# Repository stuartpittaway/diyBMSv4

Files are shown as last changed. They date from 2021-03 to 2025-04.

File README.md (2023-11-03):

# diyBMS v4

Version 4 of the diyBMS

Do it yourself battery management system for Lithium ion battery packs/cells

More discussion [Open Energy Monitor Forum](https://community.openenergymonitor.org/c/hardware/diybms/53)

If you are looking for version 3 (obsolete) of this project take a look [here](https://github.com/stuartpittaway/diyBMS)

THIS REPOSITORY CONTAINS THE HARDWARE FOR THE SYSTEM

# Videos on how to use and build

[YouTube playlist](https://youtube.com/playlist?list=PLHhwQCDPuRcZW3u0jJucsiCCsUbNbMy-c) for DIYBMS videos

[Building & ordering the PCB from JLCPCB](https://youtu.be/E1OS0ZOmOT8)

If you order a PCB, please use my affiliate link to help support this project [JLCPCB](https://jlcpcb.com/RSZ)

# Support

If you find the BMS useful, please consider buying me a beer, check out Patron for more information

https://patreon.com/StuartP

# HARDWARE

This repository contains the hardware designs, generally in KiCad format.  Unless you are changing the design, you don't need to use/install KiCad, just use the precompiled files.

The folder structure in the repository contains:

## Controller Designs
* ControllerCircuit - ESP32 controller board (newest design)
* ESP8266ControllerCircuit - [legacy] the circuit board for the legacy ESP8266 based controller

## Modules for Controller
* ModuleV490-AllInOne - Latest multi cell monitoring solution, recommended for 8 to 16S cell configurations.  No balancing, requires ModuleV490-PassiveBal passive balancer daughterboard if this is needed.
* ModuleV490-PassiveBal - daughter board for the V490 multi-cell monitoring solution, provides 200mA per cell balance current, heatsink and fan control.
* ModuleV450 - the latest SINGLE module design, using ATTINY1624 chip. Recommended for both hand soldering or mass production
* ModuleV440 - [legacy] the module circuit board V4.40, final board using ATTINY841 chip
* ModuleV400 - [legacy] the module circuit board V4.00, designed for easier hand soldering (larger parts)
* ModuleV421 - [legacy] the module circuit board V4.21, designed for mass production using JLCPCB assembly service

If you use this coupon code when you place a JLCPCB order

JLC-Stuart

and this link

https://jlcpcb.com/RSZ

you will get a discount and I get a very small amount of credit for every 30 orders, which helps to support the cost of prototyping new designs and adding new features.

### ESP32 Controller 

The latest version of the controller uses an ESP32 and supports CANBUS, RS485, SD CARD logging, relays, SSR outputs, multiple inputs, AVR programmer and much more.

Although the hardware is complete, not all features are usable from the software, this will be developed and improved over time to make use of the hardware.

[Bill of Materials](./ControllerCircuit/ComponentListBOM.md)

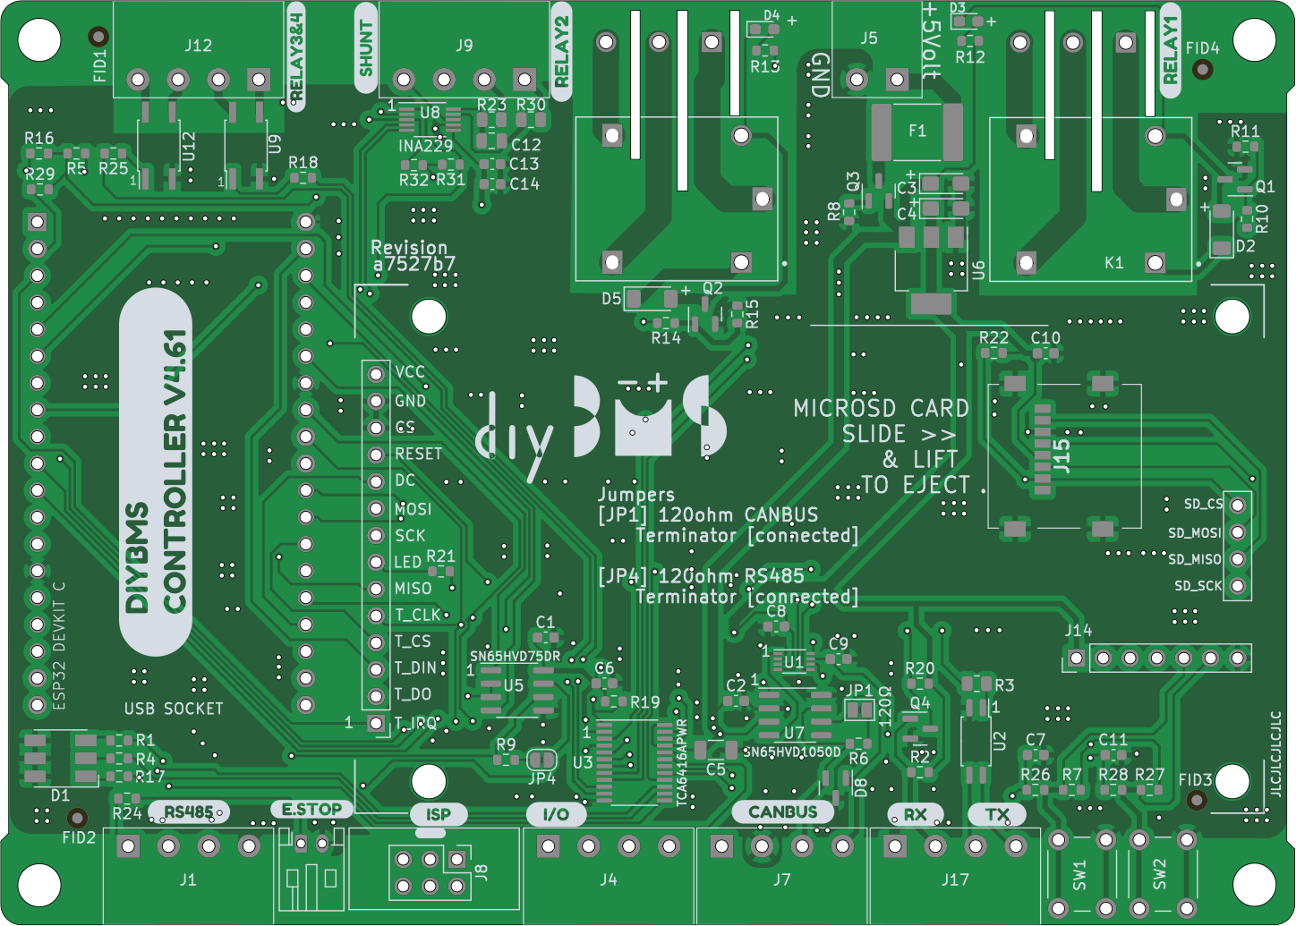
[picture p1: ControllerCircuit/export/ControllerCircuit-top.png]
circuit board


### Module V4.50

The latest version of the module hardware uses the ATTINY1624 chip - part of the tinyAVR2 range.

This board requires an UPDI programmer/device - see the instructions in the code repository for how to program the boards once built.

The parts are no smaller than 0805 size (about 2mm!) which is probably the smallest size you want to attempt to hand solder.

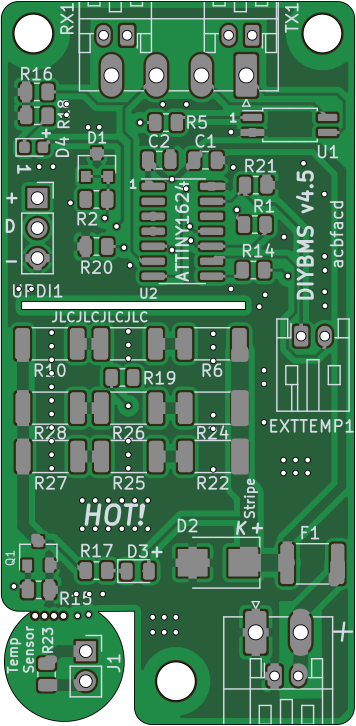
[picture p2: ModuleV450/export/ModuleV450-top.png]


Specifications are similar to the V4.40 board.

### Module V4.40

V4.40 is the last board to use the ATTINY841 chip - V4.50 is the newest design if you are starting fresh.

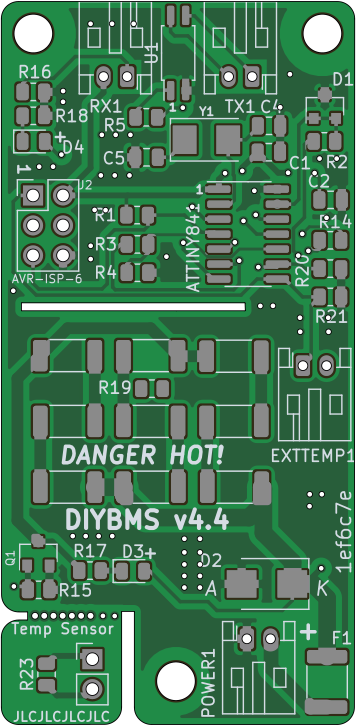
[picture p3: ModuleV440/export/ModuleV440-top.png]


In addition, the hardware has a higher balance current, fuse and TVS diode to help with voltage spikes.  
Most importantly, an external crystal has been added to the micro controller (attiny841) which means the device is more reliable in low voltage situations.

The balance current for V4.40 modules is as follows:
* 1.27A at 4.2V (5.35W)
* 1.21A at 4.0V (4.84W)
* 1.13A at 3.75V (4.26W)

The module is physically larger than previous modules, this aids heat dispersal but also features a "snap off" external temperature daughter board for use in cell temperature monitoring.

You will also need to order [these parts](./ModuleV440/HandAssemblyParts.md)

# CODE/SOFTWARE

Software and code for the modules and controller can now be found in a seperate repo

For the latest controller (ESP32)
[diyBMSv4ESP32](https://github.com/stuartpittaway/diyBMSv4ESP32)

For the legacy controller (ESP8266)
[diyBMSv4Code](https://github.com/stuartpittaway/diyBMSv4Code)

# WARNING

This is a DIY product/solution so don’t use this for safety critical systems or in any situation where there could be a risk to life.  

There is no warranty, it may not work as expected or at all.

The use of this project is done so entirely at your own risk.  It may involve electrical voltages which could kill - if in doubt, seek help.

The use of this project may not be compliant with local laws or regulations - if in doubt, seek help.

# License

This work is licensed under a Creative Commons Attribution-NonCommercial-ShareAlike 2.0 UK: England & Wales License.

https://creativecommons.org/licenses/by-nc-sa/2.0/uk/

You are free to:
* Share — copy and redistribute the material in any medium or format
* Adapt — remix, transform, and build upon the material
The licensor cannot revoke these freedoms as long as you follow the license terms.

Under the following terms:
* Attribution — You must give appropriate credit, provide a link to the license, and indicate if changes were made. You may do so in any reasonable manner, but not in any way that suggests the licensor endorses you or your use.
* Non-Commercial — You may not use the material for commercial purposes.
* ShareAlike — If you remix, transform, or build upon the material, you must distribute your contributions under the same license as the original.
* No additional restrictions — You may not apply legal terms or technological measures that legally restrict others from doing anything the license permits.

Notices:
You do not have to comply with the license for elements of the material in the public domain or where your use is permitted by an applicable exception or limitation.

No warranties are given. The license may not give you all of the permissions necessary for your intended use. For example, other rights such as publicity, privacy, or moral rights may limit how you use the material.

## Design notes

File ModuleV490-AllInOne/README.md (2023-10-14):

# DIYBMS All-in-one 16S monitoring board

This is the hardware for the (up to) 16S monitoring board.

This monitoring board replaces the individual cell monitoring boards used in the DIYBMS solution.  Several monitoring boards can be daisy-chained together to form larger battery packs.

You still require a DIYBMS ESP32 controller for this board to operate.

It uses an [STM32F030K6T6](https://www.st.com/en/microcontrollers-microprocessors/stm32f030k6.html) chip, with 32K flash and 4K RAM.

**WARNING**: This hardware is considered experimental & prototype, use at your own risk - it may not work as intended or at all.

## Background Information
### Software
The software for this board is available pre-compiled.  See this [link for details](https://github.com/stuartpittaway/diyBMSv4ESP32/tree/all-in-one/STM32All-In-One#readme)

Details are in the README on programming the STM32 chip for this PCB.

### KiCAD 7
This design uses KiCAD version 7.0.5.  Use the same or newer version for editing and viewing the files.  You don't need to install KiCAD if you just wish to build/order one.

### JLCPCB
The files in this repository will create a PCB and design files suitable for "almost" full construction at JLCPCB.  Some manual soldering will still be required for the connectors and cabling.

Look inside the "export" folder for the relevant production files.  You will need these files for the construction:

* module_16s_gerbers.zip
* Module_16S_bom_jlc.csv
* Module_16S_cpl_jlc.csv

Support this project by using JLCPCB referral link
https://jlcpcb.com/RSZ
when registering for the first time.

# READ THIS FIRST - IMPORTANT

Before construction of the PCB you must determine what battery cells you wish to monitor and a suitable cell voltage range.

The PCB design has options for two voltage ranges, determined by parts U2 and U6.  *ONLY ONE OF THESE CHIPS MUST BE FITTED*

The design uses a MAX14921 chip, this has a maximum of 16 cells and **65V** total battery voltage - do not exceed.

## LIFEPO4 cells up to 4.00V maximum

Use part U2, a Microchip voltage reference "MCP1501-40E/SN".  This is a 4.096V ±0.1% reference chip.

This part is available on JLCPCB as part number C1575589.

The pick and place file (CPL file) contains the part placement for this chip by default.  No further changes are required, except to double-check the order screens from JLCPCB.

Do not install part U6.

*This option has been tested by the author as working*

## Cell voltages up to 4.50V maximum

This is all 18650 style cell voltage chemistry - normally with a maximum of 4.25V.  This configuration can also be used with LIFEPO4 cells with voltages below 4.50V.

Use part U6, a Microchip voltage reference "MCP1502T-45E/CHY".   This is a 4.500V ±0.1% reference chip.

This part is NOT available from JLCPCB.  This part must be obtained from [other sources](https://www.digikey.co.uk/en/products/detail/microchip-technology/MCP1502T-45E-CHY/16549208) and **MANUALLY** soldered onto the board.  Note this is a very small chip (SOT-23-6) and difficult to solder.

Edit the pick and place (CPL file) before upload to JLCPCB to remove the line marked "U2".

Do not install part U2.

*This option has NOT been tested by the author, please feedback if you decide to experiment*

## BATTERY VOLTAGES ABOVE 24V & MINIMUM BELOW 12V

If you have an unusual Lithium cell chemistry where the maximum battery voltage is ABOVE 24V and the lowest is BELOW 12V, this monitoring board is not suitable.

## BATTERY VOLTAGES BELOW 13V (MINIMUM)

If you are building a battery whos voltage can go BELOW 13V, which typically includes 4S or 5S cell configurations.  

For example, 4S LIFEPO4 setup voltage range: 4x2.5V= 10V minimum, 4x3.65V=14.6V maximum.

Parts of the BMS circuit are not required for a battery's whos voltage can go below 13V and **must** be ommitted.  These parts operate the step-down regulator normally required for higher voltages, such as an 8S or 16S setup.   The regulator will fail to operate with an input voltage below 13V - causing the whole board to stop responding.

Ensure that the battery will not go above 24V during charging cycles.  Damage to the voltage regulator will occur if this occurs.

In this configuration, you do not require, and *MUST* not fit:

* U10 - XL7005A
* L1
* D21
* R76
* R77
* C44
* C43
* C45
* JP1/PWR 2 pin header

*Edit the pick and place and BOM files to remove any reference to the above parts, before ordering from JLCPCB*

Once these parts are removed, the board must **NEVER** be used with a battery over 24V or damage will occur.

You may want to consider fitting a smaller connector (J7) such [as this one](https://www.lcsc.com/product-detail/Pluggable-System-Terminal-Block_Ningbo-Kangnex-Elec-WJ15EDGRC-3-81-6P_C7246.html) to prevent mistakes being made.  If you do this, you will also need to add a wire between pin 6 and pin 17 of J7 on the PCB, to ensure the MAX chip receives power.

Once the board is constructed, a wire link between J9 and pin 2  (indicated by square box on silkscreen) of JP1/PWR should be made.  This connects the full battery voltage to the board and bypasses the step down circuit.

In this configuration test point "TP1" will be zero volt/not connected.

After these changes are made, if the FAN is used on the passive balancer board, this must be changed to align to the voltage of the battery - a 12V fan may no longer be suitable for example, if running at 14.6V (4S setup).

*This option has been tested by the author and confirmed working*

## PASSIVE BALANCE BOARD

The passive balance PCB is part of a seperate project folder named "ModuleV490-PassiveBal".

If you have no requirement for the passive balance board (its optional) then you can also omit the two headers marked J14 and J15 (both 22 pin) from this PCB.

## EXTERNAL TEMPERATURE SENSOR BOARD

The external temperature sensor PCB is part of a seperate project folder named "TemperaturePCB".

If you already have previous v4.50 DIYBMS monitoring boards, the same temperature sensor can be used with this design.

# CONNECTING THE ALL-IN-ONE MONITORING BOARD

Cell voltage connections are made using plugable terminal blocks.  A large 17 pin connector is connected to the most negative cell terminal, and then every positive connection to the other cells in the battery.

Ensure that you have the correct sequence of cell voltages before connecting to the BMS.  Test the pins on the plug with a multimeter to ensure the voltage continualy increases as you move up the pins (when compared to negative pin).

If you are using less than 16 cells, use wire connections between the screw terminals to link the highest cell to the remaining terminals.  For example, a 14S setup, would need a wire link between terminals 14 to 15 and 15 to 16.

The two pin plug is used to power the BMS.  This needs to be connected to the negative and positive of the battery.  Note the correct orientation of the two pins, the positive is near the edge of the board.  The silkscreen on the bottom of the PCB has the details.

Communication interface to the DIYBMS controller is via the 4 pin connector - ensure pin out is correct before connecting to the controller or damage may occur.

Important:
* Do not reverse polarity.
* Connect the 17 pin connector FIRST before connecting the power connector.
* Ensure the PRG/RUN jumper is in the RUN position for normal operation.  You will need to power cycle the board after changing modes.
* Ensure the PWR jumper is connected (except <13V setups see above).
* If the LED flashes a sequence on start up, check the software README to determine the cause
* Ensure communication interface to controller uses correct wiring orientation

# FAULT FINDING

## All cells read similar voltage (4.096V or 4.500V)

This indicates that the voltage reference is not reaching the ADC chip MCP33151.  Therefore, check voltage on TP5 and also soldering around U3 and U2/U6 depending on the V reference fitted.

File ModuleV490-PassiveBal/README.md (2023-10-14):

# DIYBMS All-in-one 16S PASSIVE BALANCE BOARD

This is the hardware for the PASSIVE BALANCE BOARD add-on to the all in one monitoring solution.

**WARNING**: This hardware is considered experimental & prototype, use at your own risk - it may not work as intended or at all.

### KiCAD 7
This design uses KiCAD version 7.0.5.  Use the same or newer version for editing and viewing the files.  You don't need to install KiCAD if you just wish to build one.

### JLCPCB
This design will create a PCB and design files suitable for "almost" full construction at JLCPCB.  Some manual soldering will still be required for the connectors and cabling.

Look inside the "export" folder for the relevant production files.  You will need these files for the construction:

* module_16s_passive_gerbers.zip
* module_16s_passive_bom_jlc.csv
* module_16s_passive_cpl_jlc.csv

Support this project by using JLCPCB referral link
https://jlcpcb.com/RSZ
when registering for the first time.

# FAN

The fan is 40x40mm, 12V.  The current must be less than 150mA (0.15A).

A suitable fan is this one... 
[40mm 12V FAN](https://www.kenable.co.uk/en/peripherals/fans-cooling-devices/case-fans-other/7063-pc-case-cooling-fan-40mm-x-40mm-x-10mm-12v-012a-sleeve-bearing-10cm-007063-5055383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)

You will need to replace the power connector with a 2 pin JST PH style plug.  Cut the yellow wire off, this is not used.

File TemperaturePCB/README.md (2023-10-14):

# DIYBMS TEMPERATURE SENSOR BOARD

This is the hardware for a TEMPERATURE SENSOR BOARD.  This works with the all-in-one and v450 modules.

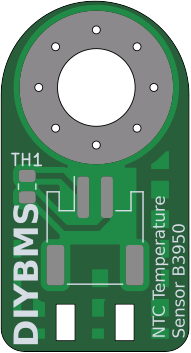
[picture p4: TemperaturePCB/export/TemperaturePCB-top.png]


### KiCAD 7
This design uses KiCAD version 7.0.5.  Use the same or newer version for editing and viewing the files.  You don't need to install KiCAD if you just wish to build one.

### JLCPCB
This design will create a PCB and design files suitable for "almost" full construction at JLCPCB.  Some manual soldering will still be required for the connectors and cabling.

Look inside the "export" folder for the relevant production files.
Support this project by using JLCPCB referral link
https://jlcpcb.com/RSZ
when registering for the first time.

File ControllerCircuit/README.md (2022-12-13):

# diyBMS v4

This is the latest version of the diyBMS controller

THIS REPOSITORY CONTAINS THE HARDWARE FOR THE SYSTEM

## ESP32 Controller 

The latest version of the controller uses an ESP32 and supports CANBUS, RS485, SD CARD logging, relays, SSR outputs, multiple inputs, AVR programmer and much more.

Although the hardware is complete, not all features are usable from the software, this will be developed and improved over time to make use of the hardware.

[Bill of Materials](https://github.com/stuartpittaway/diyBMSv4/blob/master/ControllerCircuit/ComponentListBOM.md)

# Videos on how to use and build

[YouTube playlist](https://youtube.com/playlist?list=PLHhwQCDPuRcZW3u0jJucsiCCsUbNbMy-c) for DIYBMS videos

[Building & ordering the PCB from JLCPCB](https://youtu.be/E1OS0ZOmOT8)

# Support

If you find the BMS useful, please consider buying me a beer, check out Patron for more information

https://patreon.com/StuartP

# Ordering From JLCPCB

If you use this coupon code when you place a JLCPCB order

JLC-Stuart

and this link

https://jlcpcb.com/RSZ

you will get a discount and I get a very small amount of credit for every 30 orders, which helps to support the cost of prototyping new designs and adding new features.

# WARNING

This is a DIY product/solution so don’t use this for safety critical systems or in any situation where there could be a risk to life.  

There is no warranty, it may not work as expected or at all.

The use of this project is done so entirely at your own risk.  It may involve electrical voltages which could kill - if in doubt, seek help.

The use of this project may not be compliant with local laws or regulations - if in doubt, seek help.

# License

This work is licensed under a Creative Commons Attribution-NonCommercial-ShareAlike 2.0 UK: England & Wales License.

https://creativecommons.org/licenses/by-nc-sa/2.0/uk/

You are free to:
* Share — copy and redistribute the material in any medium or format
* Adapt — remix, transform, and build upon the material
The licensor cannot revoke these freedoms as long as you follow the license terms.

Under the following terms:
* Attribution — You must give appropriate credit, provide a link to the license, and indicate if changes were made. You may do so in any reasonable manner, but not in any way that suggests the licensor endorses you or your use.
* Non-Commercial — You may not use the material for commercial purposes.
* ShareAlike — If you remix, transform, or build upon the material, you must distribute your contributions under the same license as the original.
* No additional restrictions — You may not apply legal terms or technological measures that legally restrict others from doing anything the license permits.

Notices:
You do not have to comply with the license for elements of the material in the public domain or where your use is permitted by an applicable exception or limitation.

No warranties are given. The license may not give you all of the permissions necessary for your intended use. For example, other rights such as publicity, privacy, or moral rights may limit how you use the material.

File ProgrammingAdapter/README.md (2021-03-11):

# Programming Adapter AVR/ISP

Note this is a simple PCB which connects the 6 pin ISP header to a 6 pin ISP header (straight through)

It is often simpler to use a ribbon cable and two 6 pin plugs!

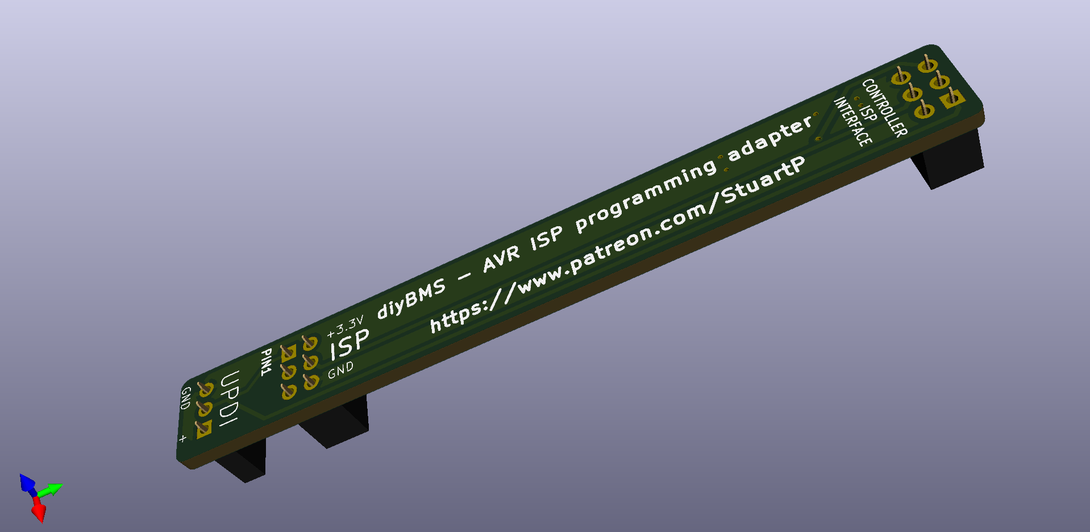
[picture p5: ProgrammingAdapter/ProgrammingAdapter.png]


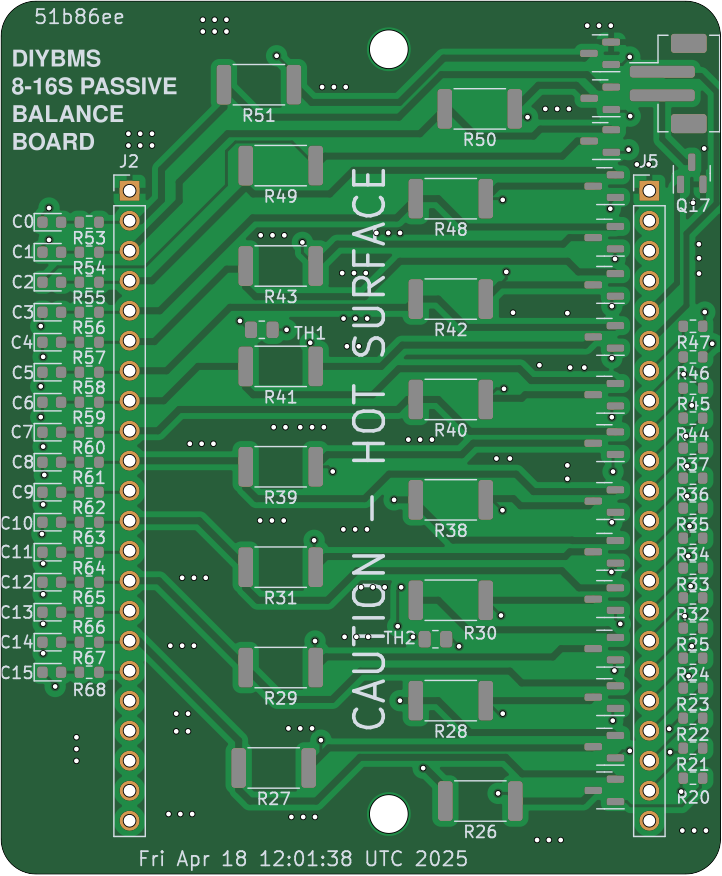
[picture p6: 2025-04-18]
ModuleV490-PassiveBal/export/Module_16S_PassiveBalanceAddOn-top.png

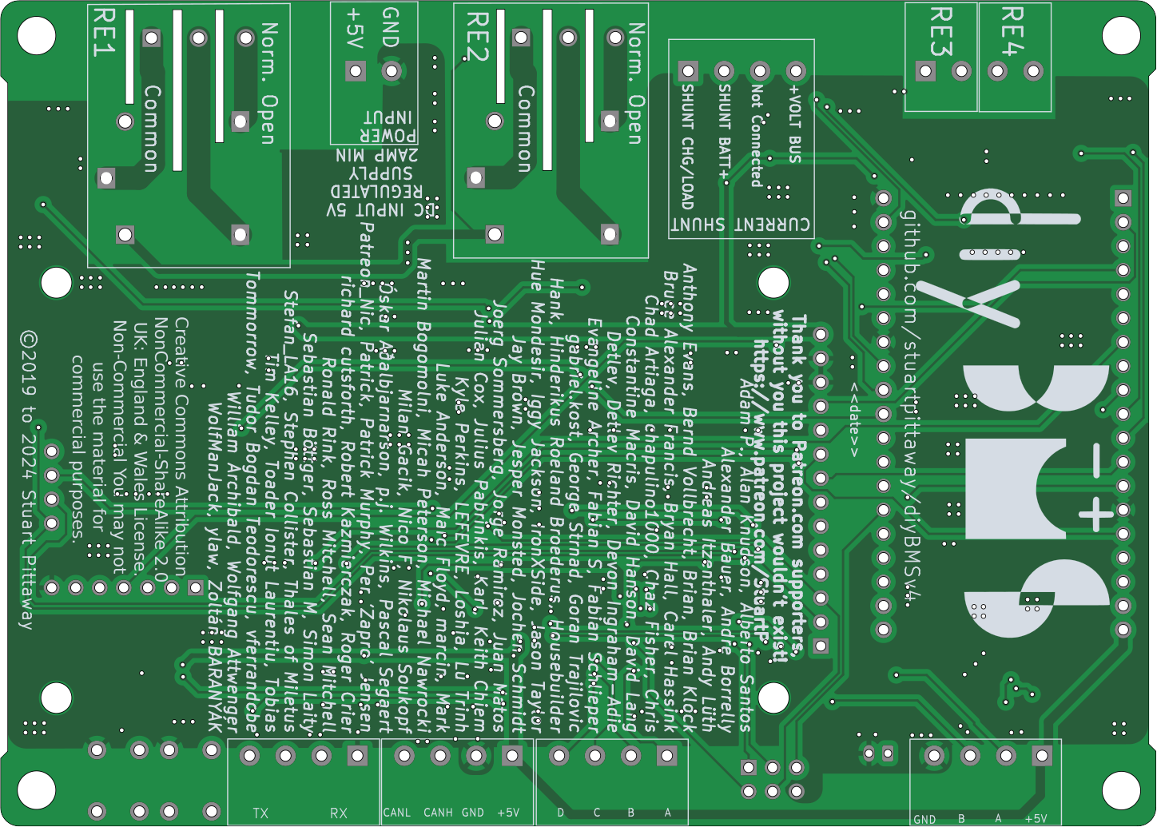
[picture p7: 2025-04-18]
ControllerCircuit/export/ControllerCircuit-bottom.png

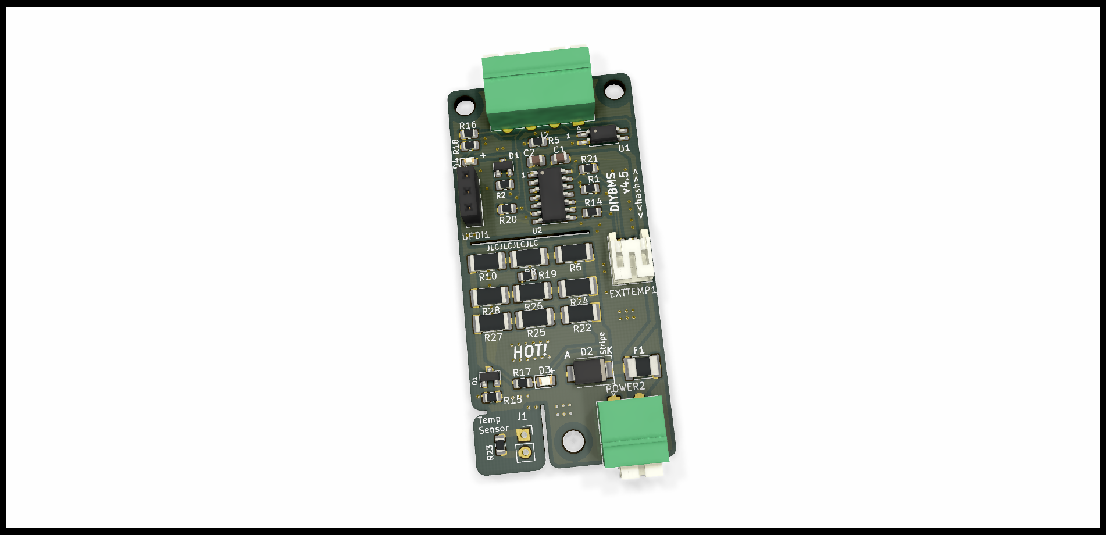
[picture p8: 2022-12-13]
ModuleV450/ModuleV450.png

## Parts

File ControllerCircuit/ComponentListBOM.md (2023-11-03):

# ESP controller and TFT screen

## BANG GOOD 
(affiliate links)
2.8 Inch ILI9341 240x320 SPI TFT LCD Display Touch
https://www.banggood.com/custlink/mmmRI7iYr3

## Amazon 
(affiliate links)
ESP32 DEVKITC (pack of 3)
https://amzn.to/3bFOaah

ESP32 DEVKITC (single board)
https://amzn.to/3qG3YOG

## JLCPCB
(affiliate links)
https://jlcpcb.com/RSZ

# Surface Mount Component List

These parts are necessary for the DIYBMS CONTROLLER
| Item | Qty | Reference(s) | Value | LibPart | Footprint | Datasheet | Arrow Part Number | Arrow Price/Stock | DONOTPLACE | Description | Field4 | Height | JLCPCBRotation | LCSCStockCode | Manufacturer_Name | Manufacturer_Part_Number | Mouser Part Number | Mouser Price/Stock | PartNumber |
| ---- | --- | --- | ----- | --- | --- | --- | --- | --- | --- | --- | --- | --- | --- | --- | --- | --- | --- | --- | --- |
| 1 | 6 | C1, C2, C6, C8, C9, C14 | 100nF | Device:C | Capacitor_SMD:C_0805_2012Metric | https://datasheet.lcsc.com/szlcsc/YAGEO-CC0805KRX7R9BB104_C49678.pdf |  |  |  |  |  |  |  | C49678 |  |  |  |  | CC0805KRX7R9BB104 |
| 2 | 2 | C3, C4 | 22uF 6.3V | Device:C | Capacitor_Tantalum_SMD:CP_EIA-3216-18_Kemet-A_Pad1.58x1.35mm_HandSolder | https://datasheet.lcsc.com/szlcsc/Hunan-Xiangyee-in-S-T-CA45-A010M226T_C126948.pdf |  |  |  |  |  |  |  | C110786 |  |  |  |  | TC212A226K006Y |
| 3 | 1 | C5 | 22uF | Device:C | Capacitor_SMD:C_1206_3216Metric |  |  |  |  |  |  |  |  | C5672 |  |  |  |  | CL31A226KPHNNNE |
| 4 | 4 | C7, C10, C11, C13 | 1uF | Device:C | Capacitor_SMD:C_0805_2012Metric |  |  |  |  |  |  |  |  | C28323 |  |  |  |  | CL21B105KBFNNNE |
| 5 | 1 | C12 | 0.1uF-100V | Device:C | Capacitor_SMD:C_0805_2012Metric |  |  |  |  |  |  |  |  | C696367 |  |  |  |  | C0805C104K1RECAUTO |
| 6 | 1 | D1 | RGB | Device:LED_RGB | LED_SMD:LED_RGB_5050-6 | https://datasheet.lcsc.com/szlcsc/Hongli-Zhihui-HONGLITRONIC-HL-AF-5060H271BU46FU79GC-S1-THL_C219409.pdf |  |  |  |  |  |  |  | C219409 |  |  |  |  |  |
| 7 | 2 | D2, D5 | LL4148 | Device:D | Diode_SMD:D_MiniMELF | https://datasheet.lcsc.com/szlcsc/Semtech-LL4148_C9808.pdf |  |  |  |  |  |  |  | C9808 |  |  |  |  | LL4148 |
| 8 | 2 | D3, D4 | YELLOW LED | Device:LED | LED_SMD:LED_0603_1608Metric_Pad1.05x0.95mm_HandSolder |  |  |  |  |  |  |  |  | C72038 |  |  |  |  |  |
| 10 | 1 | D8 | NUP2105LT1G | Power_Protection:NUP2105L | Package_TO_SOT_SMD:SOT-23 | http://www.onsemi.com/pub_link/Collateral/NUP2105L-D.PDF |  |  |  |  |  |  |  | C2976509 |  |  |  |  |  |
| 11 | 1 | F1 | Fuse, 1.85A | Device:Polyfuse | Fuse:Fuse_2920_7451Metric | https://datasheet.lcsc.com/szlcsc/TLC-Electronic-TLC-LSMD185_C262041.pdf |  |  |  |  |  |  |  | C262041 |  |  |  |  | TLC-LSMD185 |
| 19 | 1 | J15 | Molex 0472192001 | 0472192001:0472192001 | 0472192001 | https://www.molex.com/pdm_docs/sd/472192001_sd.pdf | 0472192001 | https://www.arrow.com/en/products/0472192001/molex |  | Memory Card Connectors 1.10MM MICRO SD 08P HINGE TYPE |  | 1.9 | 180 | C164170 | Molex | 0472192001 | N/A | https://www.mouser.com/Search/Refine.aspx?Keyword=N%2FA |  |
| 24 | 2 | Q1, Q2 | AO3400A | Device:Q_NMOS_GSD | Package_TO_SOT_SMD:SOT-23 | https://datasheet.lcsc.com/szlcsc/1812111733_Bourne-Semicon-Shenzhen-AO3400A_C344010.pdf |  |  |  |  |  |  |  | C344010 |  |  |  |  | AO3400A |
| 25 | 1 | Q3 | AO3401A | Transistor_FET:AO3401A | Package_TO_SOT_SMD:SOT-23 | https://datasheet.lcsc.com/szlcsc/Alpha-Omega-Semicon-AOS-AO3401A_C15127.pdf |  |  |  |  |  |  |  | C15127 |  |  |  |  |  |
| 26 | 1 | Q4 | AO3400A | Transistor_FET:AO3400A | Package_TO_SOT_SMD:SOT-23 | http://www.aosmd.com/pdfs/datasheet/AO3400A.pdf |  |  |  |  |  |  |  | C344010 |  |  |  |  | AO3400A |
| 27 | 5 | R1, R17, R18, R21, R25 | 220R | Device:R | Resistor_SMD:R_0805_2012Metric | ~ |  |  |  |  |  |  |  | C17557 |  |  |  |  | 0805W8F2200T5E |
| 28 | 3 | R2, R5, R16 | 2K2 | Device:R | Resistor_SMD:R_0805_2012Metric | ~ |  |  |  |  |  |  |  | C17520 |  |  |  |  | 0805W8F2201T5E |
| 29 | 1 | R3 | 180R | Device:R | Resistor_SMD:R_0805_2012Metric | ~ |  |  |  |  |  |  |  | C25270 |  |  |  |  | 0805W8F1800T5E |
| 30 | 5 | R4, R10, R12, R13, R14 | 560R | Device:R | Resistor_SMD:R_0805_2012Metric | ~ |  |  |  |  |  |  |  | C28636 |  |  |  |  | 0805W8F5600T5E |
| 31 | 3 | R6, R8, R9 | 120R | Device:R | Resistor_SMD:R_0805_2012Metric | ~ |  |  |  |  |  |  |  | C17437 |  |  |  |  | 0805W8F1200T5E |
| 32 | 4 | R7, R11, R15, R27 | 51K | Device:R | Resistor_SMD:R_0805_2012Metric | ~ |  |  |  |  |  |  |  | C17737 |  |  |  |  | 0805W8F5102T5E |
| 33 | 5 | R19, R22, R29, R31, R32 | 10K | Device:R | Resistor_SMD:R_0805_2012Metric | ~ |  |  |  |  |  |  |  | C17414 |  |  |  |  | 0805W8F1002T5E |
| 34 | 1 | R20 | 1M | Device:R | Resistor_SMD:R_0805_2012Metric | ~ |  |  |  |  |  |  |  | C17514 |  |  |  |  | 0805W8F1004T5E |
| 35 | 2 | R23, R30 | 10R | Device:R | Resistor_SMD:R_0805_2012Metric | ~ |  |  |  |  |  |  |  | C17415 |  |  |  |  | 0805W8F100JT5E |
| 36 | 3 | R24, R26, R28 | 22K | Device:R | Resistor_SMD:R_0805_2012Metric | ~ |  |  |  |  |  |  |  | C17560 |  |  |  |  | 0805W8F2202T5E |
| 40 | 1 | U1 | TXS0102DCU | Logic_LevelTranslator:TXS0102DCU | Package_SO:VSSOP-8_2.3x2mm_P0.5mm | http://www.ti.com/lit/gpn/txs0102 |  |  |  |  |  |  |  | C53434 |  |  |  |  |  |
| 41 | 1 | U2 | EL3H7(B)(TA)-G | Isolator:PC817 | Package_SO:SOP-4_4.4x2.6mm_P1.27mm | https://datasheet.lcsc.com/szlcsc/Everlight-Elec-EL3H7-B-TA-G_C32565.pdf |  |  |  |  |  |  |  | C32565 |  |  |  |  |  |
| 42 | 1 | U3 | TCA6416APWR | ControllerCircuit:TCA6416APWR | Package_SO:TSSOP-24_4.4x7.8mm_P0.65mm | https://www.ti.com/lit/gpn/TCA6416A |  |  |  |  |  |  |  | C130203 |  |  |  |  |  |
| 44 | 1 | U5 | SN65HVD75DR | ControllerCircuit-rescue:SN65HVD75DR-ControllerCircuit | Package_SO:SOIC-8_3.9x4.9mm_P1.27mm | https://www.ti.com/store/ti/en/p/product/?p=SN65HVD75DR |  |  |  |  |  |  |  | C57928 |  |  |  |  | SN65HVD75DR |
| 45 | 1 | U6 | AMS1117-3.3 | Regulator_Linear:AMS1117-3.3 | Package_TO_SOT_SMD:SOT-223-3_TabPin2 | http://www.advanced-monolithic.com/pdf/ds1117.pdf |  |  |  |  |  |  |  | C6186 |  |  |  |  | AMS1117-3.3 |
| 46 | 1 | U7 | SN65HVD1050D | Interface_CAN_LIN:SN65HVD1050D | Package_SO:SOIC-8_3.9x4.9mm_P1.27mm | http://www.ti.com/lit/ds/symlink/sn65hvd1050.pdf |  |  |  |  |  |  |  | C14019 |  |  |  |  |  |
| 47 | 1 | U8 | INA229 | ControllerCircuit-rescue:INA229-Q1-INA229-Q1 | Package_SO:VSSOP-10_3x3mm_P0.5mm | https://www.ti.com/lit/ds/symlink/ina229-q1.pdf |  |  |  |  |  |  |  | C2846803 |  |  |  |  | INA229AIDGSR |
| 48 | 2 | U9, U12 | AQY282SX | Relay_SolidState:ASSR-1218 | Package_SO:SO-4_4.4x3.6mm_P2.54mm | https://datasheet.lcsc.com/lcsc/1912111437_PANASONIC-AQY282SX_C250827.pdf |  |  |  |  |  |  |  | C250827 |  |  |  |  |  |

# Through Hole Component List
| Item | Qty | Reference(s) | Value | LibPart | Footprint | Datasheet | Arrow Part Number | Arrow Price/Stock | DONOTPLACE | Description | Field4 | Height | JLCPCBRotation | LCSCStockCode | Manufacturer_Name | Manufacturer_Part_Number | Mouser Part Number | Mouser Price/Stock | PartNumber |
| --- | --- | --- | --- | --- | --- | --- | --- | --- | --- | --- | --- | --- | --- | --- | --- | --- | --- | --- | --- |
| 12 | 4 | J1, J4, J7, J12 | ScrewTerminal | Connector:Conn_01x04_Female | ControllerCircuit:Terminal-Block_3.81_4P_LCSC_C395880 | ~ |  |  |  |  |  |  |  | C395880 |  |  |  |  |  |
| 13 | 2 | J2, J3 | ScrewTerminal3Pin | Connector:Conn_01x03_Female | ControllerCircuit:Terminal-Block_5.0mm_3P-LCSC_C395850 | ~ |  |  |  |  |  |  |  | C395850 |  |  |  |  |  |
| 14 | 1 | J5 | ScrewTerminal | Connector:Conn_01x02_Female | ControllerCircuit:Terminal-Block_3.81_2P-LCSC_C395878 | ~ |  |  |  |  |  |  |  | C395878 |  |  |  |  |  |
| 15 | 1 | J8 | 2x3 2.54mm IDC Connectors | Connector:AVR-ISP-6 | Connector_PinHeader_2.54mm:PinHeader_2x03_P2.54mm_Vertical | https://lcsc.com/product-detail/IDC-Connectors_Ckmtw-Shenzhen-Cankemeng-C132438_C132438.html |  |  |  |  |  |  |  | C132438 |  |  |  |  |  |
| 16 | 1 | J9 | Shunt | Connector:Conn_01x04_Female | ControllerCircuit:Terminal-Block_3.81_4P_LCSC_C395880 | ~ |  |  |  |  |  |  |  | C395880 |  |  |  |  |  |
| 17 | 1 | J10 | Conn_01x02_Female | Connector:Conn_01x02_Female | Connector_PinHeader_2.54mm:PinHeader_1x02_P2.54mm_Horizontal | ~ |  |  |  |  |  |  |  | C376120 |  |  |  |  |  |
| 22 | 2 | K1, K2 | SRD-05VDC-SL-C | ControllerCircuit-rescue:SRD-05VDC-SL-C-ControllerCircuit | ControllerCircuit:RELAY_SRD-05VDC-SL-C | https://datasheet.lcsc.com/szlcsc/1811021933_Ningbo-Songle-Relay-SRD-05VDC-SL-C_C35449.pdf |  |  |  |  | SONGLE RELAY |  |  | C35449 |  |  |  |  | SRD-05VDC-SL-C |
| 23 | 1 | LCD1 | LCD | ControllerCircuit-rescue:LCD-ControllerCircuit | ControllerCircuit:TFTSPI_2_8_240x320_TOUCH |  |  |  |  |  |  |  |  | C52711/C358718 |  |  |  |  |  |
| 37 | 1 | RX1 | Receive | Connector:Conn_01x02_Male | Connector_JST:JST_PH_S2B-PH-K_1x02_P2.00mm_Horizontal |  |  |  |  |  |  |  |  | C157932 |  |  |  |  | S2B-PH-K-S-GW |
| 38 | 2 | SW1, SW2 | SW_Push | Switch:SW_Push | Button_Switch_THT:SW_PUSH_6mm_H5mm | ~ |  |  |  |  |  |  |  | C455101 |  |  |  |  | XUNPU TS-1002-10026 |
| 39 | 1 | TX1 | Transmit | Connector:Conn_01x02_Male | Connector_JST:JST_PH_S2B-PH-K_1x02_P2.00mm_Horizontal |  |  |  |  |  |  |  |  | C157932 |  |  |  |  | S2B-PH-K-S-GW |
| 43 | 1 | U4 | ESP32-DEVKITC-32D | ControllerCircuit-rescue:ESP32-DEVKITC-32D-ControllerCircuit | ControllerCircuit:MODULE_ESP32-DEVKITC-32D | Espressif Systems |  |  |  |  | 4 |  |  | C319202/C319202 |  |  |  |  |  |

# "Do not place" items

These parts are on the circuit diagram, but are not required.  Do not place/purchase these parts.

| Item | Qty | Reference(s) | Value | LibPart | Footprint | Datasheet | Arrow Part Number | Arrow Price/Stock | DONOTPLACE | Description | Field4 | Height | JLCPCBRotation | LCSCStockCode | Manufacturer_Name | Manufacturer_Part_Number | Mouser Part Number | Mouser Price/Stock | PartNumber |
| ---- | --- | --- | --- | --- | --- | --- | --- | --- | --- | --- | --- | --- | --- | --- | --- | --- | --- | --- | --- |
| | | D6 | MHPC3528CRGBCT | Device:LED_RGBC | ControllerCircuit:LED_MHPC3528CRGBCT | https://datasheet.lcsc.com/lcsc/2202141600_MEIHUA-MHPC3528CRGBCT_C2962096.pdf | | | | | | | | | | | | | |

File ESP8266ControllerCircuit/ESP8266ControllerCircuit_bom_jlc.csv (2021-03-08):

Comment | Designator | Footprint | LCSC Part #
COMMS | D1 | LED_0805 | C2297
470R | R1 | R_0805_HandSoldering | C17710
2K2 | R2 | R_0805_HandSoldering | C17520
220R | R3 | R_0805_HandSoldering | C17557
4K7 | R4,R5 | R_0805_HandSoldering | C17673
EL3H7(B)(TA)-G | U2 | SOP-4_4.4x2.8mm_Pitch1.27mm | C32565
PCF8574T/3,518 | U3 | SOIC-16W_7.5x10.3mm_Pitch1.27mm | C7605

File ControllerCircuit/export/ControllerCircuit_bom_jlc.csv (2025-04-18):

Comment | Designator | Footprint | LCSC Part #
100nF | C1,C2,C6,C8,C9,C14 | C_0603_1608Metric | C14663
1uF | C7,C10,C11,C13 | C_0603_1608Metric | C15849
22uF 6.3V | C3,C4 | CP_EIA-3216-18_Kemet-A_Pad1.58x1.35mm_HandSolder | C110786
22uF | C5 | C_1206_3216Metric | C5672
0.1uF-100V | C12 | C_0805_2012Metric | C696367
LL4148 | D2,D5 | D_MiniMELF | C181117
NUP2105LT1G | D8 | SOT-23 | C2976509
RGB | D1 | LED_RGB_5050-6 | C219409
YELLOW LED | D3,D4 | LED_0603_1608Metric_Pad1.05x0.95mm_HandSolder | C72038
Fuse, 3A | F1 | Fuse_2920_7451Metric | C426964
14PinSocket | J13 |  | C2905420
19PinSocket | J6,J11 |  | C2932678
2x3 2.54mm IDC Connectors | J8 | PinHeader_2x03_P2.54mm_Vertical | C132438
4PinBlock | J1,J4,J7,J9,J12,J17 | WJ15EDGRC-3.81-4P | C395880
4PinSocket | J16 |  | C2905415
ESTOP | J10 | JST_PH_S2B-PH-K_1x02_P2.00mm_Horizontal | C157932
Molex 0472192001 | J15 | 0472192001 | C164170
ScrewTerminal | J5 | WJ15EDGRC-3.81-2P | C8387
ScrewTerminal3Pin | J2,J3 | Terminal-Block_5.0mm_3P-LCSC_C395850 | C395850
SRD-05VDC-SL-C | K1,K2 | RELAY_SRD-05VDC-SL-C | C35449
LCD | LCD1 | TFTSPI_2_8_240x320_TOUCH
AO3400A | Q1,Q2 | SOT-23 | C344010
AO3400A | Q4 | SOT-23 | C344010
AO3401A | Q3 | SOT-23 | C15127
10R | R23,R30 | R_0805_2012Metric | C17415
120R | R6,R8,R9 | R_0603_1608Metric | C22787
180R | R3 | R_0805_2012Metric | C25270
220R | R1,R17,R18,R21,R25 | R_0603_1608Metric | C22962
560R | R4,R10,R12,R13,R14 | R_0603_1608Metric | C23204
2K2 | R2,R5,R16 | R_0603_1608Metric | C4190
10K | R19,R22,R29,R31,R32 | R_0603_1608Metric | C25804
22K | R24,R26,R28 | R_0603_1608Metric | C31850
51K | R7,R11,R15,R27 | R_0603_1608Metric | C23196
1M | R20 | R_0603_1608Metric | C22935
SW_Push | SW1,SW2 | SW_PUSH_6mm_H5mm | C455101
AMS1117-3.3 | U6 | SOT-223-3_TabPin2 | C6186
EL3H7(B)(TA)-G | U2 | SOP-4_4.4x2.6mm_P1.27mm | C32565
ESP32-DEVKITC-32D | U4 | MODULE_ESP32-DEVKITC-32D
INA229 | U8 | VSSOP-10_3x3mm_P0.5mm | C2846803
LT219-1 | U9,U12 | SO-4_4.4x3.6mm_P2.54mm | C2691601
SN65HVD1050D | U7 | SOIC-8_3.9x4.9mm_P1.27mm | C14019
SN65HVD75DR | U5 | SOIC-8_3.9x4.9mm_P1.27mm | C57928
TCA6416APWR | U3 | TSSOP-24_4.4x7.8mm_P0.65mm | C130203
TXS0102DCU | U1 | VSSOP-8_2.3x2mm_P0.5mm | C53434

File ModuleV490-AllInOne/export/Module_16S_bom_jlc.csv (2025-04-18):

Comment | Designator | Footprint | LCSC Part #
14pF | C30,C31 | C_0402_1005Metric | C458857
100pF | C24 | C_0603_1608Metric | C14858
10nF | C34 | C_0603_1608Metric | C57112
33nF | C44 | C_0603_1608Metric | C113810
100nF 50V | C1,C22,C25,C28,C32,C35 | C_0603_1608Metric | C14663
100nF 100V | C2,C52 | C_0805_2012Metric | C28233
1uF | C3,C4,C5,C6,C7,C8,C9,C10,C11,C12,C13,C14,C15,C16,C17,C18,C19,C21,C29,C46,C47,C48,C49,C50 | C_0805_2012Metric | C28323
2.2uF | C27,C51 | C_0603_1608Metric | C23630
4.7uF | C33 | C_0603_1608Metric | C19666
10uF tantalum | C23 | CP_EIA-3216-18_Kemet-A | C7171
47uF 16V | C43,C45 | CP_Elec_5x5.4 | C3337
33uF 100V ±20% D10xL8.4mm | C20 | CP_Elec_10x7.9 | C486954
100V, 200mW Schottky diodes | D2 | D_SOD-123 | C83152
1N4002W | D20 | D_SOD-123F | C169542
68V, 500mW zener diode | D1 | D_SOD-123 | C242416
SS210 | D21 | D_SMA | C432298
White | D19 | LED_0603_1608Metric | C2290
Fuse 30mA | F1 | Fuse_0805_2012Metric | C19273358
BALANCE BOARD | J14,J15 | PinSocket_1x22_P2.54mm_Vertical | C2886702
CELL CONNECTOR | J7 | WJ15EDGRC-3.81-17P | C430372
POWER_IN | J5 | PhoenixContact_MC_1,5_2-G-3.81_1x02_P3.81mm_Horizontal | C8387
RELAY | J10,J11,J12,J13 | JST_PH_S2B-PH-SM4-TB_1x02-1MP_P2.00mm_Horizontal | C295747
TXRX | J8 | PhoenixContact_MC_1,5_4-G-3.81_1x04_P3.81mm_Horizontal | C7245
UART_PROG | J3,J4 | PinSocket_1x04_P2.54mm_Horizontal | C2897386
100uH | L1 | L_1008_2520Metric_Pad1.43x2.20mm_HandSolder | C286551
AO3401A | Q1 | SOT-23 | C15127
100R | R1,R52 | R_0603_1608Metric | C22775
330R | R21,R78,R87 | R_0603_1608Metric | C23138
2K2 | R79 | R_0603_1608Metric | C4190
3K3 1% | R2,R3,R4,R5,R6,R7,R8,R9,R10,R11,R12,R13,R14,R15,R16,R17,R75 | R_0603_1608Metric | C22978
4.99kΩ 1% | R77 | R_0603_1608Metric | C23046
10K 1% | R20,R69,R70,R73,R74,R80,R84,R85,R86 | R_0603_1608Metric | C25804
43K 1% | R76 | R_0603_1608Metric | C23172
100K | R82,R83 | R_0603_1608Metric | C25803
Boot_Mode | SW1 | MST22D18G2 125 | C2906280
LOGO | SYM02 | diybms_logo_24x10mm
10K NTC | TH6 | R_0805_2012Metric | C51597
AP2204K-5.0TRG1 | U11 | SOT-23-5 | C112031
EL3H7(B)(TA)-G | U13 | SOP-4_4.4x2.6mm_P1.27mm | C32565
MAX14921ECS+T | U1 | TQFP-80_12x12mm_P0.5mm | C2932577
MCP1502T-45E/CHY | U6 | SOT-23-6 | C5236158
MCP33151-05-E/MS | U3 | MSOP-10_3x3mm_P0.5mm | C635984
RELAY1 | U4 | SO-4_4.4x4.3mm_P2.54mm | C2691601
STM32F030K6Tx | U5 | LQFP-32_7x7mm_P0.8mm | C46830
XC6206-1.8NR | U12 | SOT-23-3 | C2984870
XC6206-3.3V | U9 | SOT-23-3 | C2891841
XL7005A | U10 | SOIC-8-1EP_3.9x4.9mm_P1.27mm_EP2.29x3mm | C50848
8MHZ | Y1 | Crystal_SMD_3225-4Pin_3.2x2.5mm | C400090

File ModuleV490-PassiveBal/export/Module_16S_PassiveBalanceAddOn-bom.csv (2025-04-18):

Row | Description | Part | References | Value | Footprint | Quantity Per PCB | Status | Datasheet | Sim.Enable | PartNumber | LCSCStockCode
1 | Light emitting diode, small symbol | LED_Small | C0 C1 C2 C3 C4 C5 C6 C7 C8 C9 C10 C11 C12 C13 C14 C15 | Yellow | LED_0603_1608Metric | 16 |  | ~ |  | 19-213/Y2C-CQ2R2L/3T(CY) | C72038
2 | Generic connector, single row, 01x22, script generated (kicad-library-utils/schlib/autogen/connector/) | Conn_01x22 | J2 J5 | 22PIN | PinHeader_1x22_P2.54mm_Vertical | 2 |  | ~ |  | X6511WV-22H-C30D60 | C725954
3 | Generic connector, single row, 01x02, script generated (kicad-library-utils/schlib/autogen/connector/) | Conn_01x02 | J1 | FAN_12V | JST_PH_B2B-PH-SM4-TB_1x02-1MP_P2.00mm_Vertical | 1 |  | ~ |  | B2B-PH-SM4-TB(LF)(SN) | C2904974
4 | N-MOSFET transistor, gate/source/drain | Q_NMOS_GSD | Q1 Q2 Q3 Q4 Q5 Q6 Q7 Q8 Q9 Q10 Q11 Q12 Q13 Q14 Q15 Q16 | AO3400A | SOT-23 | 16 |  | https://datasheet.lcsc.com/lcsc/2204291600_UMW-Youtai-Semiconductor-Co---Ltd--AO3400A_C347475.pdf |  | AO3400A | C347475
5 | Industrial Inductive Load Driver | SZNUD3160 | Q17 | SZNUD3160 | SOT-23 | 1 |  | https://www.onsemi.com/pdf/datasheet/nud3160-d.pdf |  | SZNUD3160LT1G | C894717
6 | Resistor | R | R26 R27 R28 R29 R30 R31 R38 R39 R40 R41 R42 R43 R48 R49 R50 R51 | 18R 2W | R_2512_6332Metric | 16 |  | ~ |  | CRH2512J18R0E04Z | C175426
7 | Resistor | R | R20 R21 R22 R23 R24 R25 R32 R33 R34 R35 R36 R37 R44 R45 R46 R47 | 100R | R_0603_1608Metric | 16 |  | ~ |  | 0603WAF1000T5E | C22775
8 | Resistor, small symbol | R_Small | R53 R54 R55 R56 R57 R58 R59 R60 R61 R62 R63 R64 R65 R66 R67 R68 | 330R | R_0603_1608Metric | 16 |  | ~ |  | 0603WAF3300T5E | C23138
9 | Temperature dependent resistor, negative temperature coefficient | Thermistor_NTC | TH1 TH2 | 10K NTC | R_0805_2012Metric | 2 |  | https://datasheet.lcsc.com/szlcsc/Guangdong-Fenghua-Advanced-Tech-CMFB103F3950FANT_C51597.pdf |  | CMFB103F3950FANT | C51597

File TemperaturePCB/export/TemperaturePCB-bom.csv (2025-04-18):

Row | Description | Part | References | Value | Footprint | Quantity Per PCB | Status | Datasheet | LCSCStockCode | PartNumber
1 | Generic connector, single row, 01x02, script generated | Conn_01x02_Socket | J1 | S2B-PH-SM4-TB(LF)(SN) | JST_PH_S2B-PH-SM4-TB_1x02-1MP_P2.00mm_Horizontal | 1 |  | ~ | C295747
2 | Temperature dependent resistor, negative temperature coefficient | Thermistor_NTC | TH1 | 10K NTC | R_0805_2012Metric | 1 |  | https://datasheet.lcsc.com/szlcsc/Guangdong-Fenghua-Advanced-Tech-CMFB103F3950FANT_C51597.pdf | C51597 | CMFB103F3950FANT

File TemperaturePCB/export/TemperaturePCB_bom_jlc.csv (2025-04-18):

Comment | Designator | Footprint | LCSC Part #
S2B-PH-SM4-TB(LF)(SN) | J1 | JST_PH_S2B-PH-SM4-TB_1x02-1MP_P2.00mm_Horizontal | C295747
10K NTC | TH1 | R_0805_2012Metric | C51597

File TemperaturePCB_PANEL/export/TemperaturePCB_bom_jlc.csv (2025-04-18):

Comment | Designator | Footprint | LCSC Part #
S2B-PH-K(LF)(SN) | J1,J2,J3,J4,J5,J6,J7,J8,J9,J10,J11,J12 | JST_PH_S2B-PH-K_1x02_P2.00mm_Horizontal | C265016
10K NTC | TH1,TH2,TH3,TH4,TH5,TH6,TH7,TH8,TH9,TH10,TH11,TH12 | R_0805_2012Metric | C51597

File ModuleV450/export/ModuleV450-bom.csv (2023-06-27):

Row | Description | Part | References | Value | Footprint | Quantity Per PCB | Status | Datasheet | LCSCStockCode | PartNumber | JLCPCBRotation
1 | Unpolarized capacitor | C | C1 | 100nF | C_0805_2012Metric | 1 |  |  | C49678 | CC0805KRX7R9BB104
2 | Unpolarized capacitor | C | C2 | 10uF | C_0805_2012Metric | 1 |  |  | C15850 | CL21A106KAYNNNE
3 | Adjustable Micropower Voltage Reference Diodes, TO-92 | LM385Z-ADJ | D1 | AZ432ANTR-E1 | SOT-23 | 1 |  | https://datasheet.lcsc.com/szlcsc/Diodes-Incorporated-AZ432ANTR-E1_C84139.pdf | C84139 | AZ432ANTR-E1
4 | Light emitting diode | LED | D4 | Blue | LED_0603_1608Metric | 1 |  | https://datasheet.lcsc.com/lcsc/1811101510_Everlight-Elec-19-217-GHC-YR1S2-3T_C72043.pdf | C72043 | 19-217/GHC-YR1S2/3T
5 | Light emitting diode | LED | D3 | Red | LED_0805_2012Metric | 1 |  |  | C84256 | NCD0805R1
6 | 600W unidirectional Transil Transient Voltage Suppressor, 6.8Vrwm, DO-214AA | SM6T6V8A | D2 | SMBJ5.0A | D_SMB | 1 |  | https://datasheet.lcsc.com/szlcsc/1912111437_AnBon-SMBJ5-0A_C440263.pdf | C440263
7 | Generic connector, single row, 01x02, script generated (kicad-library-utils/schlib/autogen/connector/) | Conn_01x02_Male | EXTTEMP1 POWER1 RX1 TX1 | Ext Temp Sensor | JST_PH_S2B-PH-K_1x02_P2.00mm_Horizontal | 4 |  | https://datasheet.lcsc.com/szlcsc/JST-Sales-America-S2B-PH-K-S-LF-SN_C173752.pdf | C265016 | S2B-PH-K(LF)(SN)
8 | Resettable fuse, polymeric positive temperature coefficient, small symbol | Polyfuse_Small | F1 | mSMD150 | Fuse_1812_4532Metric | 1 |  | https://datasheet.lcsc.com/szlcsc/TECHFUSE-mSMD150_C70121.pdf | C70121 | mSMD150
9 | Generic connector, single row, 01x04, script generated (kicad-library-utils/schlib/autogen/connector/) | Conn_01x04_Male | J2 | Comms | PhoenixContact_MC_1,5_4-G-3.81_1x04_P3.81mm_Horizontal | 1
10 | Generic connector, single row, 01x02, script generated (kicad-library-utils/schlib/autogen/connector/) | Conn_01x02_Male | J1 | J | PinSocket_1x02_P2.54mm_Vertical | 1
11 | Generic connector, single row, 01x02, script generated (kicad-library-utils/schlib/autogen/connector/) | Conn_01x02_Male | POWER2 | Battery | PhoenixContact_MC_1,5_2-G-3.81_1x02_P3.81mm_Horizontal | 1 |  |  | C265016 | S2B-PH-K(LF)(SN)
12 | N-MOSFET transistor, gate/source/drain | Q_NMOS_GSD | Q1 | AO3400A | SOT-23 | 1 |  | https://datasheet.lcsc.com/szlcsc/Alpha-Omega-Semicon-AOS-AO3400A_C20917.pdf | C347475 | AO3400A
13 | Resistor | R | R6 R8 R10 R22 R24 R25 R26 R27 R28 | 3R | R_2010_5025Metric | 9 |  |  | C474300 | 201007J030JT4E
14 | Resistor | R | R5 | 180R | R_0805_2012Metric | 1 |  |  | C25270 | 0805W8F1800T5E
15 | Resistor | R | R14 | 510OHMS | R_0805_2012Metric | 1 |  |  | C17734 | 0805W8F5100T5E
16 | Resistor | R | R2 | 1KOHMS | R_0805_2012Metric | 1 |  |  | C17513 | 0805W8F1001T5E
17 | Resistor | R | R16 R17 R18 | 2K2 | R_0805_2012Metric | 3 |  |  | C17520 | 0805W8F2201T5E
18 | Resistor | R | R15 R20 R21 | 10KOHMS | R_0805_2012Metric | 3 |  |  | C17414 | 0805W8F1002T5E
19 | Resistor | R | R1 | 100K | R_0805_2012Metric | 1 |  |  | C149504 | 0805W8F1003T5E
20 | Temperature dependent resistor | Thermistor | R19 R23 | CMFB103F3950FANT | R_0805_2012Metric | 2 |  | https://datasheet.lcsc.com/szlcsc/Guangdong-Fenghua-Advanced-Tech-CMFB103F3950FANT_C51597.pdf | C51597 | CMFB103F3950FANT
21 | 20MHz, 16kB Flash, 2kB SRAM, 256B EEPROM, SOIC-14 | ATtiny1614-SS | U2 | ATTINY1624-SSU-ND | SOIC-14_3.9x8.7mm_P1.27mm | 1 |  |  | C5160891 | ATTINY1624-SSU-ND
22 | DC Optocoupler, Vce 35V, CTR 50-300%, DIP-4 | PC817 | U1 | EL3H7(B)(TA)-G | SOP-4_4.4x2.6mm_P1.27mm | 1 |  | https://datasheet.lcsc.com/szlcsc/Everlight-Elec-EL3H7-B-TA-G_C32565.pdf | C32565 | EL3H7(B)(TA)-G | 90
23 | Generic connector, single row, 01x03, script generated (kicad-library-utils/schlib/autogen/connector/) | Conn_01x03_Female | UPDI1 | UPDI | PinSocket_1x03_P2.54mm_Vertical | 1 |  | ~

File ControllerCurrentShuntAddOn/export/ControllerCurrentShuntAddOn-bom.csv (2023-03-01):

Row | Description | Part | References | Value | Footprint | Quantity Per PCB | Status | Datasheet | LCSCStockCode | PartNumber
1 | Unpolarized capacitor | C | C1 C3 | 100nF 100V | C_0805_2012Metric | 2 |  | https://datasheet.lcsc.com/szlcsc/2008131833_KEMET-C0805C104K1RECAUTO_C696367.pdf | C696367 C49678 | C0805C104K1RECAUTO CC0805KRX7R9BB104
2 | Unpolarized capacitor | C | C2 | 1uF | C_0805_2012Metric | 1 |  | ~ | C28323 | CL21B105KBFNNNE
3 | Generic connector, single row, 01x07, script generated (kicad-library-utils/schlib/autogen/connector/) | Conn_01x07_Female | J1 | header | PinHeader_1x07_P2.54mm_Vertical | 1 |  | ~
4 | Generic connector, single row, 01x04, script generated (kicad-library-utils/schlib/autogen/connector/) | Conn_01x04_Female | J2 | header | PinHeader_1x04_P2.54mm_Vertical | 1 |  | ~
5 | Resistor | R | R1 R2 | 10R | R_0805_2012Metric | 2 |  | ~ | C17415 | 0805W8F100JT5E
6 | Resistor | R | R3 | 10K | R_0805_2012Metric | 1 |  | ~ | C17414 | 0805W8F1002T5E
7 | 85-V, 20-Bit, Ultra-Precise Power/Energy/Charge Monitor With | INA229-Q1 | U1 | INA229 | VSSOP-10_3x3mm_P0.5mm | 1 |  | https://www.ti.com/lit/ds/symlink/ina229-q1.pdf | C2846803 | INA229AIDGSR

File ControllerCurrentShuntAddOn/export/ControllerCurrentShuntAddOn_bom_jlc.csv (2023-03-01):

Comment | Designator | Footprint | LCSC Part #
100nF 100V | C1,C3 | C_0805_2012Metric | C696367 C49678
1uF | C2 | C_0805_2012Metric | C28323
header | J1 | PinHeader_1x07_P2.54mm_Vertical
header | J2 | PinHeader_1x04_P2.54mm_Vertical
10R | R1,R2 | R_0805_2012Metric | C17415
10K | R3 | R_0805_2012Metric | C17414
INA229 | U1 | VSSOP-10_3x3mm_P0.5mm | C2846803

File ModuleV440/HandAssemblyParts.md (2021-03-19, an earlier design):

# Hand Assembly Parts

These parts are not usually available for assembly by JLCPCB, so you need to order these from some where else and manually solder them to the modules

|Qty|Part |Footprint |LCSCStockCode|Part Number |Digikey |Mouser |
|---|---|---|---|---|---|---|
|1  |ATtiny841-SSU |Package_SO:SOIC-14_3.9x8.7mm_P1.27mm |C219103 |ATtiny841-SSU |ATTINY841-SSU-ND |556-ATTINY841-SSU |
|4  |JST socket (Ext Temp) |Connector_JST:JST_PH_S2B-PH-K_1x02_P2.00mm_Horizontal |C265016 |S2B-PH-K(LF)(SN) |455-1719-ND |PRT-09749 |
|1  |AVR-ISP-6 |Pin_Headers:Pin_Header_Straight_2x03_Pitch2.54mm |C65114 | |1849-PR20203VBDN-ND|649-1012938190601BLF|

You will also need some JST cables to connect the controller and modules together.  

These have a FEMALE JST PH 2.0 2pin connector on them and are wired "straight through", that is, pin 1 goes to pin 1, 2 to 2.

You may be able to connect two of these cables together, take a look at Amazon 

https://amzn.to/3dPgfxi
(affiliate link)

Mouser seeedstudio part number for JST connector with pigtail 713-321050009

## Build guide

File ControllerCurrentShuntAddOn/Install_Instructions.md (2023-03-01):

# Installation Instructions - DIYBMS Current Shunt Add On Board

## Steps

* Fully construct/populate/solder the add-on PCB board with the correct components.
* Determine which DIYBMS Controller PCB version you have from the images below.
* Solder the add-on board onto the *BOTTOM* of the controller PCB.
* Solder the 4 pin connector first.  If a female socket is already installed, either temporarly remove it and resolder, or attempt to heat the pins up and nudge the add-on board into the molten solder.
* Follow remaining instructions from the images below.

## Controller PCB version 4.4 and 4.5 - J14 Horizontal 7 pin
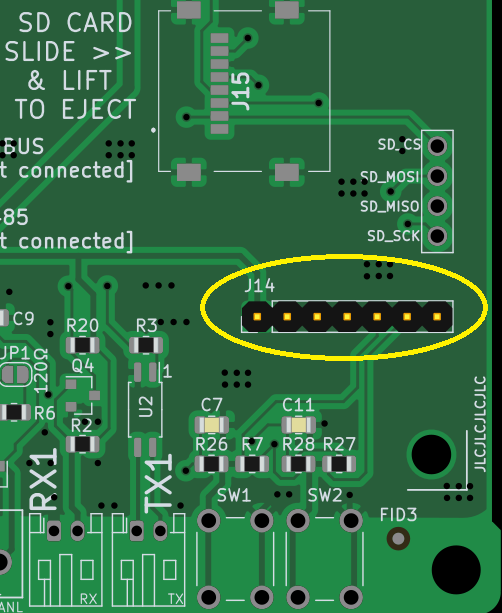
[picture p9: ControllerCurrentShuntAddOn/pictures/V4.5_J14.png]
V4.5 J14 connector


* Identify if you have this board by locating J14 which should have 7 pins and is horizontal.
* Silk screen will mention V4.4 or V4.5
* Note some V4.4 boards have a 5 pin vertical J14 connector (see below)
* Boards built after May 2022
* Add-on board will fully align to this PCB
* Solder add-on to rear of controller PCB. Attach to 4 pin header first
* Use a male 7 pin 2.54mm header to solder remaining pins to J14

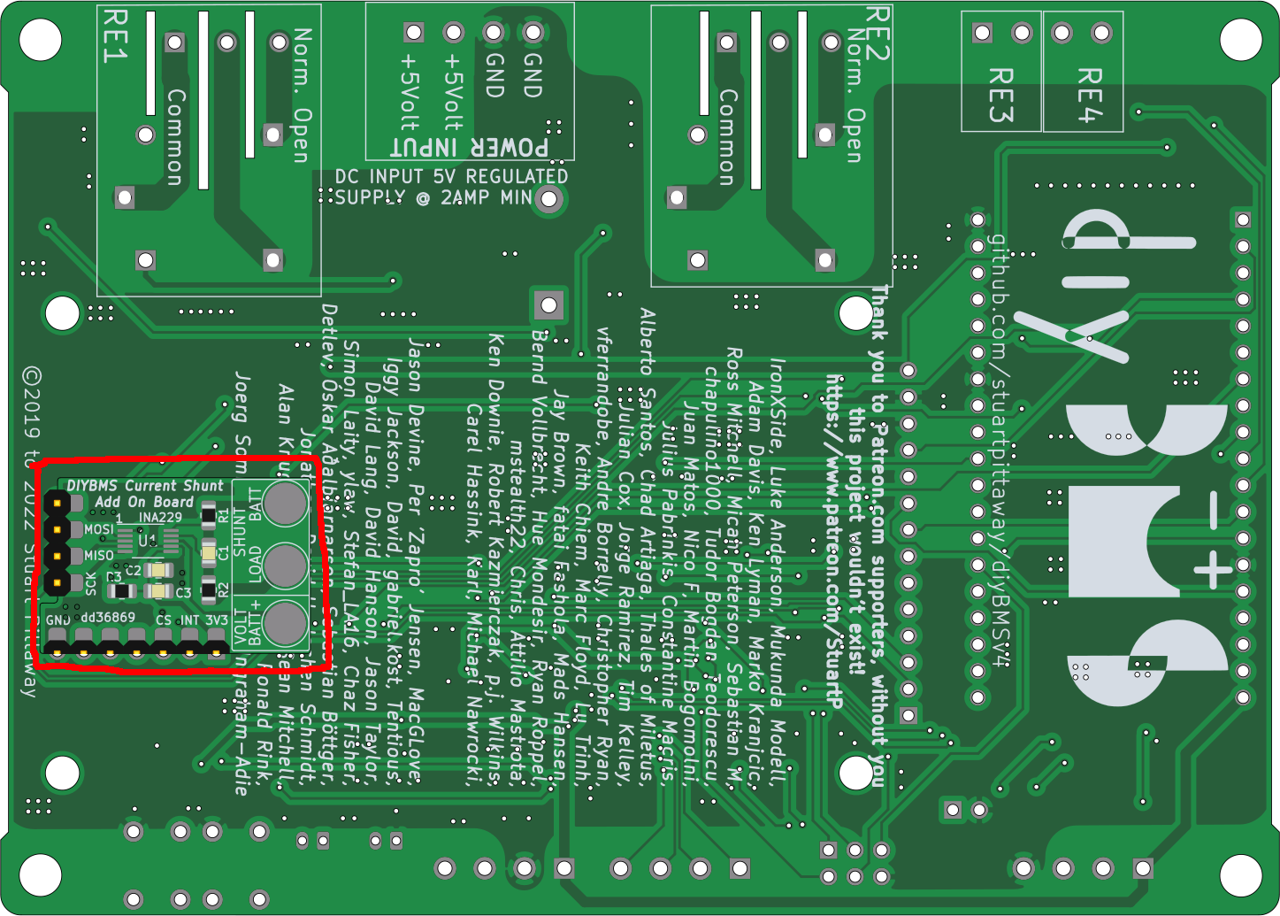
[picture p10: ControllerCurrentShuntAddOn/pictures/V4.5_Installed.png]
V4.5 Installed


## Controller PCB version 4.4 - J14 Vertical 5 pin

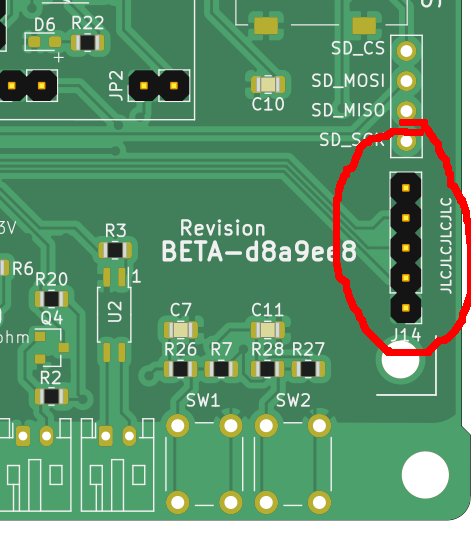
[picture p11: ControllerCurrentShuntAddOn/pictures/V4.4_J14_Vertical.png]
V4.4 J14 vertical

* Identify if you have this board by locating J14 which should have 5 pins and is vertical.
* Silk screen will mention V4.4
* Board will have SW1 and SW2 on silkscreen for push button switches
* Add-on board will NOT fully align to this PCB - additional wiring required
* Solder add-on to rear of controller PCB. Attach to 4 pin header first
* Unfortunately add-on board overlaps some pins on J14 connector. Place some insulation tape onto the back of the controller PCB, covering the overlapped J14 holes.
* Connect wires between J14 and the add-on board as per picture
* Connect the GND wire

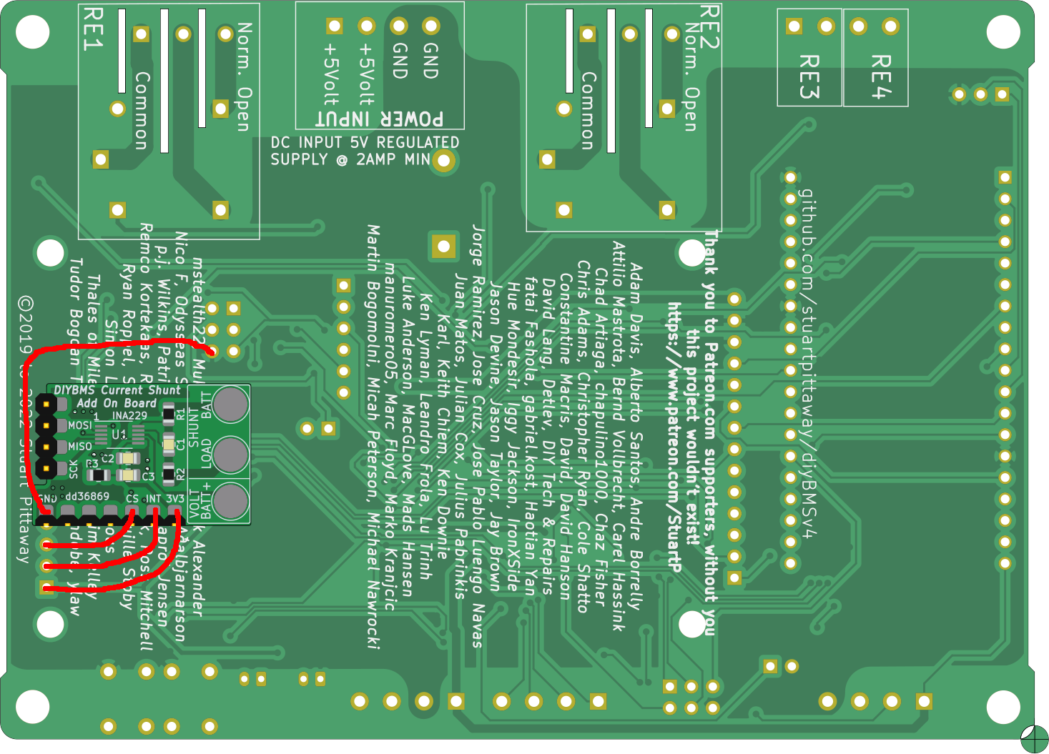
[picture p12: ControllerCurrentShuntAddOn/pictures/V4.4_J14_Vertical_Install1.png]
V4.4 J14 Vertical Installation Picture 1


## Controller PCB version 4.2 - J14 Horizontal 4 pin
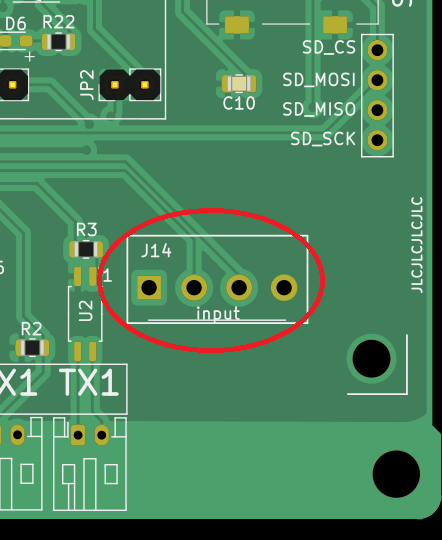
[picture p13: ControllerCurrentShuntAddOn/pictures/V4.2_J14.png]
V4.2 J14 connector


* Identify if you have this board by locating J14 which should have 4 pins and is horizontal.
* Silk screen will mention V4.2 - possibly dated "May 2021"
* TX2/RX2 are not fitted/visible
* Add-on board will NOT fully align to this PCB - additional wiring required
* Solder add-on to rear of controller PCB. Attach to 4 pin header first
* Connect wires between J14 and the add-on board as per picture

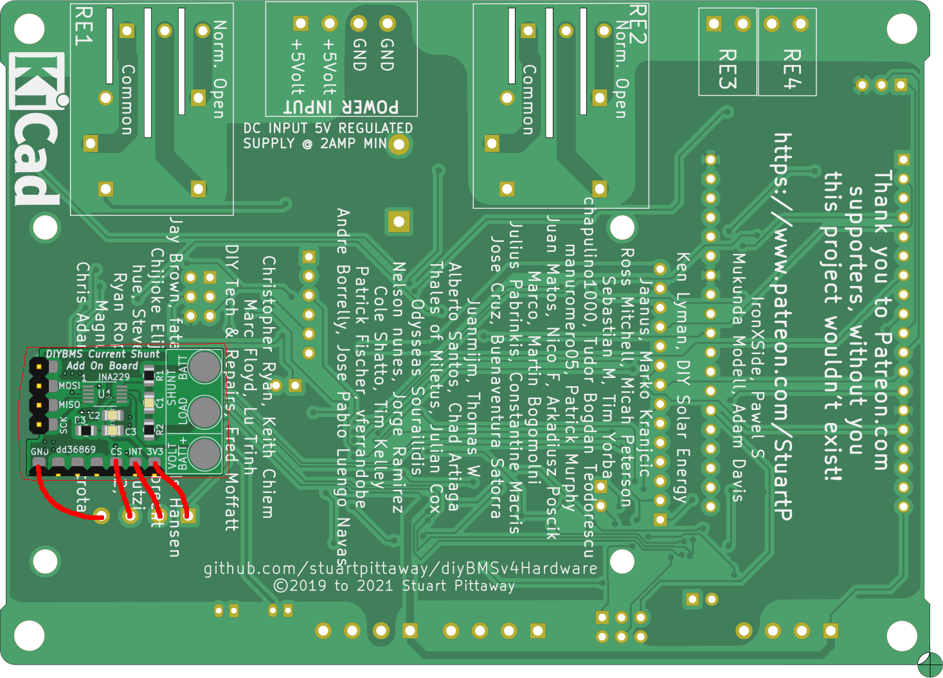
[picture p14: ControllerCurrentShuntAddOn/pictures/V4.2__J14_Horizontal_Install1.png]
V4.2 J14 Horizontal Installation Picture 1


## Controller PCB version 4.2 - J14 missing
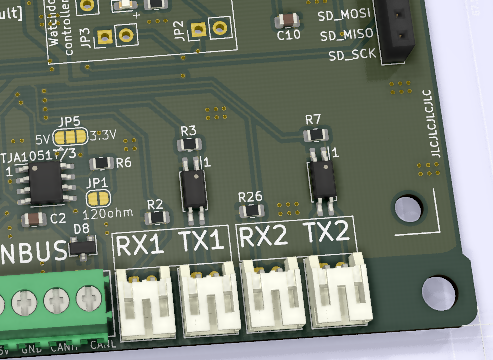
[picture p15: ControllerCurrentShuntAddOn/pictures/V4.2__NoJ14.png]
V4.2 No J14


* TX2/RX2 connectors are fitted/visible in lower right hand corner
* J14 is missing
* Silk screen will mention V4.2
* Dated before May 2021
* Add-on board will NOT fullly align to this PCB - additional wiring required
* Unsolder/remove parts marked TX2/RX2, R26, R7 and optoisolator near TX2
* Solder add-on to rear of controller PCB. Attach to 4 pin header first
* Solder +3.3V and GND wires to the rear of J6 (red and black on picture)
* Solder ESP32 pin 6, GPIO35 (purple wire on picture) to "INT"
* Solder ESP32 pin 8, GPIO33 (yellow wire on picture) to "CS"

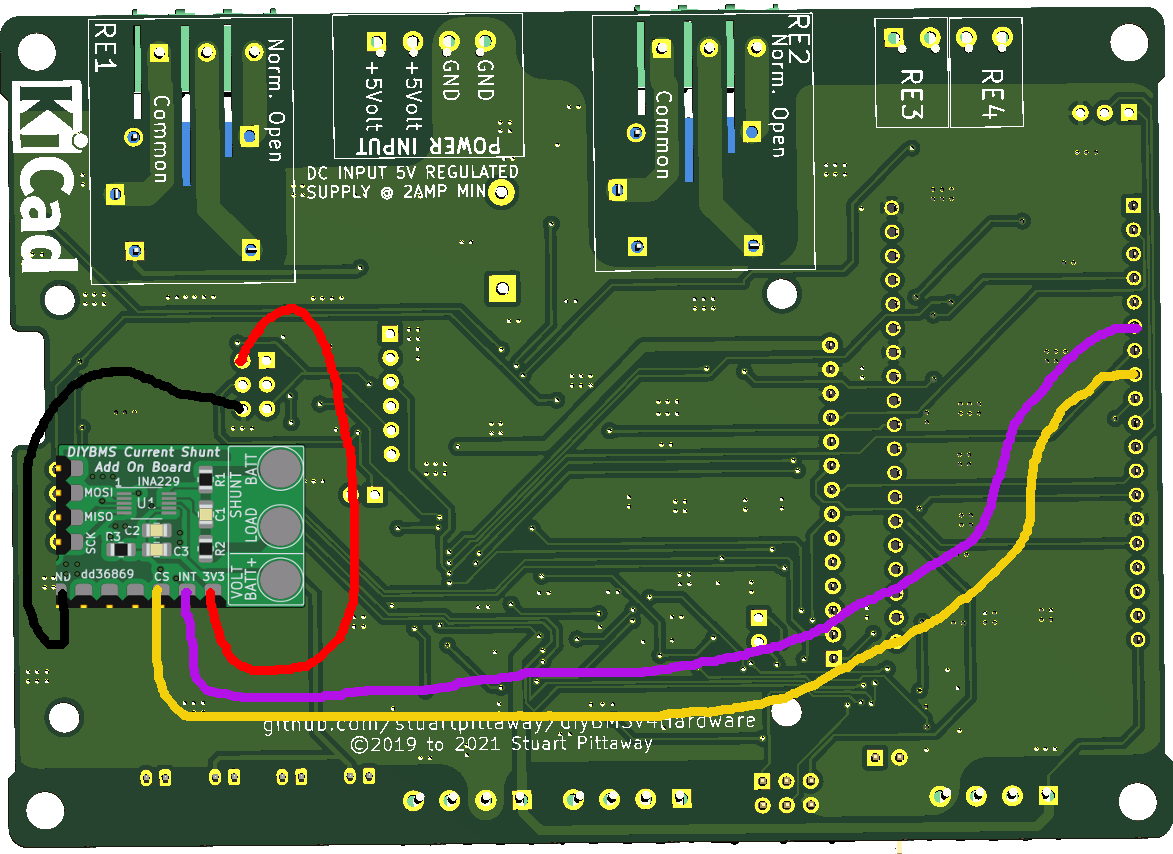
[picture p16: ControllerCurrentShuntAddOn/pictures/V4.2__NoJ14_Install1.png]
V4.2 No J14 Installation Picture 1


# Connection of Add-On board to SHUNT and BATTERY

*NOTE* Using the Add-On board means that the battery negative and the controller are electrically connected to each other via the ground/negative connections.  If you require an *ISOLATED* electrical connection, use the RS485 based external current monitor shunt board.

You will require a regulated 2amp step down transformer to drop the battery voltage to +5V, before connecting to the controller PCB.

Use of mains powered USB or 5V regulators may cause ground loop issues, and potential damage to the controller.

For more information on ground isolation, see https://en.wikipedia.org/wiki/Isolated_ground

*DO NOT CONNECT BATTERY POSITIVE + TO THE CONTROLLER +5V INPUT - YOU WILL DESTROY THE CONTROLLER PCB!*

## Connections
* Solder wire to "VOLT BATT+" terminal and connect to a FUSED battery positive
* Connect the battery negative to the controller "GND" connection
* Connect the FUSED positive positive to the SHUNT resistor, and the other terminal to the load/charger
* Connect the "SHUNT BATT" terminal to the SHUNT resistor, on battery side
* Connect the "SHUNT LOAD" to the other SHUNT resistor terminal

The shunt resistor will normally have seperate (Kelvin) terminals for the sensor wires, and nut/bolt connections for the power.

You may find it easier to route the cables to the front of the PCB through the hole under the TFT screen.  Hot glue may be useful to hold wires in place/stress relief.

Only lightweight wires are required for the connections to the add-on board, 24AWG (0.25mm) or similar should be okay.  Twist shunt sensor cables to help reduce interference.

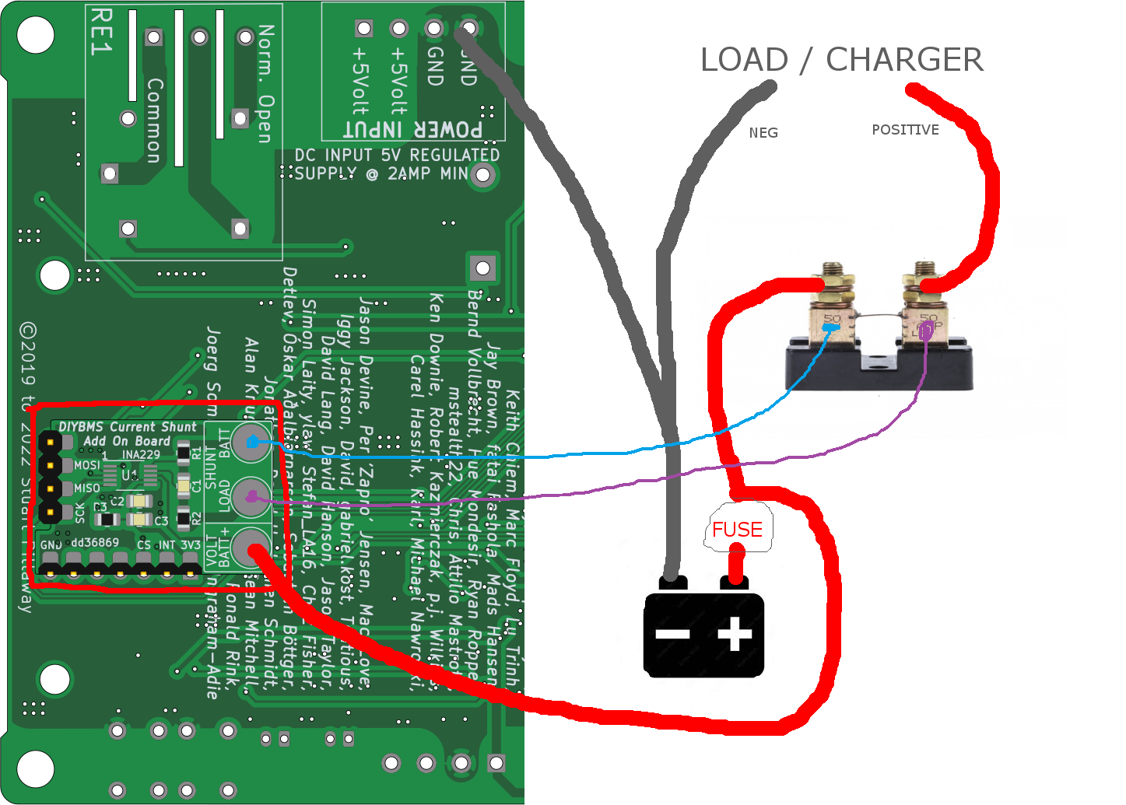
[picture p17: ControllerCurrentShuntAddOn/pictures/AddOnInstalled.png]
Final install diagram


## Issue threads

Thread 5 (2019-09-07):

LM4040BIM3-2.5/NOPB Missing in BOM

phisp, 2019-09-07:
The Part LM4040BIM3-2.5/NOPB is Missing the BOM

Also some parts are mentioned double

R1 C17414 C84376
R2 	C95781
R2	C115316

And the pin headers

The BOM and the Schematic is missing for the ESPCircuit (pdf)

Thanks for your work

phisp, 2019-11-05:
Thanks for the remove of the double entries.
The part LM4040BIM3-2.0/NOPB or similar parts is missing within the BOM.

thaxy, 2019-12-28:
I cannot find a complete list of all required parts per module.
What is the easiest way to figure out what exactly is needed?
BOM is still incomplete, right? Is only the LM4040BIM3 missing?

phisp, 2019-12-29:
I have a complete list, with approx. prices at my branch.
As far as i can see the LM4040BIM3 is the only part missing. Use the 2.048V Type. The 2.5V Type is maybe causing a few issues on my boards.
Double check the components is always a good idea.

stuartpittaway, 2019-12-29:
Take a look in the JLCPCB branch of the code, there is a fuller BOM there including some parts for substitution (note there is a newer PCB using 0603 surface mount components in that branch)

Closed 2020-01-20.

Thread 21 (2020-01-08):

Cell module brownouts

delboy711, 2020-01-08:
Two out of my twelve cell modules suffered with brownouts during bypass. Symptoms were,  communication errors, sluggish or no response to commands, and EEPROM corruption.  The corrupted EEPROM  would have a good CRC implying RAM was corrupted and then written to EEPROM. I know the CRC must be good, because on the next power up it did not load default config and all parameters were random values.
The hardware was carefully checked, and fuses and flash memory reburned, and EEPROM cleared,  with no change in behaviour. On starting a bypass it would fail again.

The brownouts were resolved by;
A/ Increasing the BOD threshold to 2.7V - This stopped the EEPROM corruption, but continual brownout resets during bypass made the module still unusable.

B/ Increasing the load resistance by inserting an additional 2R2 in each leg of the chain, making a total resistance of 5R5. This worked, but of course will reduce the effectiveness of bypass.

C/ Commoning the centre point of the 2 load resistor chains together and adding a 10uF ceramic cap from there to ground. This smooths off the rising and falling edges of the PWM, and worked effectively.

I settled on using solution 'C' as well as removing the line  'Settings::WriteConfigToEEPROM((uint8_t*)&myConfig, sizeof(myConfig),EEPROM_CONFIG_ADDRESS);' in the setup function. This statement is unnecessary since it is just writing default config, and during a brownout there is a potential this statement could be randomly executed to write bad data with a good CRC into the EEPROM which is the only way I can explain how the EEPROM got corrupted yet still had a good CRC.

delboy711, 2020-01-08:
I should add, that I am using my own layout for the cell module PCBs. The circuit is identical to Stuart's apart from the addition of a 3A fuse at the power input, and a 100nF bypass capacitor between the MCU power pins.

stuartpittaway, 2020-01-09:
Hi Delboy711, thanks for the information.

What cells are you using and voltage range that you are dragging the cells below 2.7V ?

My existing circuit already has a 100nF bypass cap over the MCU - thats component C1

delboy711, 2020-01-09:
@stuartpittaway  My cell packs are a mixture of reclaimed 18650s. I noticed the problem when connecting a cell module to a pack at 4150mV with bypass threshold set to 4100mV. I also see the same effect when attached to my bench power supply.
During bypass the cell voltage does not drop more than around 50mV, and looking on my scope I have not been able to capture any spikes below the BOD threshold. Yet the MCU does go into lah-lah land as soon as bypass commences.

stuartpittaway, 2020-01-10:
This only happens on 2 of the modules or all of them?  I also use a bench power supply for testing and haven't got it to brownout or crash like this

delboy711, 2020-01-10:
Just the two.  Some parts may be more sensitive to transients on the power rail than others.
In terms of what action you might consider I suggest removing the WriteConfigToEEPROM() statement in setup since it does not do anything useful and would save a few bytes.

I did wonder if Issue #18   might be related. Transient noise from the OP's charger could be affecting the MCUs.

stuartpittaway, 2020-01-10:
Interesting stuff. #18 may be related however that issue seems to also have larger problems like usb drop outs and mains noise on the power lines.

stuartpittaway, 2020-01-12:
Hi @delboy711 on the capacitor fix you put on the circuit, is this simply a 10uF between the positive side of the resistors and gnd ?

delboy711, 2020-01-13:
@stuartpittaway  No. I  joined the ground side of R8 and R9 together, and put 10uF between there and ground. The idea being that there would be an RC time constant between the MCU power pin and the cap on both rising and falling edges as the MOSFET switches. It may be unnecessary to do it that way, but it worked so I stopped looking further.

stuartpittaway, 2020-01-13:
I'm probably being dim here but R8 and R9 are in the middle of the resistor string (one side has R6+R8+R10+R12 the other R7+R9+R11+R13) by joining r8+r9 together you will alter the load resistance.  With the capacitor in place, wouldn't this always be charged from the VCC side of the resistors and the ground from the capacitor ?

delboy711, 2020-01-14:
@stuartpittaway  The resistance is unchanged. Since the resistors are all the same value those two points are both at the same potential, Vcc/2.
When the FET is switched off the cap will charge to Vcc, and when switched on it will discharge down to Vcc/2. Either way there is a time delay before the voltage settles which results in a slower change in voltage at the MCU power pin.
(In use, I observe that the cell voltage drops about 100mV when bypass is active.)

stuartpittaway, 2020-01-14:
Thanks for that, just for complete understanding, I've drawn a really crude picture, is this correct?  Its probably worth me copying the solution if its helped so much.

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

delboy711, 2020-01-15:
Yes. That is it.

phisp, 2020-09-14:
I have also issues with the B.O.D. set to 2.5V. The board measures a higher voltage and begins discharging until the battery block is completly drained. I will set the B.O.D. up to 3.0V and see if the issues resolve, as the balancing should stop at low voltages anyway.

The other pack has 20P3S and a voltage drop below the 2.5V is more unlikely. The 3P13S Pack has a very high likelyhood for package errors.

DanoPTT, 2020-09-27:
Measuring of higher voltage (for real low voltage) is the result of the use of improper voltage reference it this case. For such low voltage is better to use something like REF3020, which work with voltage drop just few mV (It is 3pin voltage reference, not shunt type).

stuartpittaway, 2020-09-28:
> REF3020

Hi DanoPTT, how would the change in voltage reference help in this situation?  I've not seen a problem with the reference voltage on the modules as they currently stand.

The 4.21 design also uses a lower voltage reference 1.25V - using https://datasheet.lcsc.com/szlcsc/1808081832_UTC-Unisonic-Tech-TL432G-AE3-R_C171461.pdf

phisp, 2021-10-16:
Thanks.
I used the higher voltage reference LM4040BIM3-2.5/NOPB 2.5V, due to ordering error and used 2x 13 modules each in parallel on a power supply with a battery to smooth the voltage. The difference occours at voltages below 3200mV on the measurements. I will try a 1.25V reference next.

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

Closed 2022-04-14.

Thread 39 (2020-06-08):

voltage referance

jency001, 2020-06-08:
hello,

Its not realy a problem more a suggestion.
the voltage divider u use to measure the voltage of the cell can this be changed by (example REF5040AIDR )? the 2 resistor you use to measure the voltage will change when the temperature changes. and this will be the case when you put the pcb on the battery. this chip would be a much more stable reference ( REF5040AIDR ) and will not change when the temperature changes.

pleas tell me what you think of this.

Kind regard

stuartpittaway, 2020-06-08:
Hello, I don't use this part at all in the 4.21 design - look at the JLCPCB branch for the BOM and circuit.

jency001, 2020-06-08:
hey stuart,

I know you dont use this part.
i ment this would be an improvement on your design.
if you replace the voltage diveder(see picture) with this chip(REF5040AIDR) that would be an improvment.
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

a voltage divider with resistors wil change when the temperature changes.
this chip will not.

sorry i didn't explain it wright the first time.

Kind regards

stuartpittaway, 2020-06-08:
How would the REF5040 provide the voltage of the cells I'm trying to measure the voltage of?

The resistor divider measures the voltage of the cell its connected to.

jency001, 2020-06-08:
this chip is the same as your voltage divider but much more stable. and its not affected by temperature. And to answer your question Yes this would provide the cell voltage.

jency001, 2020-06-08:
this chip i told you is only one example i looked up there are other many better choices. i just wanted to inform you. i am thinking to change this building on your design

stuartpittaway, 2020-06-08:
How would it provide the cell voltage?

jency001, 2020-06-08:
sorry my bad.
i thought u used this divider to measure the cell voltage and then put this value in the micro controller to decide if its charged or not. is there a way i can talk to you ?

Kind Regard

stuartpittaway, 2020-06-08:
Correct, that is what the divider does, it is supplied (ENABLE line) with the cell voltage and divides it down to the ADC input on the ATTINY.

The 2.048V reference is seperately fed into the ADC reference pin

Closed 2020-06-11.

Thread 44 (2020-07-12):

jlcpcb DFM Check found error on Controller PCB

SvenSFS, 2020-07-12:
Hi
i have order the Controller and the BMS V4.21 on JLCPCB.

In production Process fount the DMF an Error on U3 -> Soldering area is too small
Thanks for the great project.

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

stuartpittaway, 2020-07-13:
Hello, thanks for raising this issue.  We've had several hundred boards produced using the same GERBER files at JLCPCB !

The footprint looks fine to my eyes.  Perhaps delete your order and try again!

SvenSFS, 2020-07-13:
The job can be cancelled. it is in producion.
i will test that.

I don't see any difference in the picture. but jlcpcb corrected that.

did someone else report this error?

atanisoft, 2020-07-13:
the footprint is set to SO-16-W and should be SOIC-16W, they are very similar but slight differences in the footprint (7.0mm vs 7.5mm on length)

stuartpittaway, 2020-07-13:
Nobody else has had the same problems!

Good spot on the solder pad sizes, I'll leave this issue open. As a reminder

stuartpittaway, 2020-07-24:
This is now fixed in the JLCPCBASSEMBLY branch.  Thanks for reporting.

Closed 2020-07-24.

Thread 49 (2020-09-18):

How much charging current can the BMS handle?

tusch001, 2020-09-18:
Hi Stuart,

thanks for all the work.

I know this project started with 18650 cells but Adam Welsh posted some weeks ago a video where he uses Calb battery cells. I was looking to build a bigger system and there are cells sold that can handle (up to and above) 176 A charging current.

I'm wondering how much current those resistors on the board can handle reliably over a long period of time in your experience. I think it doesn't make sense to buy big cells and then be limited by the bms. I couldn' find any info.

And if you don't mind me asking:
Is there a low temperature charging cut off in the sofware?

Thanks

stuartpittaway, 2020-09-18:
Hello,

First the easy question - yes low temperature cut off rule is available, you can use that to drive a relay to "do something".

The BMS doesn't directly control the charging or loan current into or out of the cells.  Instead it can drive a contactor or large relay to power connected devices on and off.

Each module connected to the cells can dissipate upto 0.85A, this is largely limited by heat and the surrounding temperature.

This may not be enough if you are looking at over 176A of charging current.  What are you using to power such a high charge current?

tusch001, 2020-09-18:
Hi Stuart,

thanks for the fast reply.

My project is in the planning phase.

I am working out of a car and have variable energy needs (e.g. in winter I would like to heat a cupboard 24 h to keep temps above freezing point). I also have limited charging time and limited access to an AC plug. I thought about a second alternator (if at all possible) or a dc to dc charger from the car (sorry - I don't know the English word) plus an AC battery charger. Not yet sure how much I can charge the batteries while driving. That's why I was looking at batteries that can be charged fast.

I've seen (12 V) battery chargers that deliver 30 - 80 A, the 176 A are the maximum specs of the above mentioned calb battery cells. Although I'm planning on 1p8s or 2p8s depending on the cell size.

I thought to choose the charger and battery cell size according to how much the bms can handle and calculate roughly if I can get anywhere near my energy requirements over 24 h without putting too much weight (and money) in the car.

I hope my answer makes sense.

Thanks for your help.

tusch001, 2020-09-18:
Hi Stuart,

thanks for the fast reply.

My project is in the planning phase.

I am working out of a car and have variable energy needs (e.g. in winter I would like to heat a cupboard 24 h to keep temps above freezing point). I also have limited charging time and limited access to an AC plug. I thought about a second alternator (if at all possible) or a dc to dc charger from the car (sorry - I don't know the English word) plus an AC battery charger. Not yet sure how much I can charge the batteries while driving. That's why I was looking at batteries that can be charged fast.

I've seen (12 V) battery chargers that deliver 30 - 80 A, the 176 A are the maximum specs of the above mentioned calb battery cells. Although I'm planning on 1p8s or 2p8s depending on the cell size.

I thought to choose the charger and battery cell size according to how much the bms can handle and calculate roughly if I can get anywhere near my energy requirements over 24 h without putting too much weight (and money) in the car.

I hope my answer makes sense.

Thanks for your help.

Closed 2020-11-12.

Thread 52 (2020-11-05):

How to recover CellModules?

JoeMudr, 2020-11-05:
Hi,
i might have flashed the wrong version on my cell modules (v430 instead of v421). When I try to reflash, the green LED on the module flashes once and i get the error:

avrdude: try to set SCK period to 1.6e-05 s (= 62500 Hz)
avrdude: set SCK frequency to 32000 Hz
avrdude: warning: cannot set sck period. please check for usbasp firmware update.
avrdude: error: program enable: target doesn't answer. 1
avrdude: initialization failed, rc=-1
         Double check connections and try again, or use -F to override
         this check.

How can i revive these modules?

stuartpittaway, 2020-11-05:
Oh dear, this isn't going to be easy. The prototype v 4.3 board uses an external crystal rather than the internal oscillator. Therefore the fuses on the attiny chip are set to use an external clock.

You can recover it by connecting some wires temporary to the xtal pins on the attiny and connecting them to an 8mhz crystal.

Google how to recover Arduino after wrong fuse settings, it's a similar procedure

JoeMudr, 2020-11-10:
Hi Stuart,
I hooked up an 8Mhz Crystal to pins 2 & 3. But still the same error. Is there anything else I could try?

stuartpittaway, 2020-11-12:
The XTAL pins (2 and 3) are connected to the SENSOR1 connector - so its likely easier to connect the crystal to this point (pins 1 and 3)

You may need to include the 22pF capacitors as well - you need to create a circuit that looks like this.

The ground is on pin 5 of the sensor connector.

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

JoeMudr, 2020-11-12:
Hi Stuart,
that's basically what i did. I also connected the two capacitors to Sensor Pin5 as Ground.
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

stuartpittaway, 2020-11-12:
Silly question, but you did provide power to the board via the ISP programmer?

Did the GREEN led light up when attempting to program to board?

JoeMudr, 2020-11-12:
Yes I did. The D4 LED flashes once when I try to program the module. It also turns on once in a while when i keep the board powered long enough.

stuartpittaway, 2020-11-12:
I'm struggling for any other solutions for you I'm afraid.

JoeMudr, 2020-11-12:
No worries. I ordered a new batch of attinys.

stienman, 2021-01-18:
I programmed my fuses incorrectly at first as well, and found I could recover by doing the following:

Input a 20kHz square wave into pin 1 of SENSOR1 connector (GND to pin 5 of the same connector). It doesn't have to be perfect - connect an external arduino that's just flipping an output at either 5v or 3.3v.

Use the following command line:
avrdude -cusbasp -pattiny841 -B2000 -u -U hfuse:w:0xD6:m -U lfuse:w:0xE2:m -U efuse:w:0xF4:m

This gives a 20kHz clock to the ATTINY841, and programs it at 500Hz.  As long as SPI is still enabled this should work. You don't want to flash it this way - a 500Hz clock takes over 5 minutes to program the ATTINY841 - but the fuses are quick even at slow speeds, and faster programming should be available once the fuses are reset. If you can provide a 1, 4, or 8 MHz clock signal, you can go faster, but 20kHz is a nice minimum that most can achieve with parts they have on hand.

But since this is really a user error (choosing the wrong firmware) I think it can be closed as such, with these notes suggesting how to resolve it.

That said, "in universe" fixes could include:

Leaving the fuses for 4.3 set to internal clock, and then selecting the external clock on startup if it's present (start it, determine if it's running or not, then switch to it. Continue with internal if it's not running correctly and send an error code to the controller).

There are lots of unused I/O on the controller board, so  a fix that would use JRELAY1, or J1-J4 on the controller board to either supply the clock, or even an entire ISP programmer could be made. This would be easier on the ESP32. Of course, eventually it would be nice if the controller could update the sensor firmware over the communications bus.

stuartpittaway, 2021-01-18:
Thanks for the useful recovery guide.  The new ESP32 controller board does indeed have a built in ISP programmer to help avoid these problems.

Closed 2023-01-25.

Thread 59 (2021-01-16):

Comms Errors on ESP8266 controller - fixed with 1n4007

jdevine82, 2021-01-16:
Hi all
Just wanted to post my problem and solution for others in case they run into it. I had been experiencing comms errors between the controller circuit and the cell modules on and off for some time. I am using around 2m of cat5 running the tx and rx on the blue and green pairs. I tried adding better grounding, more filter capacitance and other things. However I found adding a diode on the rx pin of the pro mini (d7) to the 3.3v line to clamp the serial data voltage coming back to fix the problem. I just used a 1n4007.

Maybe on a future version of this circuit this might be a addition to the hardware.
Hope this may help someone.
Thanks very much to Stuart for his design. I appreciate it.
Jason

stuartpittaway, 2021-01-16:
Thanks for the fix Jason, D7 is currently pulled low by R2, what issues were you seeing with the data?  Did the module comms work fine, but the controller didn't receive the data?

I've recently had a conversation about this problem on the forum, in the end dropping R2 from 4k7 to 2k2 solved the problem.  If you get chance, perhaps try that instead of the diode/as well as.

It looks like the ESP is more sensitive to serial voltages than the ATTINY is.

jdevine82, 2021-01-16:
I had a look on the oscilloscope and it looked like the voltage at times seemed to be peaking higher than 3.3v. After it did this the esp seemed to lockout the pin for a time, before the waveform would go back to normal. I don't know what sort of internal protections the esp has. That is what gave me the the hint to try the diode clamping. I suspect it may be inductance in the cabling although pretty small current is involved in the comms, larger currents are always around from the inverter. I can see that dropping the resistor value should also fix the problem. I will try it sometime. The diode was easy as i could just jam it into the back of the pro mini header socket without taking it off the wall. The comms from the controller to the modules and between the modules has always been rock solid.

stuartpittaway, 2021-01-16:
Thanks for the detail, which way around did you put the diode ?

jdevine82, 2021-01-16:
Cathode to 3.3v.

stuartpittaway, 2021-04-12:
Further discussion on this topic is on going at the forum

https://community.openenergymonitor.org/t/workaround-for-the-communication-problems-change-resistor-in-controller/16388/70

Closed 2023-01-03.

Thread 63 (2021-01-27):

V.4.20 cell monitors showing low voltage

thucar, 2021-01-27:
I’ve had a bunch of the 4.20 boards from JLCPCB sitting around for over half a year now. Finally decided the tested cells have been sitting long enough to weed out the self dischargers.

I’ve soldered Attiny’s on 7 on them and flashed with corresponding firmware. Strangely enough 4 out of those 7 cell monitors show 1.33V when hooked to a 100P 18650 pack. I have verified that the actual voltage is 4.15V and that is also th voltage I can see on the vcc and gnd pins of the programming header.

Moving the cell monitors from pack to pack confirms that the issue is with the modules thmselves.

Will solder up and flash a new batch tomorrow. See if the results change.

Any idea what could cause such a behavior? I’m suspecting a voltage divider issue. What is the voltage range that should reach the attiny’s analog in pin doing voltage measurement?

thucar, 2021-01-28:
Bloody hell! I found the culprit.

17 out of the 30 boards I ordered, are missing the TL432CSF (D1) shunt regulator.
So mystery solved.

stuartpittaway, 2021-01-28:
That will definitely do it!!

There have been a few problems with the quality of those TL chips.

Closed 2021-01-28.

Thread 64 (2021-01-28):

Excesive imput impedance for ADC readings

wild-mustango, 2021-01-28:
Hello Stuart, I've come across your diyBMS and I want to help, not only in your HW but also in your SW design.
I am a HW and SW engineer. For now, I have started to review the circuit for the **Cell Monitoring Module Rev 4**. The file I've opened is [Schematic](https://github.com/stuartpittaway/diyBMSv4/blob/master/Circuit/circuit.pdf) I hope it is your latest revision.

Just to confirm, I also opened [source_code](https://github.com/stuartpittaway/diyBMSv4Code/blob/master/ATTINYCellModule/src/diybms_attiny841.cpp) and  checked _PB2 = ADC8 PIN 5 ARDUINO PIN 2/A8 = VOLTAGE reading_ that your are using PB2 to read voltage using a voltage divider.

For a correct reading of voltage, the impedance seen by the ADC pin, Microchip recomends a maximum if 10k output impedance (datasheet page 139). You are using R3=475k and R4=402k resistors. The impedance seen by the input pin is the parallel equivalent resistance, which is around 217k, far away from 10k. I think you (as I did in the past) used these high values to lower the current consumption, but this may be affecting the voltage reading. I'm used to PIC18 from Microchip also and had reading innaccuracies due to this problem.

Solutions:

1. Reduce R4 resistor to have a parallel equivalent resistance lower than 10k, that is, any resistor lower than 10k, e.g. 4k7. Check the accuracy of the readings regarding the 10bit resolution. Using R4=4k7 and R3=475k and 4.458V as max, will result in a max current of 9.3 uA.
2. Should you stilll get inaccuracies, you may want to use R3 and R4 lower resistance values, to increase a bit the current throught the resistors. Since you are using an enable pin to source the voltage divider whenever you want, you control the amount of current by controlling how many times and how long you enable this pin.

I hope this helps.

I am willing to collaborate in this project. Should you have any Discord channel or any other active group to talk, please let me know.

Kind regards

stuartpittaway, 2021-01-28:
Thank you for the feedback, there is an active group on the openenergymonitor forum.

The latest design is 4.21, this is on the jlcpcbassembly branch on GitHub.

From memory I think I reduced those resistor values, but will check. I had also read about the input impedance of 10K, however so far, I've had rock solid readings in the 2 years I've been using that design. I think as I'm also running the attiny at a slow clock rate and also sampling the ADC at a slow rate, plus using the low noise software settings, it's worked out ok.

stuartpittaway, 2021-01-28:
Just to add, we've recently seen trouble with the TL432 chip used in the newer design, looks likely down to poor quality control at manufacturer.

Perhaps you have another low cost voltage reference we can consider?

stuartpittaway, 2021-01-29:
I've looked a tthe V4.21 design (located here https://github.com/stuartpittaway/diyBMSv4/tree/jlcpcbassembly/Circuit)

This is using 68K and  27K resistors for the divider, and a reference voltage of 1.25V - using a TL432 current shunt.

wild-mustango, 2021-01-29:
Thanks for the quick response!!  With those res values, Rparallel is around 20k, a bit higher than recommended, but since you haven't had any problems, that's perfect (:

Regarding to the Voltage Reference, I have no experience with these devices but I talked to a friend of mine used to work with them. He told me about TL432 and a better choice: LM4040. He told me that TL432 should be used together with a 10 or 100 nF (better) decoupling cap in parallel [Parallel Capacitor](https://www.ti.com/lit/wp/slpy003a/slpy003a.pdf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) page 3. As he mentioned, TL432 has been always a good solution cheaper thant the **LM4040**, but both perform well, in his words.

I have done a quick Mouser search and barely seen a significant difference in prices, at first glance, around 0.55€. What's your price range for "low cost" you mentioned? Choosing chepaest asian brands (0.1€) may result in tolerances in manfucturing of parts. It is always a better idea to spend a little more on brands like TI for the same part number. I know for a DIY to adjust BOM cost at maximum is a goal, but maybe this component may no be the case.

Since I'm new to this voltage references, I am now reading some papers.

I don't really know what's the main problem you are experiencing with your voltage reference, do you have these problems posted in the forum?

Have you written down your specs required for the voltage reference?:
- **VREF:** I see you chose 1.25V (why this low value?)
- **VIN range:** (voltange seen by the cathode) I think this depends on the SOC of the battery cell
- **Initial accuracy:**
- **current drive**
- **power consumption**
- **Temperature range** (Temperature coefficient)
- **Package size**

In the mean time, I'm going to have a deep read on the forum thread you gave me starting from the last post so I can join the conversation there.

Regards

stuartpittaway, 2021-01-30:
Hi, the original design used the LM4040 chips, and they worked fine, they are more expensive than the TL432 (about 10x!)

The VIN range is determined by the chemistry of the battery cells, normal lithium 18650, 0-4.2V (some are 4.35V).

However to cater for lower chemistry voltages like LTO 0-2.4V

The ATTINY works fine down to 1.8V, and is run directly from the cell its connected to.  The voltage reference of 1.25V was picked as a lot of voltage references stop working when the input voltage drops below reference + 0.5V (approx).  We saw this on the LM4040, I was using a 2.048V reference, and this fails at about 2.4V input - which isn't good for LTO cell monitoring.

Ideally, I've been trying to use 1% components for accuracy, although ultimately we are stuck with a 10bit ADC on the ATTINY.

stuartpittaway, 2021-02-28:
A quick update, the newer V4.40 boards use 6.8k and 2.7k resistors to provide a lower impedance for the ADC.

Closed 2021-03-19.

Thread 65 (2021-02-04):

Pulse relay output not reliable

stuartpittaway, 2021-02-04:
Pulse relay appears to hang or not reset correctly when changing the rules

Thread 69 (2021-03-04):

module v440 pcb issues

LADesign-Github, 2021-03-04:
hello, i notice that the module v4.40 has some wrong cutout board issue in the design (see attached), also in the gerber files show the same problem, that cause the complete unconnection of the connector lanes to the board, i fix it and ive added an more professional design including all the component label into the copper layer, making it visible only looking the board from side, for a cleaner look (your boards are becaming a professional product so i think it wuold be nice to make it look professional as well) . i have new gerber files verified and obviously i'm glad to be contacted from you if i can help you in any way

issue finded: clearance, cutout, labels overwrite:

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

my idea of an possible solution:
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

stuartpittaway, 2021-03-04:
Thank you for the help and feedback.

I don't see the problems you highlighted on my designs or version of kicad, I've also used the Gerber's at jlcpcb without problems.

Are you running a new version of kicad?

LADesign-Github, 2021-03-04:
i'm using the newer one.
Also i switched to eagle and easyeda because kicad is way limited in terms of font, and personalization (my point of view obviously). anyway, both of the software find me some error (maybe caused from importing files, i don't know), so i've decided to disturb you, showing the issue i found, hoping it could be useful.

stuartpittaway, 2021-03-04:
Ok, it looks like an issue with EasyEDA and new version of KiCad, so the problem doesn't exist on the existing design using KiCad 5.1.5

I'll upgrade to KiCad 6 in the future when its officially supported/released.

If you are importing the KiCad files into other design tools (Eagle/EasyEDA) then you will find issues as neither import the files 100% correctly.

Moving the silk screen labels to the copper layers looks nice, but also reduces the size of the copper ground plane

LADesign-Github, 2021-03-04:
yes, i'm with you that probably it's an importing issue.
talking about the reducing the copper ground plane moving the labels to the copper mask: yes it's true, but considering the amount of ground plane you have is absolutely irrelevant in that kind of circuits. you have all the ground plane you need without any kind of issues. i think it could cause some problem in some kind of circuit where you are on the limit of grounding plane and with some very sensitive device onboard . definitely not here.
in my experience i've built a lot of circuit with that sistem and i never find difference in usability

stienman, 2021-03-04:
The copper ground plane isn't just for signal/noise purposes, but also
plays a role in heat dissipation.  In that case, and for this board
specifically, the rule is "The more the better!".

Personally I'm not a fan of having labels in the copper layer.  It's a
stylistic choice, sure, but as you move to more compact or complicated
designs there's simply no room.  While this may not fall into that category
I prefer to have the same style across all designs, regardless of
complexity.

-Adam

On Thu, Mar 4, 2021 at 6:06 AM LADesign-Github <notifications@github.com>
wrote:

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

stuartpittaway, 2021-03-19:
I'm closing this issue, but thank you for the heads up on newer versions of KICAD may need some modifications to the existing boards to make them render correctly.

Closed 2021-03-19.

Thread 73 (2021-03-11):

v4.4 module D2 rotate issue?

atanisoft, 2021-03-11:
Just checked the DFM output from JLCPCB for the v4.4 module PCBs and found the following differences:
Original:
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
Modified:
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

It appears that D2 is rotated 180deg.

stuartpittaway, 2021-03-11:
Hi Mike.

I think JLC have this WRONG - the "stripe" of the TVS diode needs to be facing towards the right handside of the board (towards positive).

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

stuartpittaway, 2021-03-11:
I used this reference when building the circuit for the TVS... https://www.mouser.com/pdfdocs/AND8424-D.PDF

atanisoft, 2021-03-11:
> I think JLC have this WRONG - the "stripe" of the TVS diode needs to be facing towards the right handside of the board (towards positive).

Possibly, but usually they use "-" to indicate the stripe/marking on the diodes. If I receive them reversed I'll rotate it. But wanted to log this issue just in case it is in fact incorrect on the CPL file.

stuartpittaway, 2021-03-11:
This is the reference circuit.

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

and mine (note ground is on top, so flipped image)

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

I've just stolen this from https://www.quora.com/How-do-I-identify-a-TVS-diode

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

I think JLC have this part recorded as a "standard" diode, so it looks backwards to them.

atanisoft, 2021-03-11:
Ok, as noted I'll check the boards when they arrive to confirm the orientation and adjust if required.

We may need to get a note in the CPL/BOM file for JLCPCB to ensure proper rotation.

stuartpittaway, 2021-03-11:
Looks like JLC have told another user that the part placement is wrong as well.

Why do they care!!  I can understand if the placement was wrong or the foot print wrong!

stuartpittaway, 2021-03-11:
I'm starting to doubt myself on this now, I've checked that diagram so many times

stuartpittaway, 2021-03-11:
Think I've found the issue, I'm not rotating the part in KICAD however when the CPL/BOM files are generated by a script, its adding in a 180 rotation.

atanisoft, 2021-03-11:
Great, so as long as the part is correctly placed as the band to the + side (towards edge of board) it should work?

stuartpittaway, 2021-03-11:
Yes that's right. If it's the other way, it will be a dead short!

atanisoft, 2021-03-11:
Gotcha, I'll confirm before testing/flashing/etc. Hopefully I'll have the boards in a bit over a week. I'll also use six jumper wires to test flashing from the ESP32 controller.

stuartpittaway, 2021-03-16:
Forum posts have indicated that this image/placement

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

results in a board being made like this

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

**THIS IS INCORRECT, SO ENSURE THE PREVIEW IMAGE SHOWS NEGATIVE ON THE RIGHT HAND SIDE**

Paragon35, 2021-04-04:
Hi, Stuart I got  modules from JLCPCB where D2 has a cathode stripe (-) gray stripe is on the left and an anode (+) without stripe is on the right so is it ok?

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

stuartpittaway, 2021-04-04:
No that's incorrect.  Do not power up these boards before fixing the issue.

Two options

Unsolder and remove the part

Or

Unsolder and rotate, solder back on.

The part is quite large, so not difficult to do.

Paragon35, 2021-04-04:
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

thanks so when JLCPCB wanted to turn the element unnecessarily I told them to leave them as in the original :)
I will turn around, no problem, as you write it is a big element, thanks again and best regards

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

stuartpittaway, 2021-04-04:
How long ago did you order these? I changed the silkscreen a few weeks ago to help jlc orient the part correctly

Paragon35, 2021-04-04:
>
>
> How long ago did you order these? I changed the silkscreen a few weeks ago to help jlc orient the part correctly

Stuart, order from 2021-03-10

as you can see in the picture I pasted above, JLCPCB wanted to correct the cathode (-) on the right side, it's my fault because I insisted they leave as in the original where the cathode (-) is on the left side

SP3S, 2023-04-12:
https://user-images.githubusercontent.com/62333994/231421323-ccdf93c0-a129-4373-8495-a3a33c1abfde.png

Closed 2021-05-17.

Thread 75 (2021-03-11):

Cell module option

Fred7421, 2021-03-11:
Hi Stuart,
Would it be plausible/possible for the cell module to not use any onboard cell balancing resistors/thermistor combo, but instead have the option to take that signal straight to a relay-- on a per cell basis --?
My cells are quite large and it would be much easier for balancing if I could take the 'balance signal' and use it to trigger a much larger load for balancing that cell.
Fred

stuartpittaway, 2021-03-17:
The code uses PWM so would want to switch the relays on and off very quickly.  Would you be monitoring the balance load temperature?

Fred7421, 2021-03-17:
Yes, an external load would be monitored but I would still need to monitor the temperature of the cell module itself.

stuartpittaway, 2021-03-17:
You could keep the in board MOSFET and PWM but just use another larger external MOSFET instead of a relay?

Fred7421, 2021-03-17:
I'll look into the MOSFET idea and see if I can come up with a simple circuit.
Thanks Stuart.

Fred7421, 2021-03-18:
What frequency am I looking at?

stuartpittaway, 2021-03-18:
Low, the PWM is triggered every millisecond.

Fred7421, 2021-03-18:
Ok, and the max current through the dump load is 940mA?

stuartpittaway, 2021-03-18:
About that yes. The JST connect is rated up to 2amp but I would not put that through them.

Fred7421, 2021-03-18:
I think I've got it worked out,
How do I stop the dump load signal from turning off for a blip every minute? Is that in the code, or should I replace the thermistor with say a 100Kohm resistor?

stuartpittaway, 2021-03-19:
The dump load shouldn't be triggering that frequently. It's active high, so held low by the pull down resistor.

Fred7421, 2021-03-19:
It's unconnected to any controller, just power to the module.

Fred7421, 2021-03-19:
Well I've got the module connected to the controller (working), I've got the relay connected (working) and every 13 seconds the red led indicating the dump load blinks once, it blips off then back on.
No worries though, a cap keeps the relay on during that blip.

stuartpittaway, 2021-03-19:
How strange, I'll have to dig out the scope!

Fred7421, 2021-03-19:
keep in mind that my cell module does not have the dump load resistors soldered on.

Fred7421, 2021-03-23:
Hi Stuart, What do you think about this
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
I'm planning on using a wire-out for the relay signal and pulling the power for the relay directly from each cell.

stuartpittaway, 2021-03-24:
Would it not be easier to change the code just to remove the PWM signal? You wouldn't need all those large caps.

I'm still intrigued on the need to do this at all, do your cells really need balancing that much?

How are you preventing the external load from going over temperature?

Fred7421, 2021-03-24:
My cells are i80p each and they were not constructed at the same time, meaning they are definitely different in capacity.
Some charge up faster than others so I have a need for balancing.
As far as the need to monitor the heat of the load, I'm not planning on just burning off the excess. I'm still not sure how yet, maybe lights, or using it to charge smaller cells, or a capacitor bank.
I was under the impression that the PWM signal is there for a reason, so I was bypassing it. The large capacitor ratings are for when the PWM signal jumps from ON to OFF as the cell voltage decreases.
If it's easier to just remove it from the code (without losing an important feature), I'll go with that.

stuartpittaway, 2021-03-24:
The PWM is there for a reason, it keeps the temperature of the module down to the set level.

If you don't need that, it's fairly easy to just switch it on when needed. The bypass current counting won't work in this scenario.

Fred7421, 2021-03-24:
So for my situation, I can disable both the PWM and bypass current counting features, along with nixing my capacitors.
Will this be the same for the latest v4.4 module and the new controller?

stuartpittaway, 2021-03-24:
Yes it's the same code and almost identical circuits

Fred7421, 2021-03-24:
I'm going to need help with changing the code, but not right now
Thanks Stuart!

Fred7421, 2021-06-30:
Hi Stuart, I've got my v4.4 module completed and I have successfully used the new controller to program it via the web interface. Originally I was going to use capacitors to level out that 'blip' in the discharging system, but seeing how easy it was to program the modules, I think I still might.
Here's a pic of my module and adding a cap filters out the 'blip' on my relay board just fine.
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

Closed 2023-07-05.

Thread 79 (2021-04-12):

Is ballancing done right ?

axwell, 2021-04-12:
Hello Stuart, i have a question about the balancing.
My 6s6p pack will charge within a voltage range of 10-20 mv between cells, but after the 4.1 threshold the pack is instantly debalanced some cells going sometines to 4.3

  from 4.1 volts for a short period of time and range to about 200 - 300 mv difference.

Why? is this ok ?

Also shouldn't balance start right away when charging, progressively starting to apply PWM to the cells that are "overcharged" ? This avoids high temperatures because you don't need to start with 100 % PWM or when the cell is almost charged ?

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

fhorst1, 2021-04-12:
I don't know about your type of cells.
4.3 seems high to me.
Lithium polymer has top of 4.2?
I'm more LiFePO4 guy (top 3.65)

You don't need to start at lower voltages.

If you do a battery capacity test, you will notice that the cells don't have the same voltages at similar SOC.
At 60% my testing voltages during 10A load varry between 3.1 and 3.3, where they all end at the same bottom voltage with the same capacity.

Charging will give the same issue, and you might be holding back a cell who is in reality lower on capacity, just shows little higher voltage.

I have the balance set at 3.5v, enough room to hold back, if needed.

For polymer, 4.05 is similar.
If the top is 4.2, no cell should be able to charge to 4.3!!!
Your controller board should stop the charge after one (or more) cells have reached the maximum voltage.

axwell, 2021-04-12:
batteries are panasonic ncr18650b, all new.
yes, it stops, but after the voltage spike of 4.3 for a few seconds.

stuartpittaway, 2021-04-12:
How are you charging them? Ideally the charger stops and balancing is then rarely required.

At present, it's a simple on/off top balance, it works but is a little crude.

axwell, 2021-04-13:
charger is victron mppt, set at 24.6 V.
It will not turn off, because the load will switch off also.

fhorst1, 2021-04-13:
I have a "hybrid inverter" so MPPT build in.

I can't switch off the Mppt without the inverter, but I can (and do) disconnect the solar power coming into the MPPT with a contactor.

Please don't use Solid State Relay for this, they get too hot and aren't intended for long contact periods, rather many short contacts for a long, long time

Magnetic Contactors, 20-50A should be enough, available in 5 to ?? DC volt.
That means the magnetic coil is switched with that voltage.
The contact voltage can be 800-1000v, at 20-50A.
Most people use 12v contactors.

Some say they use a lot of energy.
My cheap Chinese use 5w keeping contact.
Up to you to decide if that is a lot or not :-)

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
This is a good quality one, uses less energy (about 3w) and is +$100,-

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
This is my cheap type, price about $20,-

fhorst1, 2021-04-13:
Your controller board can have the relay board.

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

Each really can disconnect the contactor at a rule.
In this situation, when the voltage is above 4.205v (or so) disconnect.

And automatic reconnect at your settings, like 4.15v or so

stuartpittaway, 2021-04-13:
> charger is victron mppt, set at 24.6 V.

On the screenshot of diybms it shows 24.95V - how did the voltage get that high if the Victron isn't set to go that high?

axwell, 2021-04-13:
> > charger is victron mppt, set at 24.6 V.
>
> On the screenshot of diybms it shows 24.95V - how did the voltage get that high if the Victron isn't set to go that high?

Neither do i, that's why i was asking the question about the balance.
When one of the cell goes into balance, other 1-3 cells goes to 4.3 instantly and overall votage overshoots, then i have the relay board from above and the relay kicks in.

fhorst1, 2021-04-13:
At what voltage do you have your balancing set?

It seems like they are really close together, and almost reach the balance top of 4.2 at the same time.

Even if one cell does get discharged , it should not affect the other cells. (That much)

Only thing I can think of, is that the charger goes from CV, constant voltage charging stage (the least stage) back to CC, constant current.
Or atleast higher capacity.

Overall voltage does reduce, what might trigger the charger.

Usually the dumpload of the DIYBMS doesn't have that much impact, except on low capacity cells.
How many of the panasonic ncr18650b do you have in parallel??
If it's just a few Ah, that would explain a lot.
(With 560Ah, one DIYBMS cell module doesn't have much impact..
Even with 3 cell modules, it's just slowly balancing/dumping..)

If it's just one or two cells, the dumpload might be too strong for the capacity.

I suggest to play around a little with both the balance start voltage.
Perhaps let it start at 4.0v.
And slowly work your way up to the level where you feel comfortable that it doesn't swing so much.

 The charge controller settings:
It does seem to be 0.3v lower at the controller then the battery is, you could adjust the victron to 24.3v

Usually there are 2 settings, bulk and absorption phase.

I usually have my bulk phase one volt higher then the absorption.
(Absorption is also the CV phase)

I hope this helps.

axwell, 2021-04-13:
I lowered the voltage on victron.
My pack is 20Ah, maybe is too small for the balacing ?

fhorst1, 2021-04-14:
The standard 0.8A might be too much for your small pack.

It's "easy" to adjust. (@stuartpittaway , please correct me if I'm wrong about this)

While you can't really tune the capacity, it's hold back by temperature.
Currently set at 60 degrees Celsius.
With a heatsink the temperature is lower, making it possible to have higher dump load (up to 1.2A)

When you reduce the temperature to like 50C, it should dump less current.

fhorst1, 2021-04-18:
@axwell

Any update if lowering the maximal dumpload temperature helped?

axwell, 2021-04-21:
@fhorst1 kind of works, when balancing starts until it reaches the temperature the voltage overshoots, but after temperature is reached is ok.
I think a better option is to limit the current, it was nice to be a setting in the interface.

stuartpittaway, 2021-04-21:
You can't limit the current, just control the PWM frequency using the temperature.

fhorst1, 2021-04-21:
Happy that the workaround did the trick.

20Ah is for this type of BMS "really small"

In my experience battery is always too small.
For me that stopped after hitting the +1000Ah @s16 LiFePO4 (51.2v)

If you have a possibility to grow, it's working for now, and later will be better.

No possibility to grow? It's working for now ...... :-)
But DIYBMS might not be the best choice.

I do believe in obtainium, use what you have!

stuartpittaway, 2021-04-21:
You will probably struggle to find a BMS with a higher balance current, diybms and batrium seem to have the highest loads at the moment. Somewhere between 0.6A and 2A

fhorst1, 2021-04-22:
It seems like the high Balance capacity is the problem for this (small capacity) setup.

With 20Ah, this BMS might not be the best choice. It's functional now, that's most important.

And if you plan on expanding, it will be great.

I doubt there is anything else to fix this problem.

Perhaps @stuartpittaway can make in the introduction of DIYBMS a remark about adviced minimal capacity of 40Ah.
(The 40Ah is educated guessing, where 20Ah is doable with restricted temperature, double it should be OK)

axwell, 2021-06-30:
Hello again,
even with a lower temperature the issue was more or less the same, so i decided to build a bigger pack and everything was setup up the same issue appeared, so i started to wonder if the cables were ok.

I had the cable like this:
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

So i decided to make 1-1 cables and a little bit thicker and the problem went away, balancing is perfect now :)

SergioRius, 2021-08-12:
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

So interesting. I had my +200Ah bank configured at 4.05v (victron equipment) and i was having fast battery voltage raising over the charge limit when having big ac loads, like charging the car.
I've lowered the voltage limit to 3.93v/c to avoid blowing cells since.

If absorbtion is set to 55,3 and float to 55v, what do you think bypass should be set?

datenheim, 2022-08-10:
> I had the cable like this: 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
> So i decided to make 1-1 cables and a little bit thicker and the problem went away, balancing is perfect now :)

I Also started with these far too tin cables and had a lot of issues with balancing. As soon as the balancing started to kick in, the measured voltage was modified by the voltage drop of the balancing current (balancer and voltage measurement share the same thin wires).

I would suggest to either use thicker wires, or even to separate the balancers current path from the measurement by using 4 wires - 2 for balance current, and another 2 for voltage sense...

Closed 2023-07-05.

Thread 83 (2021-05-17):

TJA1057GT/3J

trebor1508, 2021-05-17:
is a shortage of this element in jlc and everywhere. can be replace by other available chip?

atanisoft, 2021-05-17:
IFX1050GVIO should be a drop in replacement, but it is also likely backordered from most suppliers.

You can also omit this chip safely if you are not planning on using the CAN bus for taking to a charge controller etc.

trebor1508, 2021-05-18:
For what purpose this communication can be used? I have a victron equipment.
Or i think i can solder manually later on when this chip will be available.

stuartpittaway, 2021-05-18:
It can be added later on without a problem - its not currently used by the software so you won't miss any functionality (at the moment).

I've spoken with JLC and they have said there should be some arriving this week - but I've been told that before.

stuartpittaway, 2021-05-18:
Parts which can be used:

IFX1050GXUMA1 = C129255
TJA1057GT/3J = C112947
TJA1051TK/3 (no longer available from JLCPCB)

On the TJA range - the import part is the "/3" - indicating its 3.3V compatible.

At the time of writing, JLC have very little stock of the above.

Looking at other sites, all are out of stock (Farnell/Mouser etc.)

trebor1508, 2021-05-18:
I have check for C112947 all available sources and nothing.

https://b2b.partcommunity.com/3d-cad-models/sw-push-6mm-h5mm-kicad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
this kind push button?

Yes I will be ordering now.  So i will try 4,3

about Farnell, part of group called CPC is located 1miles from my home location (Preston) :)

Thanks Stuart

stuartpittaway, 2021-05-18:
That button should be good. Just a word of warning, this is a new revision but nothing major has changed, but I've also not fully tested it!

trebor1508, 2021-05-18:
So it will be a test, I will order 5 fully asembled (difference in price is about 10F)

trebor1508, 2021-05-19:
Stuart. Jlc said "The orientation of the component does not match the pad" on controller board. But i do not see any changes.

fhorst1, 2021-05-20:
I'm a bit confused.
The new version controler can "talk" CANBUS? Or not yet?

For me the communication with canbus was / is the reason to switch over to the new controller version.

Due to problems with parallel, I now have my setup all series, and need 5* controller, 80x cell modules.
Not a problem, I have.

My 3 hybrid inverters have only CAN as communication protocol for the BMS.
Not sure how it can actively assist the charge controller, that is something to find out once installed :-)

Would be nice if it already can do CAN :-)

stuartpittaway, 2021-05-20:
The CAN hardware is on the controller board, but the software has not been written to talk CAN - yet.

What inverters do you have?

stuartpittaway, 2021-05-20:
> Stuart. Jlc said "The orientation of the component does not match the pad" on controller board.
> F1
> But i do not see any changes.

Thanks @trebor1508 - I changed the size of the pad for the fuse (F1) as JLC kept saying it was too large - the part cannot be oriented incorrectly as it doesn't have a polarity.

Can you upload the pictures they send you (or you can logon to the JLC account to see them)

fhorst1, 2021-05-20:
I found the communication protocol.

Can't seem to be able to attach PDF here, so I did it in OEM forum

trebor1508, 2021-05-20:
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

stuartpittaway, 2021-05-20:
> I hope this helps

It looks identical to me as well !

trebor1508, 2021-05-20:
They mention about resistor R3 but R1 and R4 looks identical.
F1 should be good as well.

stuartpittaway, 2021-05-20:
@trebor1508 think I've spotted an issue with the controller board - U9 and U12 are rotated incorrectly, this will need to be fixed after delivery/build of your order - unless you can cancel now.

trebor1508, 2021-05-20:
I can not cancel now. But it is only 4 leg chip. I think i can fix it when they arrived.

trebor1508, 2021-05-20:
Stuart

> @trebor1508 think I've spotted an issue with the controller board - U9 and U12 are rotated incorrectly, this will need to be fixed after delivery/build of your order - unless you can cancel now.

check the photo what I upload, JLC rotate U9 and U12. So I do not have to do anything.

stuartpittaway, 2021-05-20:
Great, should be good to go then.

trebor1508, 2021-05-20:
> Great, should be good to go then.

I placed my order yesterday.

trebor1508, 2021-05-21:
one more simple question: Switch SW1 and SW2 how many milimeters are between legs?

stuartpittaway, 2021-05-22:
This is the part the footprint is based on

https://www.mouser.co.uk/ProductDetail/CK/PTS645SL502LFS?qs=UxeAxwACbqm88cEAxDT3kg==

It's fairly generic foot print, think it's 6mm spacing, but check datasheet

trebor1508, 2021-05-27:
Is here someone from UK who order from JLC recently?  I have choose DHL and they sent me a message to pay £45 import tax. But on JLC was on order over £135 will be no tax.
£158 order with postage €45 tax. SWEET. Bloody BREXIT.

stuartpittaway, 2021-05-28:
When you order there is another. Option to use DHL with prepaid tax, either way you have to pay vat at 20%

The message on jlc website is incorrect

trebor1508, 2021-06-02:
I received my order from JLCPCB

I have solder the first controler and is working fine.

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
SD CARD socket is not so good.

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

trebor1508, 2021-06-02:
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
Is this fine? Or cable color is reversed?

atanisoft, 2021-06-02:
Module cables are reversed. Use a thin flat blade to pull up the securing pin and swap them.

stuartpittaway, 2021-06-03:
What is wrong with the SD card holder? Does it work okay?

trebor1508, 2021-06-03:
It is working but screen need to be removed to install sd card.

stuartpittaway, 2021-06-03:
> It is working but screen need to be removed to install sd card.

That's a relief, I've ordered 40 boards!

The new card holder is more secure, and the card won't fall out due to vibration etc.

trebor1508, 2021-06-03:
To be clear,  i am not complaining. I am sharing my thoughts and observations.

stuartpittaway, 2021-06-03:
No problem, I didn't read it as a complaint, just making sure it all works!!

trebor1508, 2021-06-03:
Good. I will do some modules and seehow it works with them.

trebor1508, 2021-06-03:
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
So this plus belong to connector? I think i bought wrong cable.

atanisoft, 2021-06-03:
> So this plus belong to connector? I think i bought wrong cable.

Yes, the red/black need to be reversed in the cable. Unfortunately almost all cables are sold in this fashion. You can use a thin blade to pull up the locking pin on the cable to remove the wires and reinsert them in the correct orientation.

trebor1508, 2021-06-03:
what mean "libusb0.dll" can not be found? I try to program module.

shampeon, 2021-06-06:
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

Would this TI chip be a good replacement for the TJA1057GT/3J? Mouser has plenty in stock.
https://www.mouser.com/ProductDetail/Texas-Instruments/TCAN4420DR?qs=W0yvOO0ixfFdDbLci2afMw%3D%3D

atanisoft, 2021-06-06:
@shampeon from a very quick review of the datasheet it looks like it might work. It does have a considerably higher cost basis though, around 3x of TJA1057GT/3J and 2x of IFX1050GXUMA1.

fhorst1, 2021-06-06:
At $2.72 total price will be 2 bucks more, per module.

For low cost, the older controller board works fine.

For more (future) advanced controller, the 2 bucks extra is probably not going to be the showstopper.

I found with my order Many parts unavailable from JLCPCB, and just ordered with what was available.
The rest via components shop like Rs-online.

stuartpittaway, 2021-06-06:
As the CAN chip is not used at the moment, I'd wait and add the correct part when available

trebor1508, 2021-06-08:
Up to what voltage cell modules can be safely connected?

phisp, 2021-06-08:
i tried 6V with the V4.00 and the leds got very bright but it worked. According to the Attiny Datasheet: 1.7-5.5v, however the Optocoupler and the Leds will fail probably first. Voltages below the referance Voltage will result in false measurements. And some boards started to balance the cells. Somehow you could program the Attiny to shutdown, if the voltage is getting to low, however i was not able to find it.

stuartpittaway, 2021-06-08:
> Up to what voltage cell modules can be safely connected?

The modules are designed for maximum of 4.35V, but most of the components work to 5V maximum

trebor1508, 2021-06-08:
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

Do you think about modules to work with leisure batteries in campers for example?

stuartpittaway, 2021-06-08:
Is there a need? Lead acid don't need balance, the new current monitor (out soon!) would measure voltage as well (up to 85v).

trebor1508, 2021-06-09:
When i can change numbers of modules settings before i connect them to controler with loop RX TX? Or modules should be connected and changing setting then? I see "failed to save settings"

stuartpittaway, 2021-06-09:
Just press F5 to refresh the webpage if you see the save error.

trebor1508, 2021-06-09:
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
Why this is happening?

stuartpittaway, 2021-06-09:
It can't talk to the attiny chip in the module, have you connected it correctly to the ISP header?

trebor1508, 2021-06-09:
Yes.

trebor1508, 2021-06-09:
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
And 1 module have incorrect voltage readings.

stuartpittaway, 2021-06-09:
Have you calibrated the modules?  Switch off balancing before calibration though

trebor1508, 2021-06-10:
> Have you calibrated the modules? Switch off balancing before calibration though

I am so sorry but i have watched all your youtube films and tried to find on forum how to do that but i have no idea.

stuartpittaway, 2021-06-10:
You need to calibrate each module against the cell using a good quality known accurate multimeter.

Measure the voltage of the cell (when idle/not balancing or charging) and enter it into the module page, configuration setting.

Until then, the cell voltages will vary.

trebor1508, 2021-06-10:
It works. Thanks.
And how to switch off balancing?

stuartpittaway, 2021-06-11:
Balancing stops when the voltage is lower than the balance voltage set in the web interface.

If the modules are going into bypass straight away, try and calibrate with a different cell at a lower voltage

SergioRius, 2021-08-12:
On to the TJA1057GT/3J topic, do something need to be done to the jumper pad near the top of the can chip, or is totally unrelated?
I have this pad without solder and I'm afraid is something necessary for the TJA1057GT/3J to work.

SergioRius, 2021-08-12:
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

Thanks, i didn't appreciate a track between 5v pads.

Closed 2022-04-14.

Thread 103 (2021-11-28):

JLCPB rearranged some parts

wegrei, 2021-11-28:
Hi Stuart,

first thanks for all the work you have done for the community. I follow your channel since a while as I am working on a solar power wall for my house. Have collected 2500 18650 cells so far. Now I am ready to build the first bank. Did modify your 4.40 module a bit as I am working with an external Pt resistor. Skipped the break away design for my module and rearanged the Power1 receptable a bit (makes it easier for my snap in mounting). Worked all fine. Did send the gerbers, BOM and CPL to China. They have reviewed the module and changed the orientation of D2 on the board (see picture attached). Is that right?
They also rearranged some parts on the controller board. In the DFM Analysis I got a warning that PAD to PAD spacing is too large. I think I can skip that warning. Then they changed orientation of D1. This is in order with the marking on the boeard. Is that correct? Furtheron they turned the SD-Card around, which I think is the bigger problem as the screen is covering the slot then. Is there a problem in the design or did they make a mistake there. Would be nice if you could help me out.
Again thanks a lot, greetings from Germany, Wern
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
er

stuartpittaway, 2021-11-28:
Normally jlc know what they are doing, so it's likely ok to go with the changes.

The problem is that they keep restocking parts and at the same time change the orientation, so I. Can't keep up with their changes.

wegrei, 2021-11-28:
Thanks Stuart,

that helps. Lets wait and see what shows up.

Have a good one, Werner

wegrei, 2021-12-12:
Hi Stuart,

just received the printed boards from china. There really seem to be a problem in the design. As it looks like the SD card has to be turned by 180°, as JLPCB did. Then you can not access the card anymore as the slot is pointing inwards. Doublechecked with the datasheet, the circuit and the printed layout. Seems that the layout has to be turned by 180°. Pls check if I am right. I might have to order a new set then.

Thanks

Werne
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
r

stuartpittaway, 2021-12-12:
Did you notice that the card slot is the same as used in some old mobile phones? You slide the metal cover up and the card does inside. It doesn't push in from the side.

The PCB was changed to use this part about a year ago, so jlc could assemble it. The notch on the PCB for the card was also removed at that time.

wegrei, 2021-12-12:
Thanks Stuart,

the holder JLPCB mount is a fixed one (slide in from the side). However try to buy one which can be slided up. It still will be hard to get access to the card as the screen is mounted above. I have to mount the screen then with a noticable distance to the board to make it happen. Anyhow I will get it fixed.

Thanks again and have a good day

Werner

stuartpittaway, 2021-12-12:
The photo above is not a fixed one. You slide open the locking tab on the top.

The card isn't designed to be regularly removed, so no problem with the TFT screen above.

wegrei, 2021-12-12:
Oughh,

now I see. You are right I can slip / flip it open. Then it works for sure. Sorry for all the stupid questions and the confusion. Again thanks for your help.

Werner

Closed 2021-12-13.

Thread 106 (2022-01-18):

Feature request: 30A Buck-Boost converter per cell for balancing

renne, 2022-01-18:
Great Project! :smiley:

Burning over-voltage with resistors is inefficient and causes heat problems.
It cannot help with under-voltage of cells.
About 1A balancing current is to low for C1 310Ah cells.

I suggest to use some kind of a 30A Buck-Boost converter per cell connected to the main rail for balancing.
Under-voltage: step-down converter from main rail to cell
Over-voltage:  step-up converter from cell to main rail

renne, 2022-01-20:
After seeing this [video](https://www.youtube.com/watch?v=1KgcYDUvVxc&list=WL&index=120) on Youtube, it would be sensible to have a current similar to the C1 value for LiFePo cells (e.g. 300A) for real-time balancing.

stuartpittaway, 2022-01-20:
I fear that linking cells via a buck-boost converter would begin to loop/link all the cells together unless the converter was completely isolated.

How would you achieve electrical isolation between the boosts?

fhorst1, 2022-01-20:
You need to have really crappy cells to need more then 1A balance per cell.
The 250 and 400A Dali BMS have 0.08A. To give some comparison.

While burning off additional charges while the rest catches up isn't the most energy efficient way, it's power you normally would not use.

The solar charges, and balancing happen only at the top.
If there is due usage imbalance of 1A between 400Ah cell..
That would make one 399A and the other 400..
And it would take an hour to top charge with 1A to let the other cell reach 400 also.

30A is exceptional high.
Even with really crappy 456Ah (S3 152Ah) cells 1A active balancer was enough to keep things balanced.

Perhaps with speed charging and electrical cars massive balancer like this is needed.
Not for solar.

I do like the idea of active balancer (that works), a separate balancer costs about $1.25 per cell for 1A.
5A is about $3.50

It's there, it's dirt cheap, it works.
And, it doesn't bite the DIYBMS!!!
If for what ever reason the active balancer isn't capable of keeping up with the charge, the DIYBMS can burn off the top charge of the highest cells.

(And in emergency stop charging all together, where the active balancer can shift some energy between cells.)

In my humble opinion, active balancer shines at "empty" batteries.
Standard passive balance (burn off excess) is absolutely capable of keeping the pack balanced. (At top)

Whe you do need to access that last 10%... And one or more cells are dipping...
That's when active balance makes all the difference between keeping the lights on at night, or use candles.

Don't expect wonders, in low power usage modus of your home, it will make that difference....
Light or darkness...

With over 1000ah @S16 ... It won't happen fast for me.
And.... At the moment 2A active balancer does a perfect job ...

The BIYBMS is more to provide insight then really actively "work".

In your comparison...
My +1000Ah would need 100A balancer???
2A is more then enough.
1A would have been sufficient.

If you think you need 100A...
You either not yet have cells to play with, and in theory it sounds good, or you need to test your cells as 1 or 2 are to bad to be able to use and need replacement ASAP.
Bad cells can damage the whole pack.

After initial balance, no 2 cells should have 10% SOC difference in the same pack.

If you do have problems like this, no active balancer or BMS is going to fix this problem.
Replacing the cell (s) will.

fhorst1, 2022-01-20:
Thank you Renne,

First let me point out that while I like the videos Andy makes, they are
for *ENTERTAINMENT* purposes only, and Andy is playing with Lifepo4.
He is not a professional with a licence and/or degrees in electronics, and
his findings in Australia might not be the same in, let's say, Germany or
the USA.

Second, if you want to use solar, lifepo4 for household solutions, and just
buy 310AH, and are planning to "kill them" at C1 rating...
Stay away from DIYBMS, or anything DIY. It's not built for these massive
loads.

Why on earth would you even want to draw 300A?
12v 300A would deliver 3500 watt, sure, no one in their right mind would
really want to squeeze out 3500 watt on 12v.
98% of the inverters that claim they can really pull this, will provide
magic smoke if you try to pull this for an hour..
The few brands that can pull it off... well...
Let me put it this way, if you are willing to pay $5000 for that quality
inverter, you absolutely are not stopping at spending $500 for 4x 310Ah..
(roughly $125 each)

If you want to pull anything close to 3500 watt.. you do need to go to 24
or 48v
I power my whole house, 5 x air conditioning, 2000 watt deep well pump (and
3 smaller ones 200-500 watt), 2000 watt electric oven, and all the modern
goodies.
(including 24/7 mining rig of 850w)
We live off grid. While I do have 2 x 3.2kw and one 5.5kw inverter, one 3.2
is capable of running the whole show.
Yes, we would need to do some time management for the big users, we can
(and have) run weeks of one 3.2kw inverter.

Theoretically, if we connect all the energy consuming devices at full power
consumption at once, we reach 10.000 watt
Day to day basis, we almost never go above 3000. Unless we make pizza :-)
The oven @2000watt is hungry. and while scheduled not to fill the tank at
night, the deep well pump can theoretically run at the same time, plus the
mining rig, air conditioning.

This is a house for 6 people, practically never reaching 3500 watt...
Over theorising is what I did at the start also.
I made the mistake of buying the biggest available capacity at that time,
152AH, which had the same casing as the 120 ah cells.... adding 34Ah on
sheets didn't work out as planned.
Now I have 48x 152 AH bricks and am happy that we survived the fire.
Please do NOT make that same mistake. 310Ah has the same casing as the 260
and 280Ah....
You might be in for a sad surprise.
if you want to draw 3500watt, go at least 24v, better 48v.

Asking for an 30A active balancer is trying to find solutions for a badly
constructed setup.
As you don't own anything yet, I suggest you go back to the drawing board,
and rethink your design.

Most important is that you design it in a way it will fulfil your needs.
For us, living off grid, that is having power even in the rainy weeks.
That explains the +1000Ah battery (54 kwh) and 43x 335w solar, 4x800w wind,
and how we choose to use the extra capacity during the sunny months for
crypto.

For you.. only you can tell.
If you want to be able to drain the battery in one hour as UPS for servers,
that's OK. Super fast Ebike....., sure.
At higher C rates the imbalance of the cells is bigger. And that's OK.
You probably aren't going to charge the ebike in an hour, and just accept
that you will have 80% available of your capacity.
What is also normal to use, if you want to keep your battery healthy.
Lead acid (deep cycle) has only 50%...
Most people try to keep away from the top (3.65v for lifepo4) and low
(under 2.5v) so you end up using 80% anyways.

If you do need the additional 20% it's much cheaper and safer to buy 25%
extra capacity then to move energy around to try to compensate.
2A balancers already tend to get warm... inmagine what a 30A would be
like... a car heater :-)
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
renne, 2022-01-25:
We're going to power a fully electrified CO2-neutral household with 3 [Victron Multiplus II 48/5000/70](https://www.victronenergy.de/inverters-chargers/multiplus-ii) (using one already with AGM batteries + grid). 3 Multiplus II can draw up to 300A. This could happen for 15-30 minutes when cook hob (7 kW), oven (2.5 kW) and air-conditioning/heating (4 kW) are running simultaneously. Safety and durability of LiFePos (Lithium-Titanat are too expensive) makes them ideal with the exception of measuring the state-of-charge for balancing with the flat voltage curve.

I do have much more faith in open-hardware/open-source projects based on collective intelligence than in empty promises of commercial black-boxes. I would love to see a DIY BMS project for powering households.

renne, 2022-01-25:
@fhorst1 Where can you get active 5A balancers for about $3.50?

fhorst1, 2022-01-25:
:-)

I join your faith..

As I hoped to explain, 300A is not the problem.
Drawing 300A from 310Ah cell is.

With 4kw airconditioning, besides the cooking...
It's for sure you aren't going to drain 300A from 310Ah cells
Simply not enough energy storage left over for the night.

20 minutes cooking, at 7000 watt. 2.2kwh
2 X 15 minutes shower, 5000 watt
2.5kwh
Airconditioning 1500 watt for 12 hours 14 kWh
All the things I missed....
Say 20 kWh needed per night before the sun is strong enough to recharge.
48v, that's S16 310Ah
16x3.2x310= 15.8 kWh

Not even keeping in account the rainy days.

I would advise to minimal use 3 sets, and not drain 5h4 cells each night to
damaging low levels.

With this setup, I'm quite positive your AGM is around 1000Ah, at least.

With 3 sets, you drain not C1 but C0.35
At this level (300A), imbalance stays way within parameters, where an 1 or
2A active balancer is powerful enough to keep in pace.

95% of the time you are draining 2000 watt or less (probably less)

Without my crypto mining, we do about 750-1000 on average.
That's including the 2000 pumps, Airconditioning, lights.
Thailand, 25-30 at night, 35-40 daytime with peaks to 45-47.
Celsius

Yes, we don't cool the whole house 24/7.
That would need some more solar, or no crypto :-)
2 roooms are always at 25.
The rest at 30.
And real good insulated walls and roof do the rest :-)

With 3x 310... You already might get into troubles on a rainy week.
Perhaps take the jump to 4 sets.

I have tried to parallel...
It makes the world a lot more complicated.
You are absolutely free to play how ever you like.

But will end up to the same conclusion that makeing 4 individual sets, each
with own controller, and 48x DIYBMS cell monitors will work the best.

All hooked up to the backbone that you have your 3 victrons hooked up to.

I choose JiKong Active balancers, as they have BT, and provide nice
additional information.

They are high quality, only negative is that you need to be within 10
meters to read out the balancer.

Many cheaper solutions available, and most of them work.
Please put them in an enclosure/box/case as the capacitors do sometimes pop.
You don't like that close to the cells....

Let us know how the setup progresses!!

Frank

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

fhorst1, 2022-01-25:
> @fhorst1 Where can you get active 5A balancers for about $3.50?

5A active balancer for $3.50 per Cell...
S4 is $14
S8 $28
S16 $56

Jikong 1A about $80, 2A $120, 5A $350 they even have 10A for $550 or so.

https://a.aliexpress.com/_msWLku4

I'm not affiliated in any way, this is just one of many sellers.
With some searching you can find cheaper ones.
My 2A costs me $110 include transport to Thailand.

This type works (I tested the S4)
https://a.aliexpress.com/_mLJs7ic
1.2A (max) is about $4.15 for S4
(Bought locally)
My gut feeling doesn't thrust it to continue to work for 10 years...

This type works also, I did not test myself, a friend did...
https://a.aliexpress.com/_mKU0V80

He had 2 different sets, one a capacitor popped after a month.
Other one is working for 15 months now.

Both sets are same balanced...
One with, one without active balance..
(Daly 250A BMS)

renne, 2022-01-25:
@fhorst1
I just found [this](https://de.aliexpress.com/item/1005003132170432.html?gatewayAdapt=glo2deu&spm=a2g0s.8937460.0.0.61ac2e0eNcRKyf). It looks like multiple bi-directional DC/DC converters connected to a common coil.

fhorst1, 2022-01-25:
40 euro's for 10A seems to good to be true.

Sadly... It usually is, but for 40 euro...
Worth a shot.

Personally I would use 4 small 18650 lithium cells, and drain one, hook it
up and see how it goes.

If it does work....
Good find!

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

Closed 2022-01-25.

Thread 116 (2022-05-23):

Controller V4.4 - broken connection on VSPI_MOSI via

stuartpittaway, 2022-05-23:
If you have recently ordered a PCB using Gerber files between 17th May and 23rd May 2022, then there is likely to be issues with LCD and memory card working correctly.

This is fixed in board version 76eb9368da7fb189570628f82d6a8c294260fbe8 which will be marked on the PCB with the silkscreen version of "revision c8f1403" (23 May 2022)

To fix broken PCB's simply add a small wire between pin 1 on the 6 pin header (J8) and pin 2 of the LCD header (marked T_DO).

This is easy to do on the reverse of the PCB board, as shown in the picture.

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

javierolme, 2022-06-07:
Nice. Works for me.

vietxtlife, 2022-07-11:
My SD card is not working too, the board i have is around 2 years old. Should i try this fix on it?

stuartpittaway, 2022-07-11:
> My SD card is not working too, the board i have is around 2 years old. Should i try this fix on it?

No, there isn't any reporter issue with older boards. Just this particular revision.

I recommend using a low capacity and card like 1 or 2gb.

Closed 2023-07-05.

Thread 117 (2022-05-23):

Id3 Battery withe 12 cells

Michi202020, 2022-05-23:
Hello,
I am new hear in Github. My English is not the best but I hope you understand me.
I have 14 peases from this block and I will create homestorage withe your system. At this time I have install 3x6,85kwh Id3 and 2x6,85kwh.
The big problem is the wire ring from the battery to your v4. 4 board. My idea is that you can create a board from 6 cells to 16 cells and in the software you can switch on or off the Funktion how many cells are installed. For example I install on the 16 cells only the Id3 12s and the last 4 is deaktiviert. I think it's better than on the market are not enough attiny841 and one chip for 16 cells are easy to create. I have one gay more he will also build storage withe your system.
Pleas let me now what can we do or I can create the board but I need only a person what can write the code. I am not good in this.

Best Regards
Michael

fhorst1, 2022-05-24:
Dear Michael,

Each cell can function without any BMS. You do need to manually watch it
like a hawk and manage it accordingly..

DIYBMS works with 1 cell module per series set (can contain more then 1
cell in parallel)

Removing or disabling a cell module, see first comment ..
You need to do manually.

The global chip shortage hurts all sectors, including this DIY part.

Yes, they can re-invent cars to function without the chip that has
shortage, they don't.
Much cheaper, safer, more efficient is to simply wait for the chips.

Lucky for us, there are MANY different BMS available, many lower costs then
the DIYBMS.

While most lack power in the balance part (Daly does only 0.08A), an
additional balancer is cheap and widely available.

With higher capacity setups, you where already using contactors instead of
MOSFET based.

Any 10A BMS can manage 1000A installation, if you let the MOSFET of the BMS
control the contactor.
(Using a small switch to power the high capacity one)

It does not have to cost a lot.

Obviously, the design of DIYBMS didn't forsee that the widely available and
known attiny would get a shortage.

Change to different chip isn't that easy.
Change to totally different system and setup (not individual cell modules)
will take a long time and is a totally different product.

Many DIY members feel and share your pain, waiting for their backorder for
months and months.

I was "lucky" and obtained for my 4 X 280Ah sets enough attiny chips to
populate a 5th one if needed.

Yet....
As BMS is so crazy important.
I have all 4 also equipped with Jkong 2A active balancer BMS.

Redundancy is key :-)

4 X 14kwh isn't cheap and any sunny day can push a cell beyond its maximal
voltage if there is imbalance.

My motto:
Better safe than sorry.

Cheap BMS, 100A contactor and 1.2A balancer can be bought for around $40-75
(globally from Asia) (S16 setup)
DIYBMS won't be cheaper.

If you want to have the same functionality...
Professional alternative is quickly +$750,-

Re-writing the software to function with different design of PCB and/or
different chipset will take weeks, months probably. With lots of testing,
magic smoke and buckets of patience.
It's not that easy as you hope it would be.

I take this opportunity to thank Stuart for all his time and effort and all
the others in the community that helps.

Probably not the response you hoped for, it can give you the tools to
proceed (for now) without DIYBMS, and get "standard" product to protect and
use your cells.

Shortages don't last decades.

In 18-24 months there will be enough attiny available at a price of under
$1 (back to $0.80?)

Unless China goes to war also...
Then not having attiny is a minor problem :)

Frank

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

stuartpittaway, 2022-05-25:
With the existing module design having very short wires to the cells is critical.

They must also not share the same wires.

You will run into balance and voltage reading erros if this isn't followed.

Closed 2023-07-05.

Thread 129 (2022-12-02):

diybms  bypass heating function

gjonesy84, 2022-12-02:
Afternoon,

My powerwall is in situated in an outdoor building where it gets close to ambient temperatures and could do with somekind of heating.

It would be great if it had the software would allow a heating function. My other powerwall with batrium BMS has a heating function built in. See below

https://wiki.batrium.com/en/toolkit/control/thermal

Would be great to see this in the diybms :)

Cheers

Gareth

fhorst1, 2022-12-02:
While I see the additional protection as a plus, i don't feel it should be
inside DIYBMS.

Many commercial available heating pad (terrarium, or for hatching eggs)
have temperature settings.
It just needs power :-)
And doesn't do anything above the set temperature.
Terrarium pads are a few bucks on AliX, energy efficient, flat, thin,
reasonable flexibele, "water proof" (not for submerged)  the list goes on.
With this option widely available, cheap and reliable...
And the safety of the DIYBMS temperature setting if it gets more cold then
the heating pads and insulation can deal with...

If would be different when we building DIY heating pads with nichrome
wires, each wire being controlled by the cell module.

(I made some dump loads for my wind turbines, easy enough to make for that
purpose)

Nichrome isn't that easy to work with, especially for mild heating...
Bread toaster, your grill and oven..
But i doubt it is something you like in the powerwall :-)

Simple terrarium heating pads...
5 watt, €2,-
20 watt €4,-

Its hard to compete with those prices:-)
(I had a few in use to keep my grow tent on high enough temperature in a
too cold environment. They worked fine 3 winters.
Then I moved to Thailand, so no longer need.
Top "wish. Xzy " quality :-)

Just a thought :-)

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

stienman, 2022-12-02:
I'm using the older esp8266 based controller, but it had 4 relay outputs,
and I thought it had the settings to support this sort of need.  Of course,
this could be used to shut the battery off to prevent freezing related
damage during charging, but you could certainly turn on a heater instead.

Is that not the case with the ESP32 version?

As far as whether it belongs or not - thermal control for safety and
battery longevity is absolutely part of battery management, and belongs in
DiYBMS as much as anything else.  At minimum it should include the
capability of disabling charging below a set temperature, and limiting or
disabling discharge below a set temperature, if it doesn't include active
thermal management features it should at least prevent damage if the
temperature is too low.

-Adam

On Fri, Dec 2, 2022 at 8:43 AM Frank van der Horst ***@***.***>
wrote:

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

fhorst1, 2022-12-03:
Yes, thermal management in the form of a shutdown is and should be
available in the DIY BMS.

There is one rule set available for this, a d can be used to disconnect the
charge / discharge depending on your temperature setting.
(High and low)

There isn't a third option, so one needs to choose.

4 Relay, easy enough to use one to start giving electricity to a (heating
pad.

Using the BMS to control the temperature,  that's a whole different
situation.

Yes, you could use the minimal and maximal temperature setting to control.

But at the costs of the freezing and overheating control.
Who are in my opinion far more important.

If there is enough storage space to program additional rules?
I don't know.

I haven't found heating pads that don't have their own temperature control.
I'm sure they will be available at some location, or can modify the
existing ones.

The question was not so much if the DIYBMS can/should be able to protect
the too high and too low temperature for the battery, that it can.

The question is if the DIYBMS should be able to control the temperature
range, by powering a heater or cooler system.

Short answer, why?
All commercial heaters and coolers come with temperature control.

If it isn't broke, don't fix it. / Don't change a winning team... (And more
of this)

Why would you bypass the engineering from the company that you buy the
heating pad from, tested and tried and guaranteed solution, only to be able
to set a temperature yourself?

If you don't want to re-engineer the heating pad and loose warranty, I fail
to see the point.

They don't start or use electricity when the temperature is above the
setting.
They gradually increase/ reduce the wattage to stay at the set temperature.

You can and should use the temperature settings in the DIYBMS to protect
the battery from overheating and freezing.

Prevent freezing is also something that should be done if your environment
asks for it.
(Or active cooling when you live in the desert or so)

On the question if the DIYBMS should be the unit that controls the
preventive measures....

Unless the DIYBMS provide scalable solution that does this... I don't see
the need.
Different solutions are needed for 4,8,16 or larger Battery packs.
Then there is the size / mass, the insulation for the battery pack and the
temperature range in the environment.

I've witnessed -36 one time in Poland...
That needs a total different solution (wattage)
High powered heating brings it's own challenge...
Bypassing that tried and true temperature management because it needs to be
done by DIYBMS...

And it it doesn't needs to be controlled by the DIYBMS, then what is the
additional value of being able to turn on the heating pad a few degrees
warmer before it turns itself on?

Over complicating things will make additional points of failure.

The freezing and overheating protection is already available.
Just not to control prevention.
And the question is if one would really want to do this.

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

stuartpittaway, 2022-12-05:
The existing rules for "Cell under temperature (external) °C" can be used to drive multiple relays/outputs

So for example, at 0°C, the "discharge" relay could be disabled, and a "heating" relay be switched on.

When the temperature rises to the "reset value", say 5°C, the rule de-activates - so heating stops and discharge resumes.

stienman, 2022-12-05:
I thought that was the case, but it's been awhile since I opened the
configuration of my system.  Thanks!

-Adam

On Mon, Dec 5, 2022 at 6:43 AM Stuart Pittaway ***@***.***>
wrote:

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

Closed 2023-01-03.

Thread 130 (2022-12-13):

Component placement issue from JLCPCB

drawlusyk, 2022-12-13:
Hello, I placed an order with JLCPCB for boards and component placement.

Please see the included images which were provided in my order which they fixed.
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

Also, the following email content was sent after my order...

****************
Please kindly note for The Standard PCBA, if the original design has no edge rail, we will add 5mm width edge rail on 2 sides of board. So the board size will increase which will lead to price changes.

Since the difference is small, we will not charge the extra fee for you this time, please kindly pay attention about this for the future orders.
***********

stuartpittaway, 2022-12-13:
Just to add I've noticed they have INCORRECTLY rotated part D2 (diode) on the modules.  If you have already confirmed the order with JLC - DO NOT POWER ON THESE MODULES until you remove and rotate all the D2 diodes.

The + should be on the right, next to the "K" mark.

drawlusyk, 2022-12-13:
Ok. I had to place an order for the missing part ATTINY841-SSU. At the same time of placing this order, I also ordered the pcb's. They thankfully sent an email letting me know that the parts will take a few days to arrive, so they cancelled the PCB order for me. Once parts are in, I will re-order with the updates. Thanks.

stuartpittaway, 2022-12-13:
Right - the new modules won't be using the TINY841 :-)

drawlusyk, 2022-12-13:
Huh? Did I upload the wrong files? I had to order 50 of these at $2 each since they didn't have them in stock.
Before ordering i did a git pull on the dir i have diybms files in.
This is what i uploaded... diyBMSv4/ModuleV440/export/ModuleV440_bom_jlc.csv

Or are you changing components for v4.5?

stuartpittaway, 2022-12-13:
Yes, changing components - the TINY841 is difficult to get hold of, often out of stock.

stuartpittaway, 2022-12-13:
I've just uploaded the v4.5 files, feel free to use those if you want - but they need ATTINY1624 chip.

drawlusyk, 2022-12-13:
Thanks Stuart. Will upload these to JLCPCB and let you know if there are any problems.

drawlusyk, 2022-12-13:
JLCPCB is replacing the ATTINY1624-SSU-ND with is ATTINY1624-XF. Is this ok?
Still need to pre-order these but cheaper;)

N1c084, 2022-12-13:
Not the same pitch, you need to change from soic to tssop

Le mar. 13 déc. 2022 à 16:17, drawlusyk ***@***.***> a écrit :

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

stuartpittaway, 2022-12-13:
Did you see the video I just released? Shows the difference between the two.

You could always add the attiny chip on yourself (manually solder). Not difficult and likely lower cost than jlcpcb

Closed 2023-01-03.

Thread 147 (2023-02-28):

New ESP32_Devkitc_V4 ESP32-WROOM-DA GPIO2 pin not led out to the module.

cor-mt, 2023-02-28:
I have a DIYBMS CONTROLLER V4.2 from 9 May 2021 that I'm trying to get working with 8 v4.4 modules.

The first problem I ran into was a dead short to ground on my ESP-WROOM-32D's GPIO2 pin. Al the local suppliers are out of stock on them, the only model available is the "ESP-WROOM-DA" where GPIO2 and GPIO25 are used for antenna selection and not led out to the module. (P10 in data sheet)

Is there a mod that can be done to map and wire the module RX to a different pin and get the comms going? Like a mod wire between GPIO2 and GPIO35, but what code need to change? The "DA" version seem to be the new goto version, maybe future compatibility and for now a warning that it is not compatible although an ESP32_Devkitc module in the readme?

stuartpittaway, 2023-02-28:
As you mention the DIYBMS uses the DEVKIT-C module footprint/pinout.

It would be quite a change to incorporate a move to the DA version - including both hardware and software changes.

Potentially there may no longer be enough GPIO pins for running everything on the board.

Closed 2023-08-02.

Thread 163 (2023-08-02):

Addon Current shunt board issue (zero voltage and current reading)

anthonyevs, 2023-08-02:
Hi Stuart,
followed the install instructions and followed the soldering diagrams ok. Loaded the latest software onto the controller.
Got a 48v to 5vdc regulator fused for the power to the controller.
when I put the 5vdc supply onto the relay control positions the controller powers up, so i didnt think I needed to supply the controller with its own 5vdc supply as it was already powered thro the other route.
Now, with this wired in this way, all powers up, going into menu setup to activate the current shunt, set as DIY current monitor internal, saved settings, the icons pop up in tabs on top of the screen,
The problem is the current shunt isnt showing any voltage, I have put a multi meter onto the bat+ on the shunt and the neg tab and meter reads 53v which is correct as thats the battery voltage. The BMS reads 53v correctly.
So, why isnt the current monitor reading the battery voltage.
Do i need to give the controller its own 5vdc supply?
Is it important to the function of the current shunt to read the voltage, as i1ll never use it to control any relays, i`ll use the bms voltage readings for that, so if its just for reference, then i`ll not worry about it, and ignore the rules error that it creates.
Any idea what may be the issue.
Thanks.

stuartpittaway, 2023-08-04:
> when I put the 5vdc supply onto the relay control positions the controller powers up

I don't follow this - what connections are you referring to?  The controller can only get power from one of 2 sources - either the ESP32 USB socket or the 2 pin 5V power connector on the board.

stuartpittaway, 2023-08-04:
> So, why isnt the current monitor reading the battery voltage.

I need a photo or wiring diagram of how you have connected it all up.

anthonyevs, 2023-08-04:
Hi Stu
so, yes, we have put 5vdc onto the 5v 4 port power connector, neg neg 5v 5v. This connector is powering the esp32 also.

I have not connected the usb on the esp32.
The shunt is recording ah out over the last 2 days, which is only the power that the bms and shunt is taking, nothing else is connected.
I havent tried to charge or discharge the battery yet until this is resolved,
But also, i dont mind of there is an issue with the shunt recording the battery voltage, as that info is for me personally is of no use, i wont access that or use it in the rules to control the relays.
I hope this clears it up

stuartpittaway, 2023-08-07:
Hi @anthonyevs its really important that the voltage IS read by the shunt - otherwise is cannot do energy counting/metering.

This should be as simple as connecting the battery + terminal to the "+VBUS" connection on the controller.  You must ensure that the controller NEGATIVE is also connected to the negative terminal of the battery.

So run the +5V to the controller using a step down DC converter connected directly to the battery.

Avoid mains powered adapters for this.

stuartpittaway, 2023-08-11:
Hi @anthonyevs did you get this working ?

anthonyevs, 2023-08-11:
Not yet Stuart.
Ive double checked my wiring, thats all ok. Ive got 52v on a meter on the vbus to neg so confirming correct wiring.
Maybe the tiny chip isnt soldered pe4fectly on the shunt board. Can i use a meter to see if im getting voltage to the correct pin on the small chip on the shunt board? Ive had a quick look to try to trace the tracks but they dont seem too visible to positively identify where the 52v is going on the shunt board. Ill check the pcb wiring and boards diagrams later

stuartpittaway, 2023-08-11:
Here's a zoomed image.

Can I check the wiring to the shunt as well....

* The battery negative is connected to the negative on the 5V input to the controller.
* The battery POSITIVE is connected to the "VOLT BATT+" terminal marked (J5)
* The shunt is connected to J3/J4 with the J3 terminal facing the battery.

The shunt should be connected in the POSITIVE line of the battery.

The battery voltage to the chip, should be on pin 8 (third down on right hand side).

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

MenoCore, 2023-08-15:
Hi Stuart, I would like to step in here as I experience obviously the same or a similar issue.
I only get 0-reading from the shunt tiles (see picture).
In the meantime, I soldered 2 boards and 3 addon boards as I was assuming soldering issues - no luck yet.
All connections double checked several times (Batt+ to J5, shunt to J5 and J3 / power supply step down to 5V properly attached). I am lacking of further ideas, maybe you can try to help - appreciate your kind feedback!

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

stuartpittaway, 2023-08-15:
Hi @MenoCore let's get this fixed!

What version of the controller do you have?

Can you get the usb serial console from the controller? It should report if it's detected the ina chip at boot up.

MenoCore, 2023-08-15:
Hi, wow you're fast :)
I have a 4.6 board and here the log - looks good to me.

https://pastebin.com/v7NHcBDC

###
I (5535) diybms-set: Read key (inf_apitoken)
I (5539) diybms-set: Read key (inf_orgid)
I (5542) curmon: Chip=INA229, Revision=1
I (5646) diybms: Onboard/internal current monitoring chip available
I (5646) curmon: RSHUNT=0.00166667, CURRENT_LSB=0.00005722, R_SHUNT_CAL=5000
W (5648) curmon: WARNING: True Max Current Measurable 24.58 Amps
I (5654) curmon: RECALC: RSHUNT=0.00166667, CURRENT_LSB=0.00004688, R_SHUNT_CAL=4096
I (5661) curmon: uint16 v=32768
I (5664) curmon: uint16 v=32768
D (5669) diybms: Setup RS485
D (5671) diybms: Configure RS485
D (5674) diybms-hal: SetOutputState 0=153
D (5677) diybms-hal: SetOutputState 1=153
D (5680) diybms-hal: SetOutputState 2=153
D (5684) diybms-hal: SetOutputState 3=153
I (5688) diybms: ** Controller changed state from PowerUp to Stabilizing **
###

stuartpittaway, 2023-08-15:
Thanks - that looks good, the chip is detected.

Do you have a photo of the setup?

Using a multimeter - what is the voltage between J5 (VOLT+ BATT) and the "GND" connection on the 5V controller input ?

MenoCore, 2023-08-15:
Ok... my setup looks like a mess - still in trial phase ;)

52.4V - fine.

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

stuartpittaway, 2023-08-15:
Ok - on the surface, that appears to be correctly wired up.  The voltage is also correct on that pin.

Can I ask you to try the latest version of code (pre-release) - its here...
https://github.com/stuartpittaway/diyBMSv4ESP32/suites/14946646590/artifacts/852244890

MenoCore, 2023-08-15:
Unfortunately not. Hard reset, new config. No shunt measurements...

               _          __
  _|  o       |_)  |\/|  (_
 (_|  |  \/   |_)  |  |  __)
         /

CONTROLLER - ver:7af23bb5063eac4fa519c8a12f570bd3c53d52ee compiled 2023-08-09T10:31:22.729Z
ESP32 Chip model = 1, Rev 1, Cores=2, Features=50
I (35) diybms-hal: Configure I2C
I (37) diybms-hal: Scanning i2c bus
I (44) diybms-hal: Found i2c device at address 0x21
I (55) diybms-hal: Found TCA6416A
I (59) diybms: ** Controller changed state from Unknown to PowerUp **
I (60) diybms-set: nvs_flash_init
I (62) diybms-hal: CAN driver installed.  Filter=1621098496 Mask=6291455
I (65) diybms-hal: CAN driver started
I (75) diybms: LittleFS mounted, total=524288, used=139264
I (170) diybms: Mounting SD card
[   179][W][sd_diskio.cpp:516] ff_sd_initialize(): GO_IDLE_STATE failed
[   180][E][sd_diskio.cpp:802] sdcard_mount(): f_mount failed: (3) The physical drive cannot work
E (182) diybms-hal: Card mount failed

anthonyevs, 2023-08-15:
hi Stuart
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

anthonyevs, 2023-08-15:
Hi Stuart,
In my case ive found the fault, the current shunt board has blown the INA chip. It looks like there must have been abit of solder shorting the pins of the vbat+ middle pin on the IA chip and the GND pin on the INA next to the vbat+ pin (middle pin and the one below it) the top of the INA was blown off at this area.
Tonight Ive soldered a replacement shunt board onto the bms board. Double checked all pins on the INA and everywhere else for connection and shorting, all seems ok on this board.
A facebook group member kindly made the 2 boards up for me as i cannot do that level of soldering myself.
I have 6 spare INA chips (min qty order)  here (no boards), so will be trying to get this damaged one repaired with a new INA chip.
Going to test this out tomorrow.
Thanks Stuart.

stuartpittaway, 2023-08-16:
Thank you for letting me know your resolution @anthonyevs - its a shame you have a broken INA chip.  Those chips are really small and you definitely need to check for shorts on each pin using a magnifying glass or similar.

stuartpittaway, 2023-08-16:
@MenoCore the photos are not clear enough to look at the soldering on the chip - could you have a soldering issue on the INA chip?

stuartpittaway, 2023-08-16:
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

MenoCore, 2023-08-17:
Hi @stuartpittaway, really appreciate your continuous support!
Double checked everythig again and made some "macro" pics of the solder joints. Also traced the routes to the next components to make sure all are continuous and soldered properly + checked for bridges to neibor pins. All good.
I am a little frustrated and really sorry bothering you with this issue.

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

stuartpittaway, 2023-08-17:
So you have shown two different photos there one with the INA229 on the controller and the other with the add-on board.

You are NOT using both at the same time are you?

MenoCore, 2023-08-17:
That makes so much sense. I stupidly followed the build instruction for boards <=5.4 and never thought about that. LOL
Thank you, I will instantly try to rewire and let you know!

stuartpittaway, 2023-08-17:
> I will instantly try to rewire and let you know!

Just remove the board from the back of the controller!

MenoCore, 2023-08-17:
>

What do I need to attach, just load and bat+? +VBUS can be ignored?

stuartpittaway, 2023-08-17:
The on-board current shunt uses the 4 pin header (screw terminals at top of board).

Its the same connections are the add-on board - look at the bottom silkscreen text and you can see 1 pin is not used.

+VBUS is for the voltage sensing - needs to go to the battery +

MenoCore, 2023-08-17:
Perfect, now all readings are there. Case closed. Thank you so much, again!
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

anthonyevs, 2023-08-17:
just a heads up on my situation.
I attached a new shunt addon board to the bms board.
Checked with a meter for connections and shorts. all looks good.
Used a variable power supply and put 2v onto the vbatt + and board 5v gnd, all ok.
Increased voltage to 20v, all seems ok, no heating up or anything out of the way.
Going to connect it back to the battery tomorrow.
Thanks.

anthonyevs, 2023-08-18:
Hi Stuart,
can confirm the replacement addon shunt board is working perfectly.
Thank you.

Closed 2023-08-17.

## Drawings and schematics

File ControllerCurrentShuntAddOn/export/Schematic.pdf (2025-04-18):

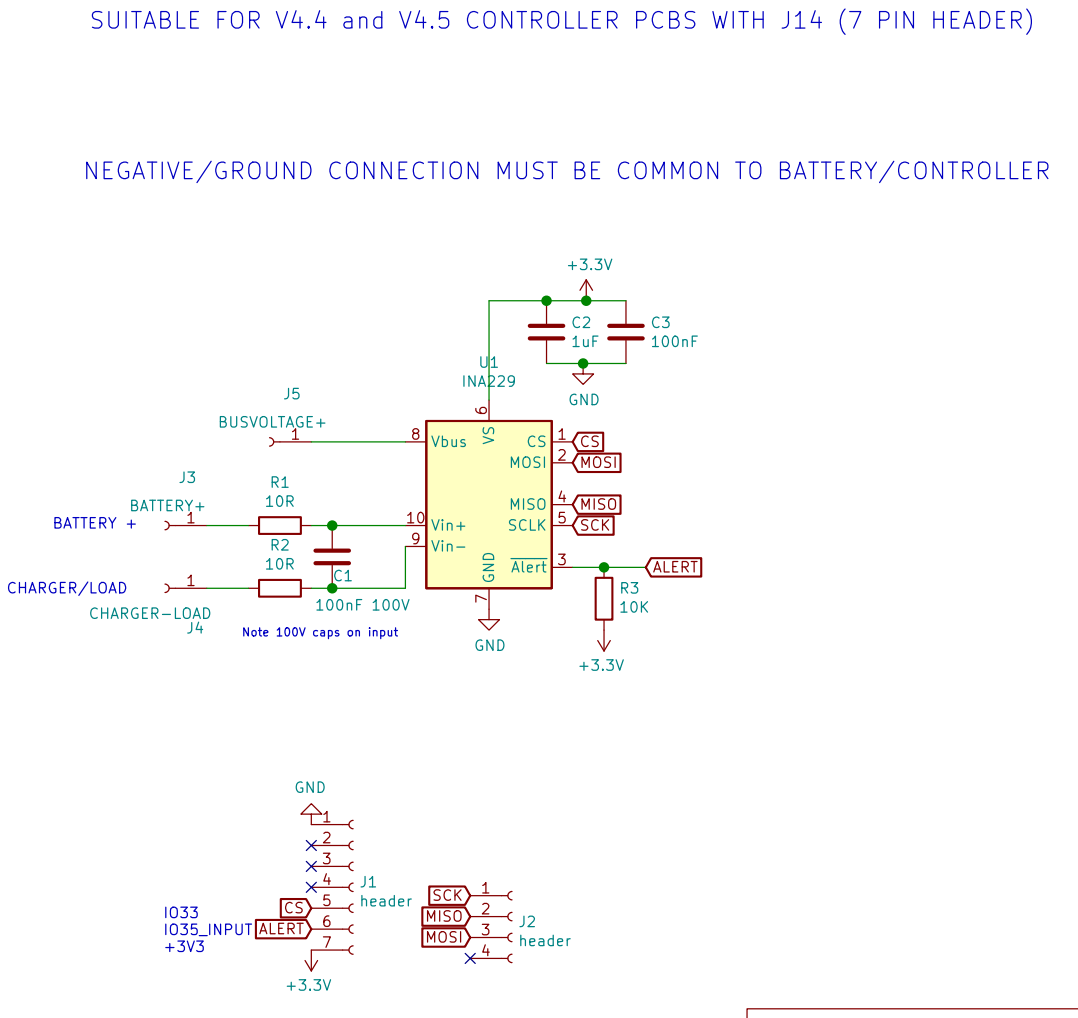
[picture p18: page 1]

+3V3 SUITABLE FOR V4.4 and V4.5 CONTROLLER PCBS WITH J14 (7 PIN HEADER)

NEGATIVE/GROUND CONNECTION MUST BE COMMON TO BATTERY/CONTROLLER

INA229
+3.3V GND GND
SCK MISO MOSI CS

Note 100V caps on input

Id: 1/1 Title: DIYBMS CONTROLLER CURRENT SHUNT DAUGHTER CARD

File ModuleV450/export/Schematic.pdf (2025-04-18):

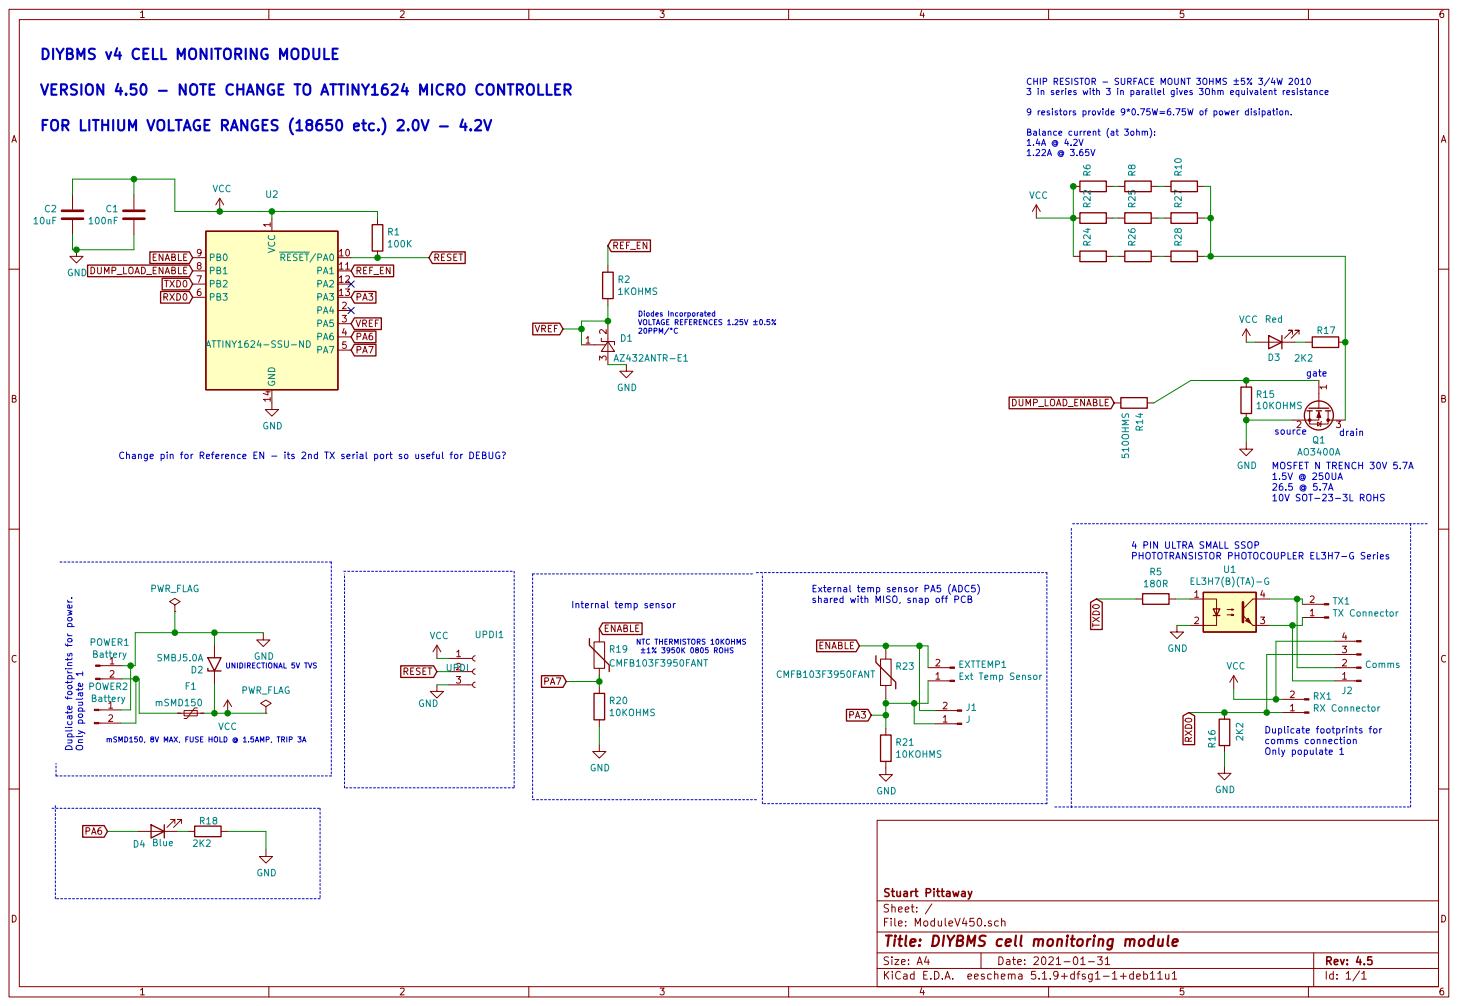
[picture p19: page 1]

DIYBMS v4 CELL MONITORING MODULE

source CHIP RESISTOR - SURFACE MOUNT 3OHMS ±5% 3/4W 2010
3 in series with 3 in parallel gives 3Ohm equivalent resistance

VERSION 4.50 - NOTE CHANGE TO ATTINY1624 MICRO CONTROLLER

9 resistors provide 9*0.75W=6.75W of power disipation. Balance current (at 3ohm): 1.4A @ 4.2V

FOR LITHIUM VOLTAGE RANGES (18650 etc.) 2.0V - 4.2V

1.22A @ 3.65V mSMD150, 8V MAX, FUSE HOLD @ 1.5AMP, TRIP 3A Duplicate footprints for power. Only populate 1

1 RESET/PA0 10 PA1 11 PA2 12 PA3 13 GND 14 PA4 2 PA5 3 PA6 4 PA7 5 PB3 6 PB2 7 PB1 8 PB0 9 U2 ATTINY1624-SSU-ND

PHOTOTRANSISTOR PHOTOCOUPLER EL3H7-G Series Change pin for Reference EN - its 2nd TX serial port so useful for DEBUG?

4 PIN ULTRA SMALL SSOP

shared with MISO, snap off PCB

Duplicate footprints for comms connection Only populate 1

File: ModuleV450.sch Sheet: / Stuart Pittaway

Id: 1/1 Title: DIYBMS cell monitoring module

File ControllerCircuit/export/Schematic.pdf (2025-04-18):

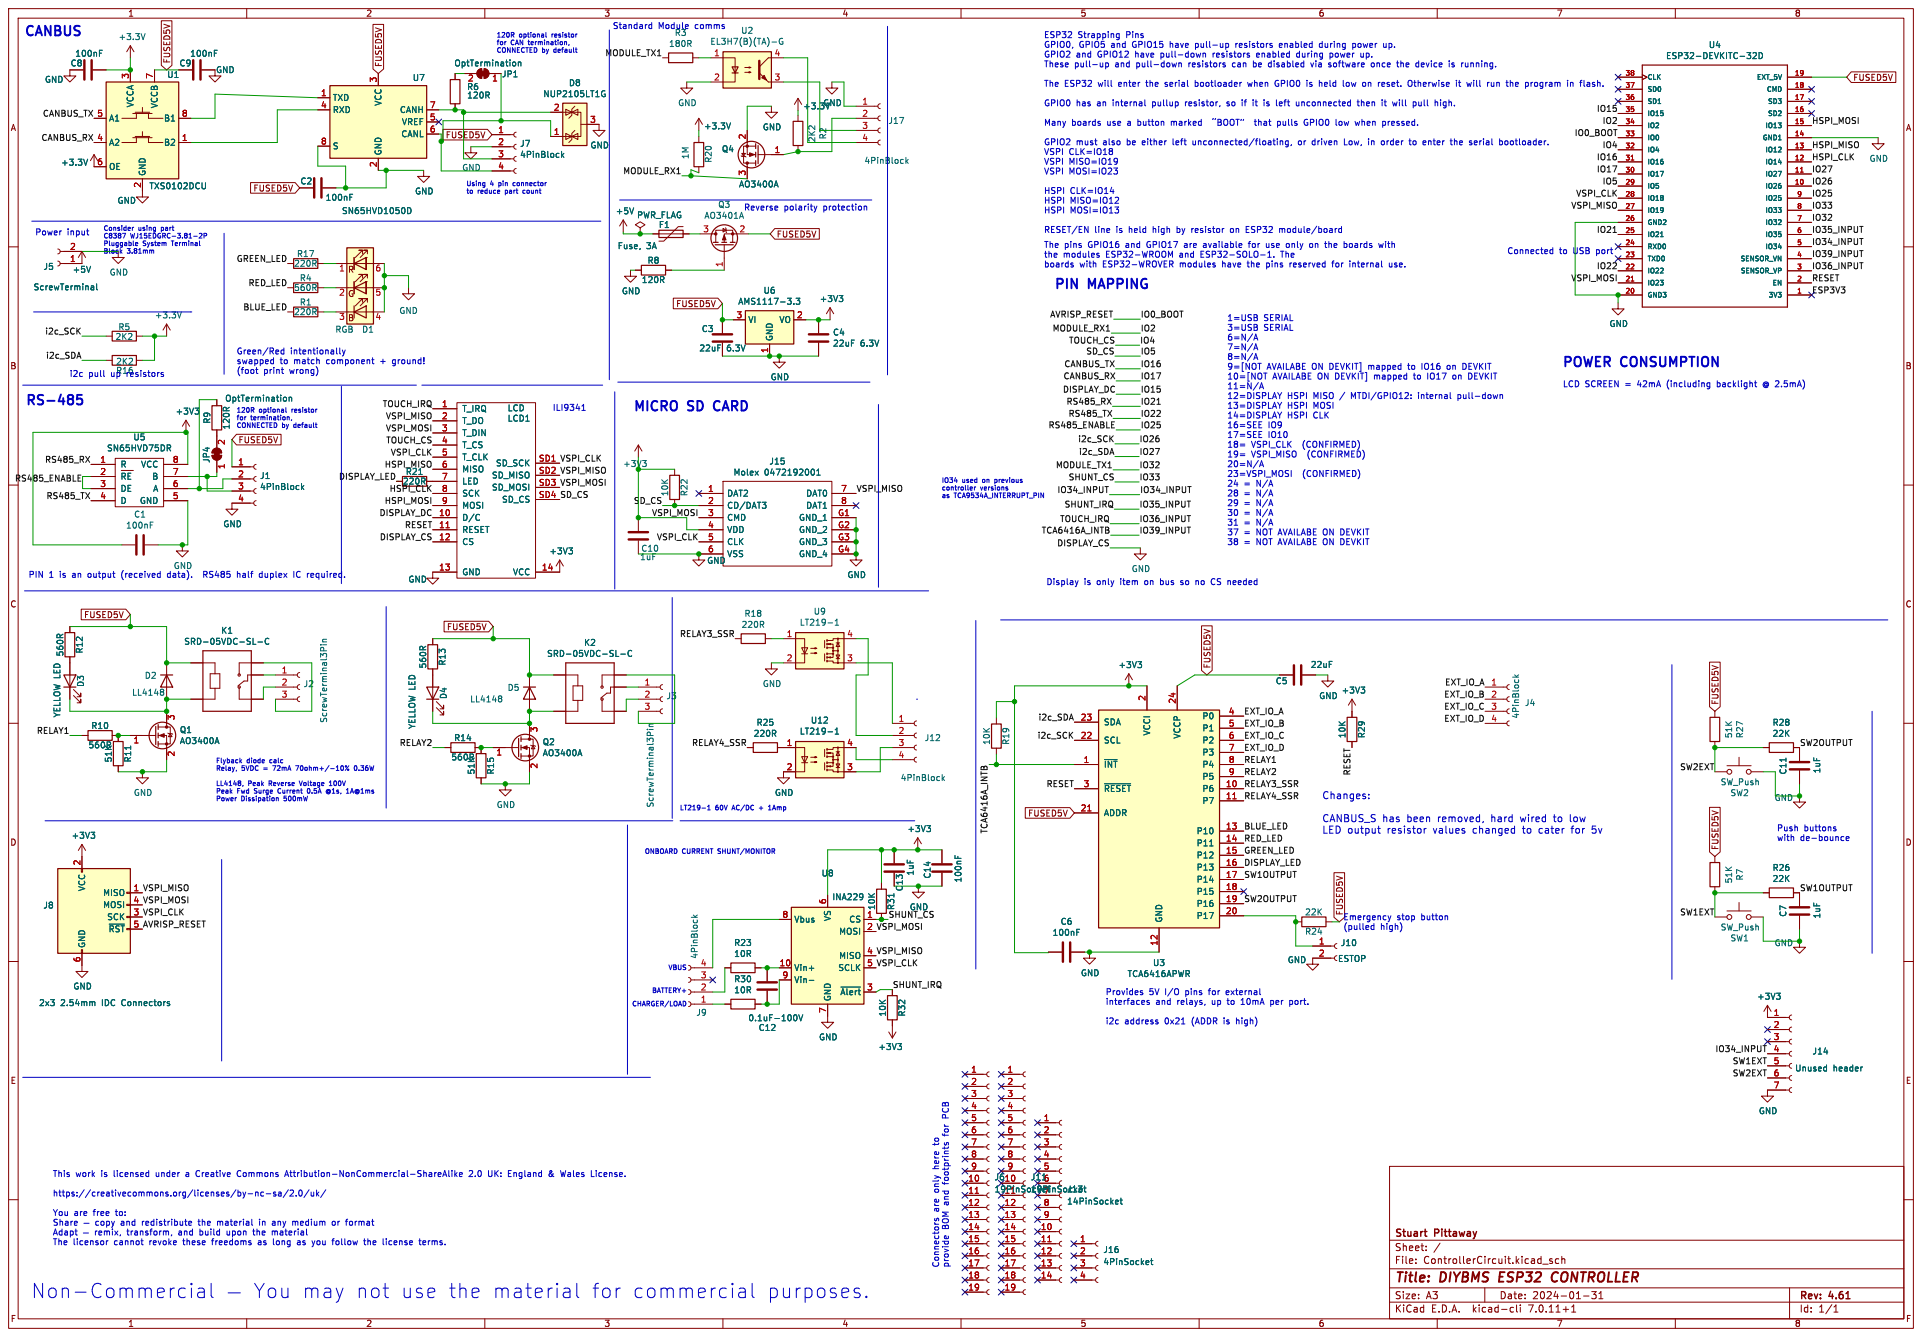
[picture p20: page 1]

3 RXD 4 VREF 5 CANL 6 CANH 7 S

Using 4 pin connector
to reduce part count

IO36_INPUT SW2OUTPUT SHUNT_CS
38 = NOT AVAILABE ON DEVKIT PIN MAPPING

3=USB SERIAL
9=[NOT AVAILABE ON DEVKIT] mapped to IO16 on DEVKIT
10=[NOT AVAILABE ON DEVKIT] mapped to IO17 on DEVKIT
13=DISPLAY HSPI MOSI 14=DISPLAY HSPI CLK

for termination, CONNECTED by default

CANBUS_S has been removed, hard wired to low

Push buttons with de-bounce ONBOARD CURRENT SHUNT/MONITOR

2 SCK 3 MOSI 4 ~{RST}5 GND

2x3 2.54mm IDC Connectors MISO VCC

i2c address 0x21 (ADDR is high)

Id: 1/1 Title: DIYBMS ESP32 CONTROLLER

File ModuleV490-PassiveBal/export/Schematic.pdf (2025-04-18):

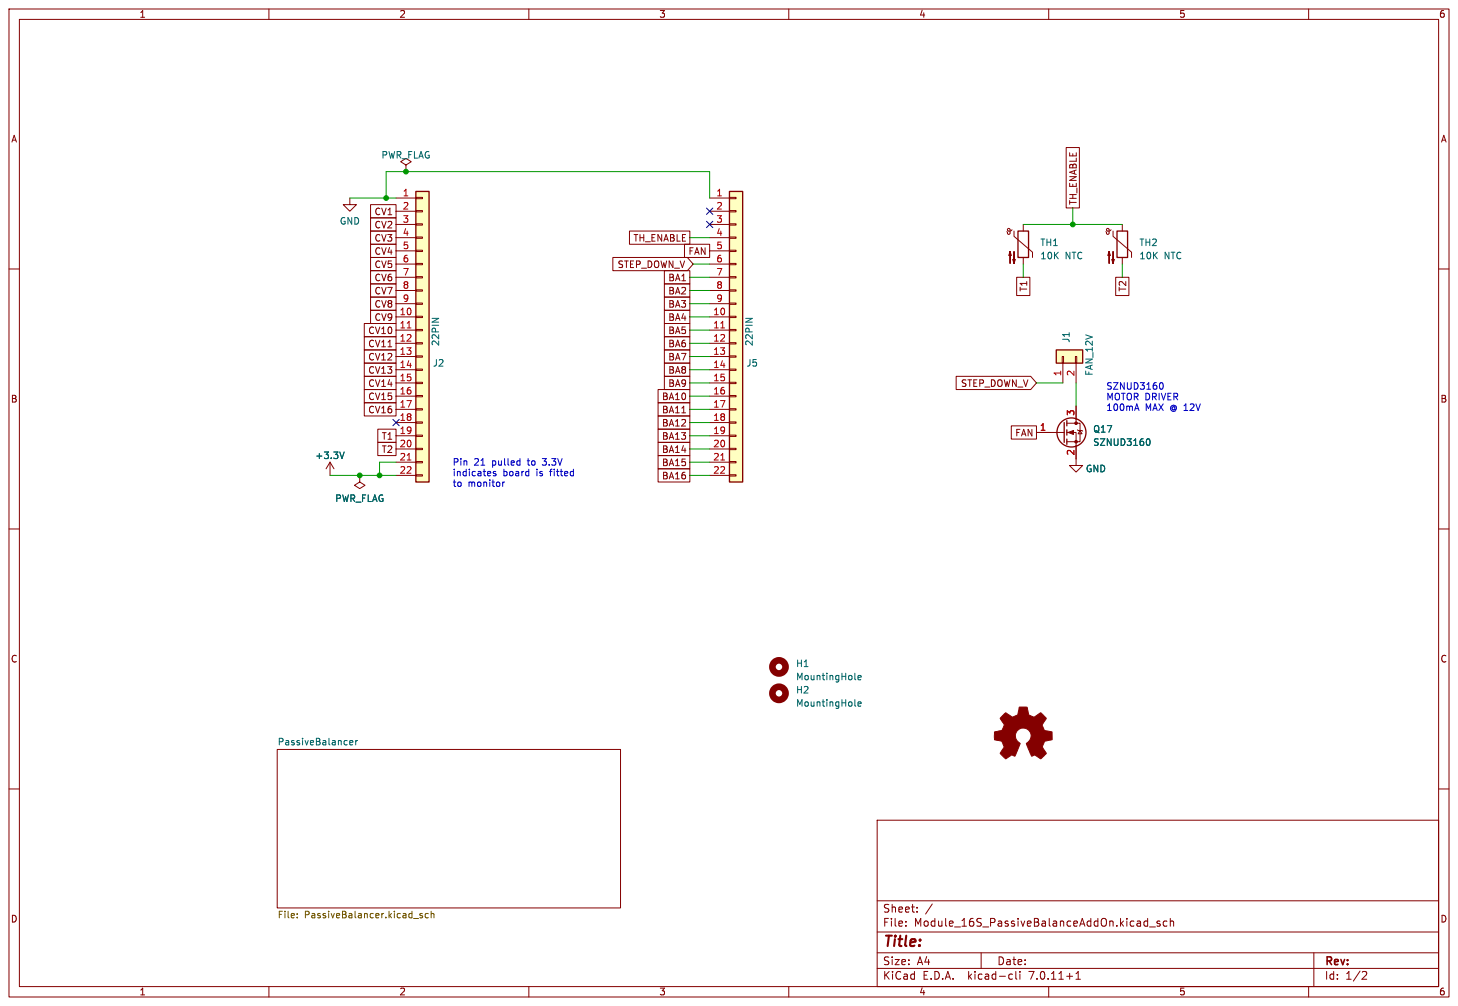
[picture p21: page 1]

Id: 1/2 Title: File: Module_16S_PassiveBalanceAddOn.kicad_sch Sheet: / PassiveBalancer File: PassiveBalancer.kicad_sch

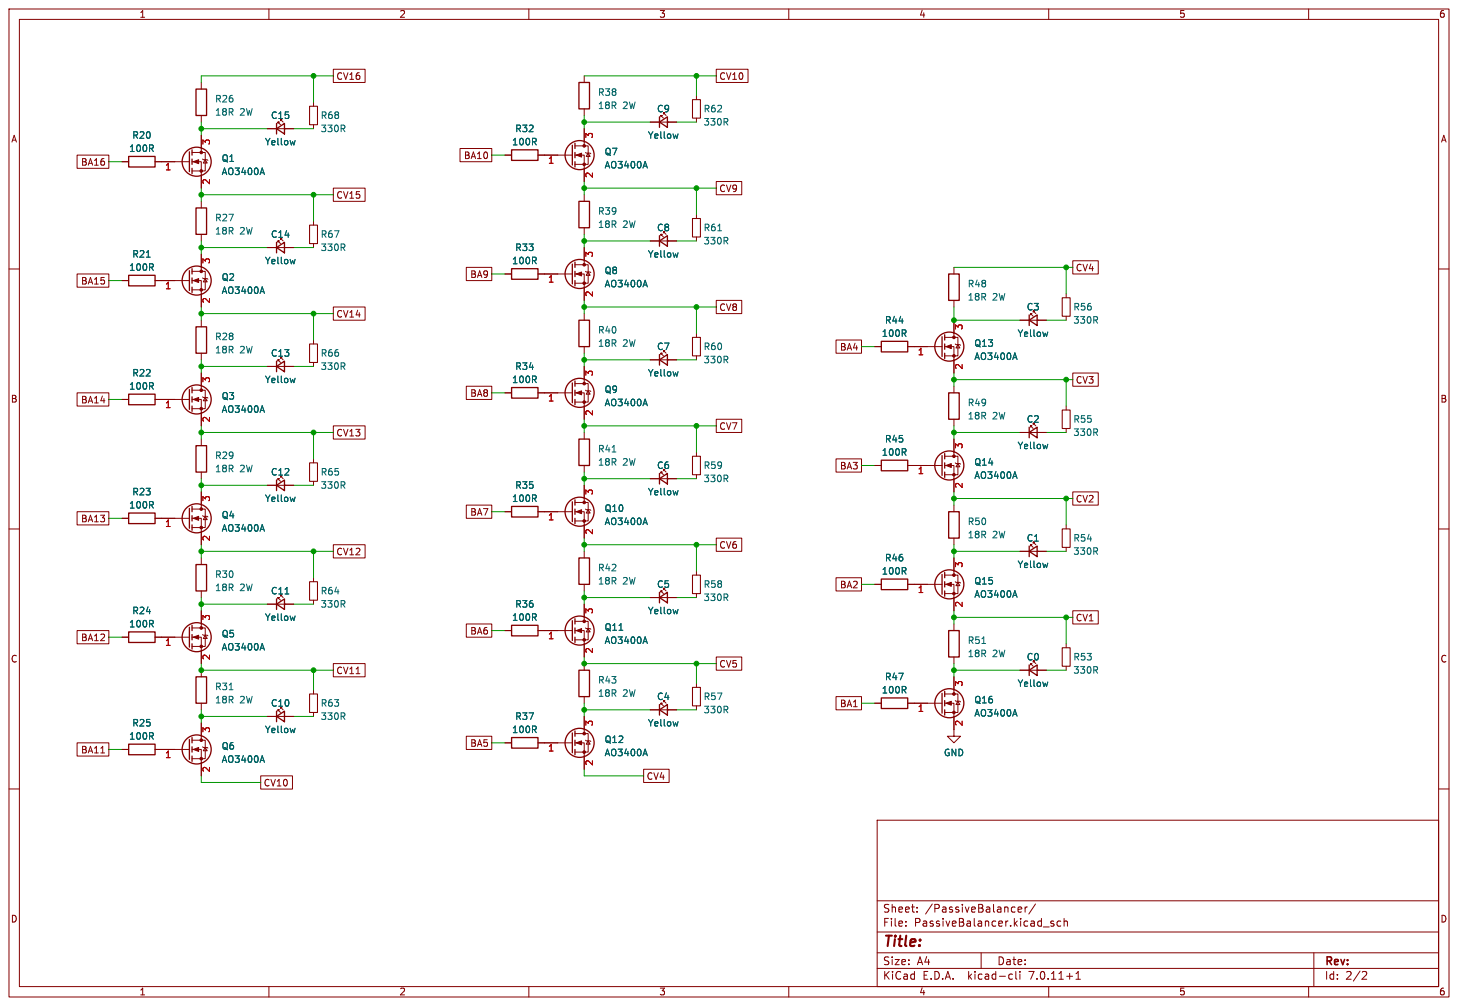
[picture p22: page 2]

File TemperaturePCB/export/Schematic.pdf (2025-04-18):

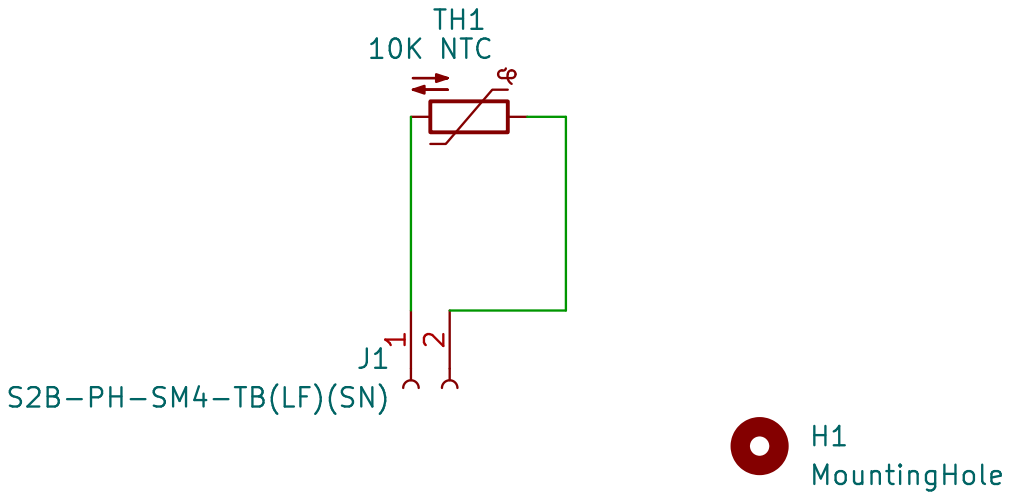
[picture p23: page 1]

Id: 1/1 Title: File: TemperaturePCB.kicad_sch Sheet: / H1 MountingHole

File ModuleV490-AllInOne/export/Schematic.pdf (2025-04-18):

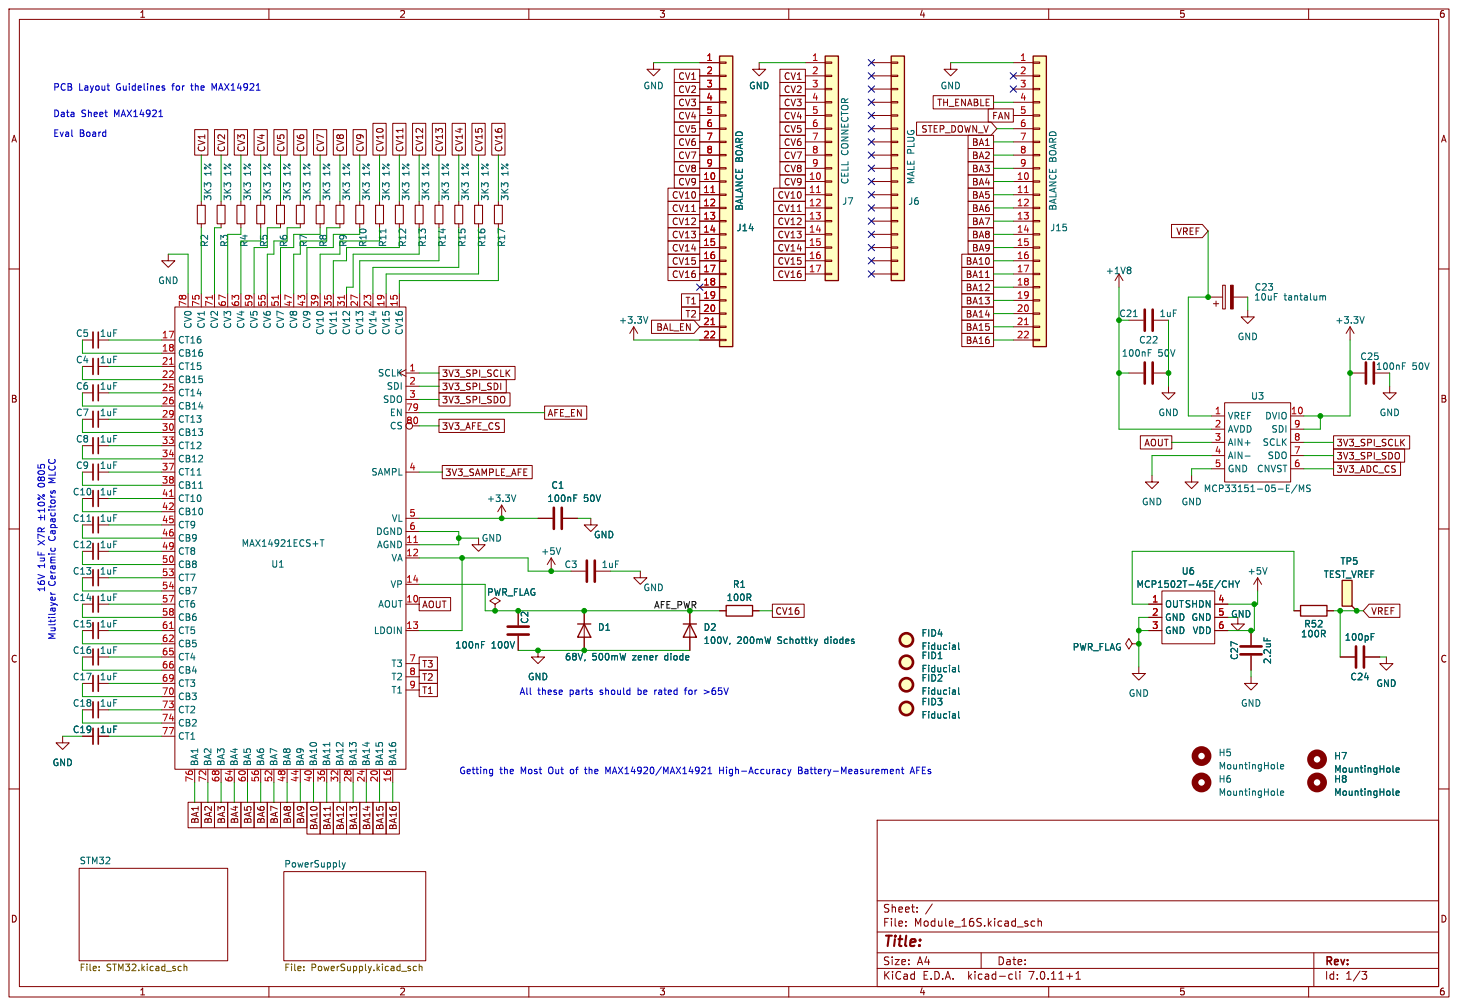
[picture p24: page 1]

FID4 Fiducial FID3 Fiducial FID2 Fiducial FID1 Fiducial D2

Id: 1/3 Title: File: Module_16S.kicad_sch Sheet: / PowerSupply File: PowerSupply.kicad_sch STM32 File: STM32.kicad_sch

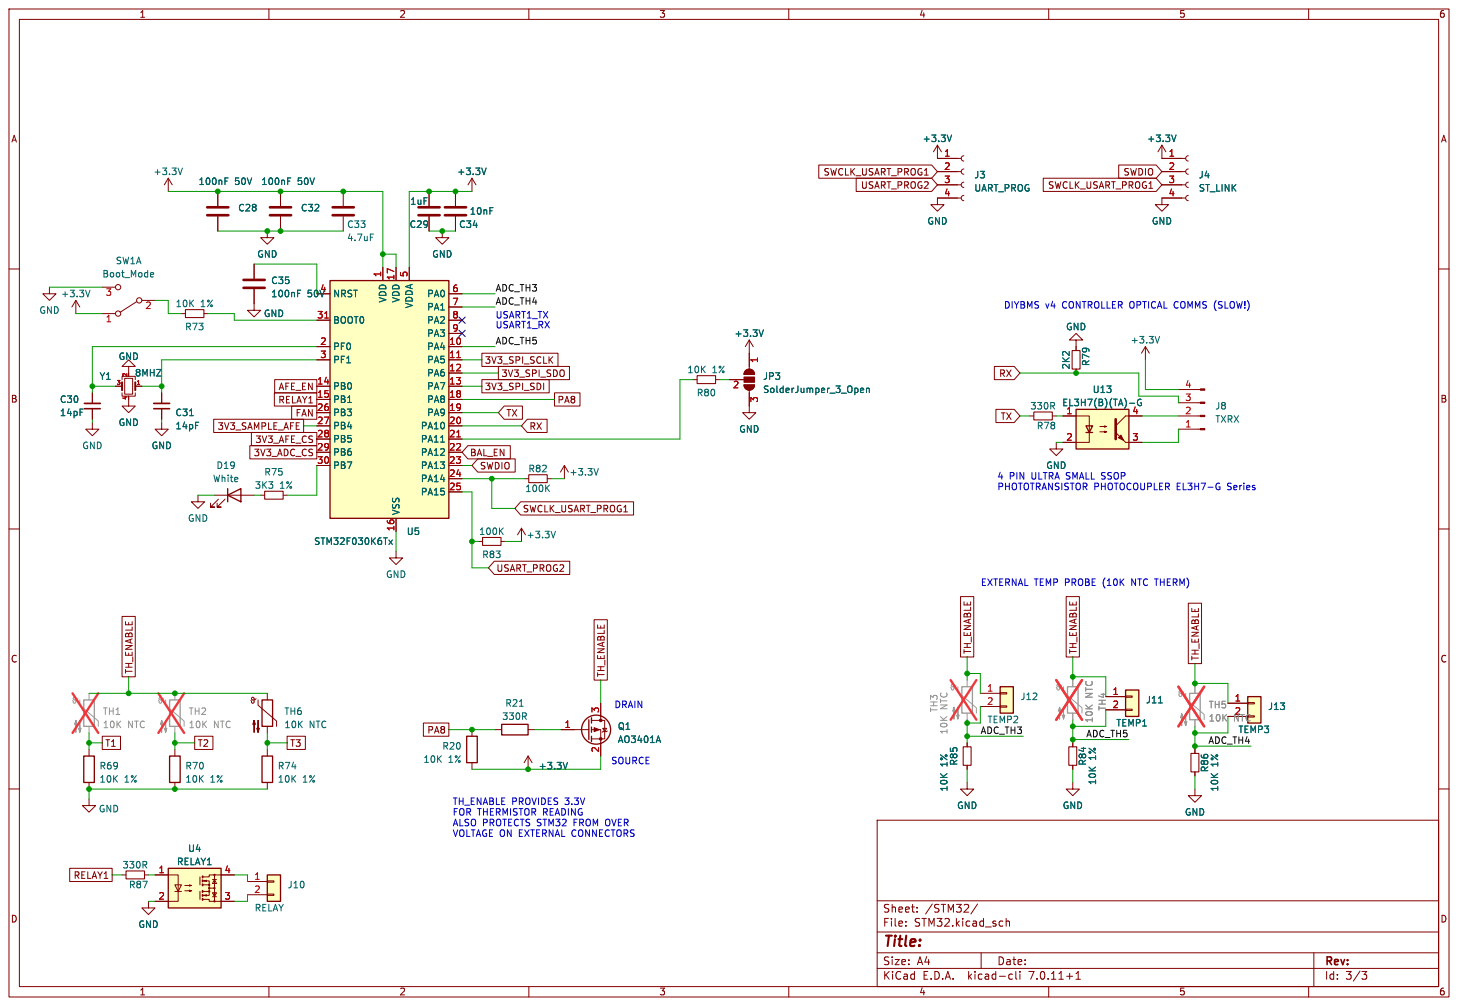
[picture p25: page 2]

1 PA4 10 PA5 11 PA6 12 PA7 13 PB0 14 PB1 15 VSS 16 VDD 17 PA8 18 PA9 19 PF0 2 PA10 20 PA11 21 PA12 22 PA13 23 PA14 24 PA15 25 PB3 26 PB4 27 PB5 28 PB6 29 PF1 3 PB7 30 BOOT0 31 NRST 4 VDDA

Id: 3/3 Title: File: STM32.kicad_sch Sheet: /STM32/ VDD

EXTERNAL TEMP PROBE (10K NTC THERM) USART1_TX
USART1_RX

4 PIN ULTRA SMALL SSOP

TH_ENABLE PROVIDES 3.3V
FOR THERMISTOR READING
ALSO PROTECTS STM32 FROM OVER
VOLTAGE ON EXTERNAL CONNECTORS

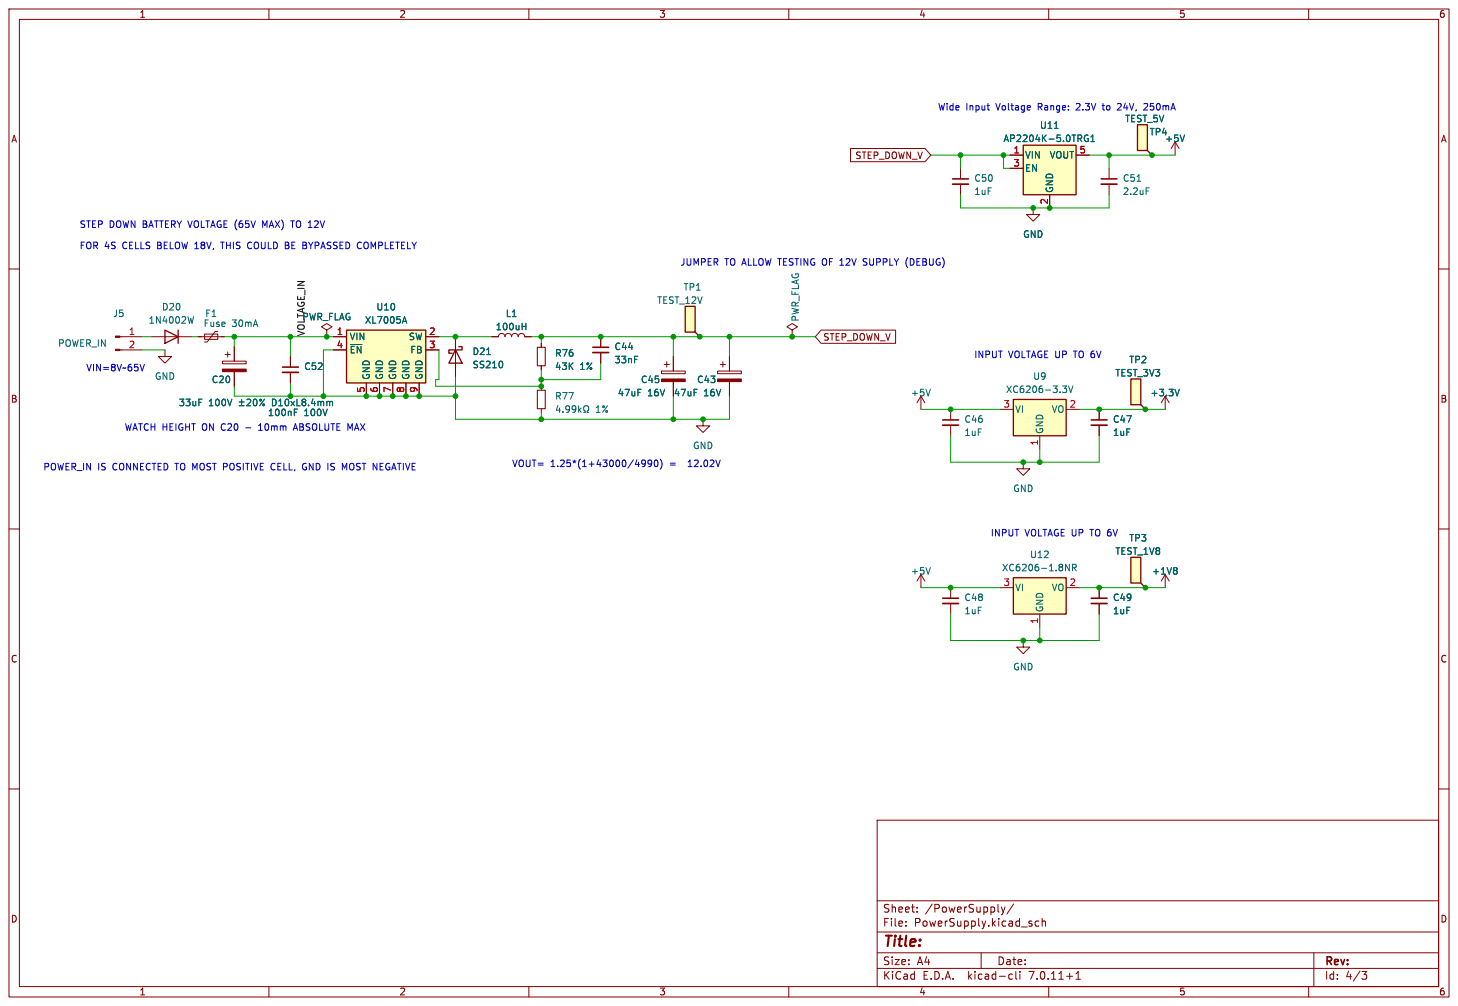
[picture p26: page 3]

INPUT VOLTAGE UP TO 6V Wide Input Voltage Range: 2.3V to 24V, 250mA C43

STEP DOWN BATTERY VOLTAGE (65V MAX) TO 12V

FOR 4S CELLS BELOW 18V, THIS COULD BE BYPASSED COMPLETELY

STEP_DOWN_V VOLTAGE_IN WATCH HEIGHT ON C20 - 10mm ABSOLUTE MAX

9 VIN 1 SW 2 FB 3 ~{EN} 4 GND

POWER_IN IS CONNECTED TO MOST POSITIVE CELL, GND IS MOST NEGATIVE

INPUT VOLTAGE UP TO 6V

Id: 4/3 Title: File: PowerSupply.kicad_sch Sheet: /PowerSupply/

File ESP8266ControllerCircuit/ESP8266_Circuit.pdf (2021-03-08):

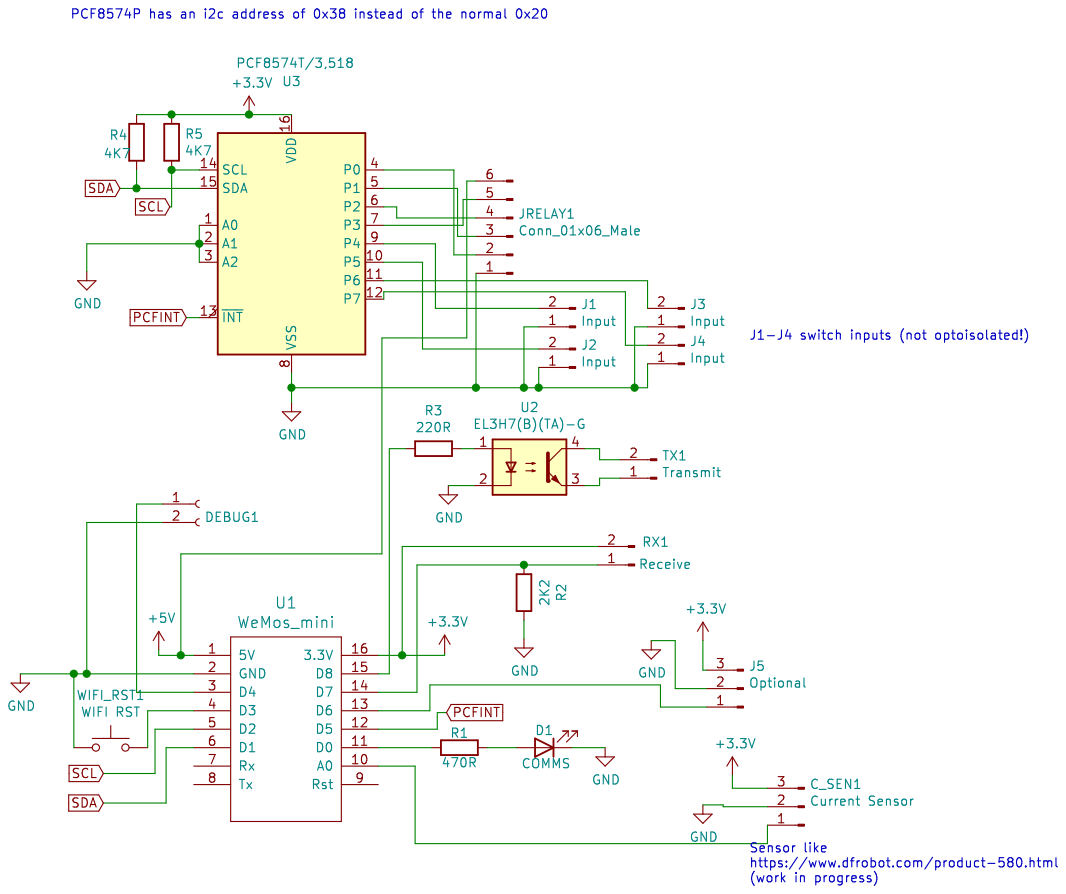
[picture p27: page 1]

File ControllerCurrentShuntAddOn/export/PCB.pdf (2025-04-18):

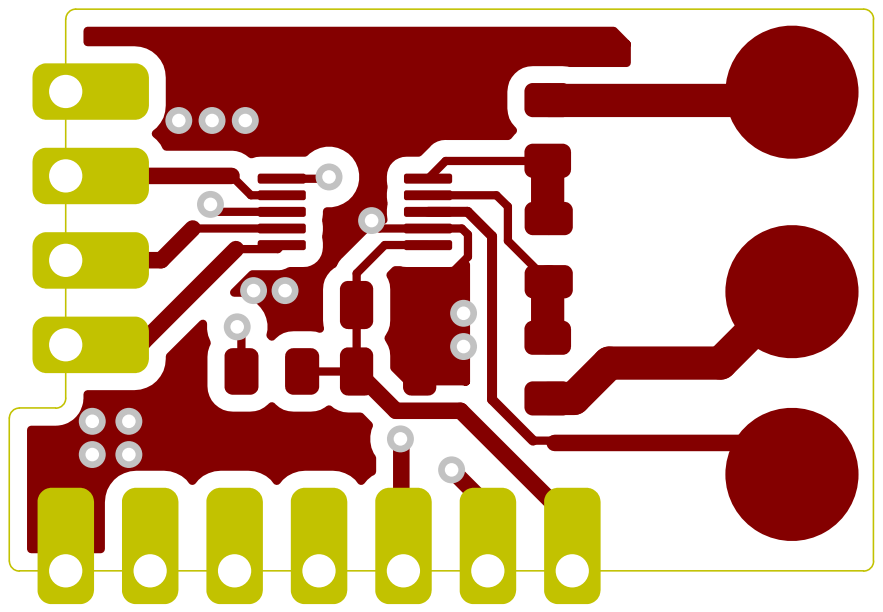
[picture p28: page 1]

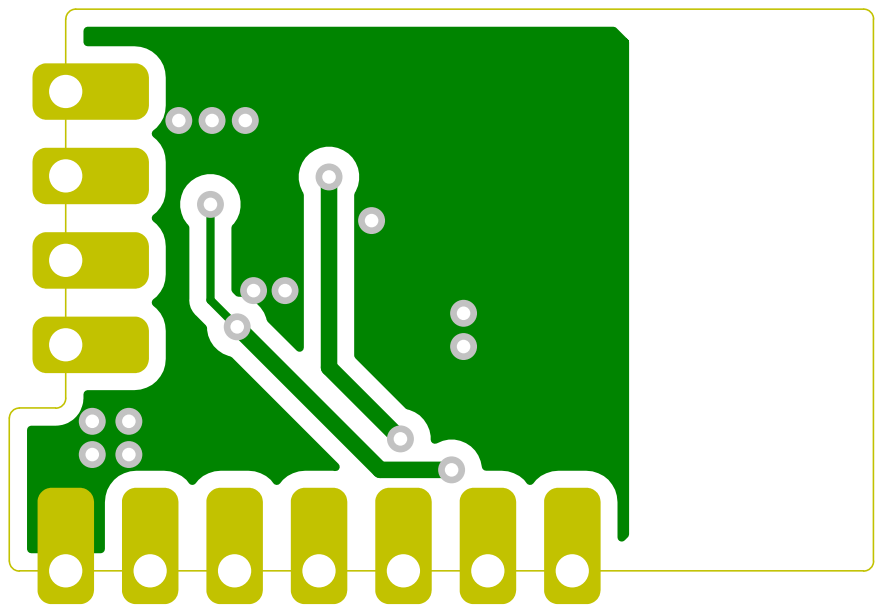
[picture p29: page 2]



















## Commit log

2019-03-26 Initial commit of circuit and gerber
    [v4-B.Cu.gbr, v4-B.Mask.gbr, v4-B.Paste.gbr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]
2019-03-28 Change Opto to HMHA2801
    [v4.kicad_pcb, v4.sch]
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2019-04-03 Reduced baud rate to 4800 to fix low voltage issue tested down to 2.1V
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2019-04-08 upgrde to kicad 5.1
    [ESPCircuit.kicad_pcb, ESPCircuit.sch, v4.sch]
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2019-04-13 Updated circuit with 510 ohm gate current limit resistor
    [v4.kicad_pcb, v4.sch]
2019-04-14 Experimental code for timer2 (timer working load resistance failing)
2019-04-14 Fixes to circuit and tidy up
    [v4.kicad_pcb]
2019-04-14 Added 10uF cap to charge MOSFET slower to prevent fast switch on currents resetting MCU
    [v4.kicad_pcb, v4.sch]
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2019-04-18 Updates to circuit design and layout
    [v4.csv, v4.kicad_pcb, v4.sch]
2019-04-18 Major tidy up and initial BOM
    [v4-B.Cu.gbr, v4-B.Mask.gbr, v4-B.SilkS.gbr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]
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2019-04-18 Added large resistor to board as optional
    [v4-B_Cu.gbr, v4-B_Mask.gbr, v4-B_Paste.gbr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]
2019-04-18 Fix pid issue
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2019-04-30 Complete rewrite of the PCB and updated Gerbers
    [v4-B_Cu.gbr, v4-B_Mask.gbr, v4-B_Paste.gbr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]
2019-04-30 Shrunk board by 2mm
    [v4-B_Cu.gbr, v4-B_Mask.gbr, v4-B_Paste.gbr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]
2019-04-30 Change of dimensions and layout board is now 30x49mm
    [v4-B_Cu.gbr, v4-B_Mask.gbr, v4-B_Paste.gbr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]
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2019-04-30 Moved red led onto dump load circuit to free up IO pin
    [v4-B_Cu.gbr, v4-B_Mask.gbr, v4-B_Paste.gbr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]
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2019-04-30 Added blue led as optional extra
    [v4-B_Cu.gbr, v4-B_Mask.gbr, v4-B_Paste.gbr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]
2019-05-02 Updated gerber zip file
    [v4-B_Cu.gbr, v4-B_Mask.gbr, v4-B_Paste.gbr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]
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2019-05-09 Controller Circuit partially complete
    [ESPControllerCircuit.kicad_pcb, ESPControllerCircuit.sch]
2019-05-13 Reduce size of curves on corners of PCB
    [v4-B_Cu.gbr, v4-B_Mask.gbr, v4-B_Paste.gbr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]
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2019-05-18 Indicator blue LED is optional, remove TP2
    [v4.sch]
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2019-05-18 Added reset error counter button
2019-05-18 End of day checkin
    [ESPControllerCircuit.kicad_pcb, ESPControllerCircuit.sch]
2019-05-19 Got i2c working for PCF8574 chip
    [ESPControllerCircuit.kicad_pcb, ESPControllerCircuit.sch]
2019-05-22 Controller module PCB design
    [ESPControllerCircuit.csv, ESPControllerCircuit.kicad_pcb, ESPControllerCircuit.sch]
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2019-05-23 Updated controller module circuit and test of PCF8574
    [ESPControllerCircuit-B_Cu.gbr, ESPControllerCircuit-B_Mask.gbr, ESPControllerCircuit-B_Paste.gbr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]
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2019-06-07 Reduced board by 10mm in width to 75mm
    [ESPControllerCircuit-B_Cu.gbr, ESPControllerCircuit-B_Mask.gbr, ESPControllerCircuit-B_Paste.gbr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]
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2019-06-23 Updated mounting holes to 3.2mm
    [v4-B_Cu.gbr, v4-B_Mask.gbr, v4-B_Paste.gbr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]
2019-06-23 Change to PCF8574 model
    [ESPControllerCircuit.kicad_pcb, ESPControllerCircuit.sch]
2019-07-01 Bill Of Material for LCSC
    [CellModules_LCSC_BillOfMaterials.xlsx, v4.csv, v4.sch]
2019-07-09 Added missing library files for KiCAD
2019-09-18 Updated BOM with replaced out of stock products
    [CellModules_LCSC_BillOfMaterials.xlsx]
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2019-11-23 Implement fix for issue #5 and new emergency stop feature (connector j1)
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2019-11-25 Code for pulsed relay output on rule processing. Note this only makes sense if the default for the relay is OFF so power on fail safe is OFF
2019-11-28 Resolve issue with comms error message warning on larger battery banks
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2019-12-04 Footprint Position (.pos) File
    Issue #12
    [v4-top-pos.csv]
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2019-12-07 Disable wifi on power up to fix connection issues
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2020-01-02 Added PCB PDF diagram
    [v4.kicad_pcb]
2020-02-17 Change R5 to 220ohm instead of 510ohm
    Change R5 to 220ohm instead of 510ohm to increase the current applied to the optoisolator
    [v4.csv, v4.kicad_pcb, v4.sch]
2020-03-15 Update KICAD to version 5.1.5
    No board changes
    [ESPControllerCircuit.sch, v4.kicad_pcb, v4.sch]
2021-01-16 Change R2 to 2k2 from 4k7 to improve comms performance on noisy lines
    [ESPControllerCircuit.sch]
2021-02-24 New folder structure (#67)
    * Change structure of the folders
    * ESP32 controller initial commit
    [CellModules_LCSC_BillOfMaterials.xlsx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]
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2021-02-25 Added Patrick Murphy to silkscreen Patreon list
    [ControllerCircuit-B_Cu.gbr, ControllerCircuit-B_Mask.gbr, ControllerCircuit-B_Paste.gbr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]
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2021-02-25 Remove optional parts from BOM and CPL files
    [ControllerCircuit_bom_jlc.csv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]
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2021-02-28 Release of V4.40 module hardware/design (#68)
    * Update ModuleV440.kicad_pcb
    [ModuleV440-B_Adhes.gbr, ModuleV440-B_Cu.gbr, ModuleV440-B_Mask.gbr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]
2021-03-04 Change resistor physical size to upgrade to 3/4W power rating (#70)
    [ModuleV440-B_Adhes.gbr, ModuleV440-B_Cu.gbr, ModuleV440-B_Mask.gbr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]
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2021-03-11 Prevent D2 being rotated
    [ModuleV440.csv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]
2021-03-11 Prevent D2 being rotated (#74)
    [ModuleV440.csv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]
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2021-03-19 Increased slot cut width to reduce JLC warnings
    [ModuleV440-B_Adhes.gbr, ModuleV440-B_Cu.gbr, ModuleV440-B_Mask.gbr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]
2021-04-08 Fix for issue #78 use TCA6408APWR
    [ControllerCircuit-B_Cu.gbr, ControllerCircuit-B_Mask.gbr, ControllerCircuit-B_Paste.gbr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]
2021-04-14 Update R14 510ohm resistor part number (JLCPCB) (#80)
    [ModuleV440.csv, ModuleV440.sch, ModuleV440_bom_jlc.csv]
2021-05-09 Changes R16 to 2.2K to match controller board
    Changed part on R14 to basic JLCPCB part rather than extended
    [ModuleV440-B_Adhes.gbr, ModuleV440-B_Cu.gbr, ModuleV440-B_Mask.gbr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]
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2021-05-09 Swap to TJA1057GT/3 instead of TJA1051T/3
    [ControllerCircuit.kicad_pcb, ControllerCircuit_bom_jlc.csv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]
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2021-05-20 U2 wrong orientation (#84)
    * U2 wrong orientation
    Changed orientation of the U2 to 90°
    * Update ESP8266ControllerCircuit_cpl_jlc.csv
    [ESP8266ControllerCircuit_cpl_jlc.csv]
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2022-05-12 Updated controller PCB with TCA6416 chip (#115)
    * V4.3 changes
    * CI: pcb-artifacts-esp32-controller
    * Smaller footprint for fuse
    * CI: pcb-artifacts-esp32-controller
    * Remove STEP file output
    * Automate gerbers for V4.40 modules
    * CI: pcb-artifacts-module440
    * Rotate diode for KIBOT
    * CI: pcb-artifacts-module440
    * Update README.md
    * Remove automatically generated files
    * Fix rotation of U12 and U9 #83
    * CI: pcb-artifacts-esp32-controller
    * Changes to TCA chip (experimental)
    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
    [ControllerCircuit-bom.csv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]
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2022-05-23 Fix VIA for VSPI_MISO
    [ControllerCircuit.kicad_pcb]
2022-12-13 V450 module (#131)
    * New V450 module hardware TINYAVR2
    [ControllerCircuit.sch, ModuleV450-bom.csv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]
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2023-01-11 PCB Controller version 4.5 (#140)
    * CAN chip replacement
    * Change thermal relief on ground pins
    * Change solid state relays to AQY282SX, remove i2c debug pins
    * Added dual footprint for LED
    * Minor changes for thermal pad connections on screw terminals
    * Correct MHPC3528 footprint
    [ControllerCircuit-bom.csv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]
2023-01-11 Fix rotation of C3/C4/U1
    [ControllerCircuit_cpl_jlc.csv]
2023-01-19 Removed optional part D6 to avoid duplicate LEDs, update NUP part to C2976509
    [ControllerCircuit_bom_jlc.csv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]
2023-01-23 Updated C3/C4 to use 22uF 6.3V part C110786/TC212A226K006Y
    [ControllerCircuit.sch]
2023-01-23 Fix rotation
    [ControllerCircuit_bom_jlc.csv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]
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2023-04-13 V4.6 (#153)
    * Update ControllerCircuit.kicad_pcb
    * Update ControllerCircuit.sch
    * Added pull up for CS line on SD CARD. Power input down to 2 pin socket
    * Added current shunt to pcb
    * Bridge 120ohm termination resistors by default
    * Fix c3/c4/u1 rotation
    * Update config-2layer.kibot.yaml
    * Update pcb-artifacts-esp32-controller.yaml
    * Tidy up part names
    * Tidied up silkscreen labels
    * MHPC3528CRGBCT is optional
    * Update ControllerC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
    [ControllerCircuit-bom.csv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]
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2023-10-14 16S monitor "All in one" (#171)
    First release of the 16S monitoring board
    [Module_16S-bom.csv, Module_16S.kicad_sch, Module_16S_PassiveBalanceAddOn-bom.csv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]
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2023-10-18 Change part number on LCSC for F1/Fuse #172
    [PowerSupply.kicad_sch]
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2023-10-26 Correct datasheet PDF link
    [PowerSupply.kicad_sch]
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2025-04-18 Squashed commit of the following:
    commit 382df4b7a104fb34cc4a4da3f786b21ade19fcd5
    Author: GitHub Action <action@github.com>
    Date: Fri Apr 18 11:47:05 2025 +0000
    CI: pcb-artifacts-ModuleV490-AllInOne
    commit b35cb7a0d3894cf57b33edb037eb829bc9ec5ea4
    Author: Stuart Pittaway <1201909+stuartpittaway@users.noreply.github.com>
    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
    [ControllerCircuit-bom.csv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]
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
